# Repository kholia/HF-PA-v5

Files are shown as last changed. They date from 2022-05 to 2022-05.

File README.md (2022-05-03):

### HF-PA-v5

VU3CER's Robust `Class-D HF PA` for https://github.com/kholia/Easy-Digital-Beacons-v1
project for 40-20-17-15-10 bands.

For extra fun, use this PA with https://github.com/kholia/HF-Balcony-Antenna-System.

This design aspires to be the standard mW-to-QRP-Gallon HF PA in the ~600 INR
(8 USD) design space. Well, it does much more than QRP now...

Design Constraints:

- PCB is to be homebrewed.

- Only one PCB layer (side) is available for routing work.

- IRF510 MOSFET needs to be on an edge to allow usage of heatsinks.

- Typical external linears (e.g. `PA150 HF Linear Amp`) need 2W minimum to
  function. So we need a minimum of 2W of RF output from our design. Even at
  28 MHz.

- Minimal part count is strongly preferred. Low cost, and ease of availability
  are strong driving and deciding factors.

  The cost of this entire HF-PA-v5 system is less than one RD16HHF1 MOSFET ;)

- Reproducibility is a MUST! We focus a lot on this aspect by documenting each,
  and every detail possible.

- Repairability in the field is a MUST!

  Dhiru's finding: Repairing homebrewed PCBs is so much easier, and fun than
  reworking commercial `lead-free` PTH PCBs.

- No moving mechanical parts are allowed in the design - this rules out usage
  of (failure-prone) active cooling options like fans.

- We do NOT like the robustness of QCX, QDX, uSDX PAs. Removing heat from TO-92
  devices in a reliable way is not a trivial problem.

Note 0: All screenshots are clickable and zoomable.

Input: Few milliwatts is fine. Note: Si5351's output is around 8-10mW.

Output: See https://github.com/kholia/HF-PA-v4 for results.

Note 1: The output power is software controllable (via `PWM grounding`) for
flexibility.

Note 2: The idea behind making these (and my other) design notes publicly
available is to deliver REPRODUCIBLE, flexible, home-brewable, standardized,
reasonable, and cost-effective solutions for some common problems. I include
many references, simulations, and notes in my projects to enable you to do your
own (better) designs - do share them ;)

Robustness Notes:

- Ensure that the IRF510 is fastened securely to the heat sink.

  Use lock washers, and thermal epoxy adhesive to ensure good mechanical
  contact.

- We recommend operating at 24v instead of >= 29v.

Please see the older https://github.com/kholia/HF-PA-v2 project for the
power-supply (over-current protected), and LPF designs.

Schematic:

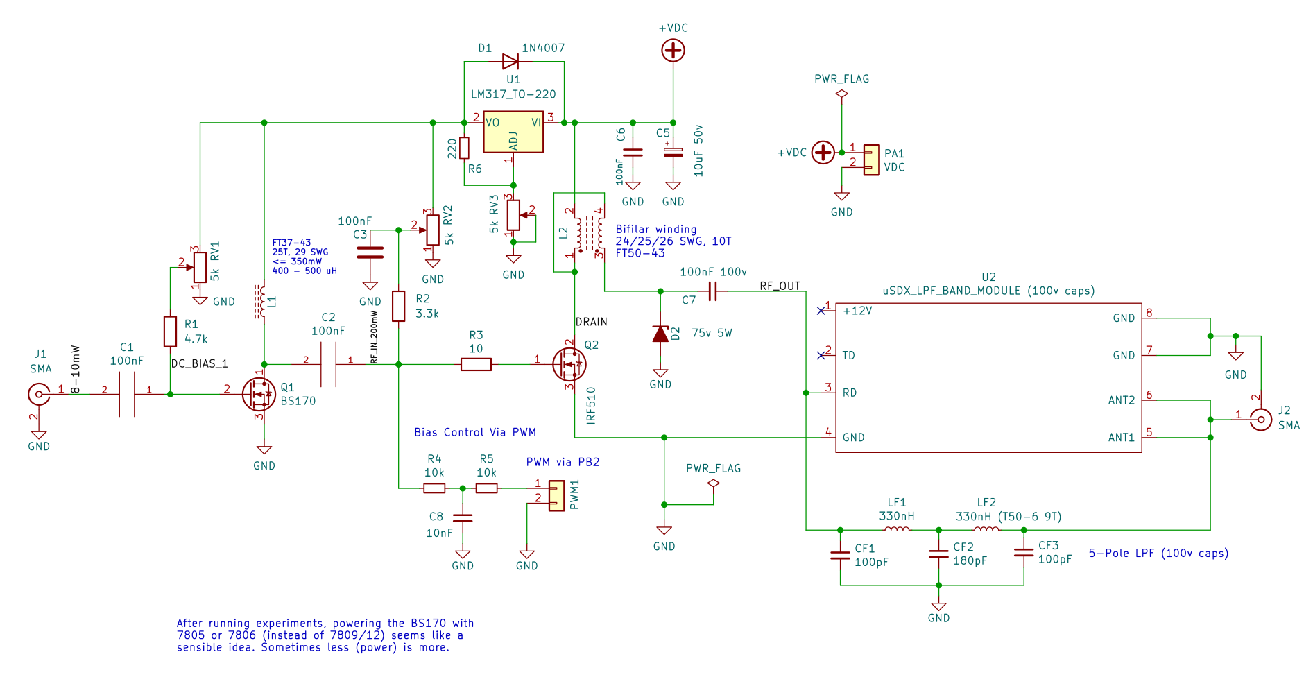
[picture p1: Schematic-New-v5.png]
Schematic


PCB rendering (v5):

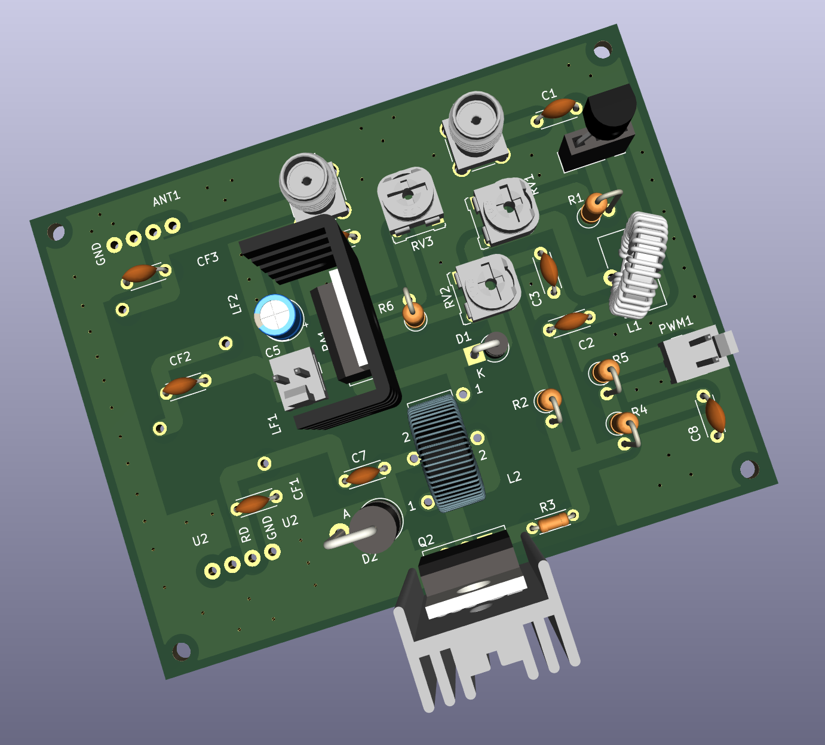
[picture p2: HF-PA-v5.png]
HF-PA-v5


Homebrew version of the same PCB:

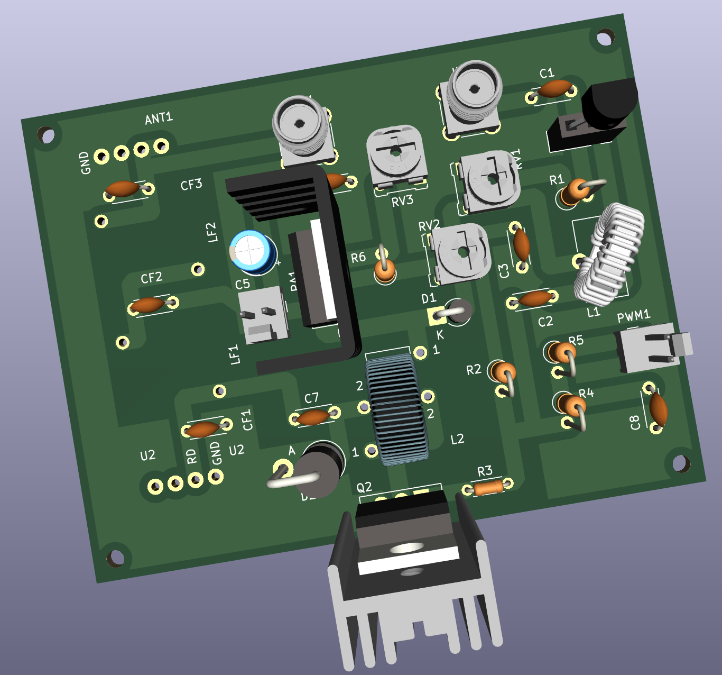
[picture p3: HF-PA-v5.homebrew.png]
HF-PA-v5 Homebrew Version


Note 3: The HF PA is connected to a 20m dipole over 55 meters of HLF-200 coax.

Note 4: The PCB is done using [KiCad 6.x](https://www.kicad.org/download/) - a
free, and open EDA software.

Note 5: This PA can be homebrewed from scratch in around 4 to 6 hours (one
afternoon, and an evening).

#### Notes

[From QRP Labs] Si5351A outputs a 3.3v square wave. The power output of Si5351A
is around 8-10mW (10 dBm). The BS170 based driver circuit amplifies this to
~200mW (23 dBm) for a gain of around 13 dB. The IRF510 finals provide a gain of
around 14dB and produce around 5W of RF power.

Input drive matters the most in getting good RF output from IRF510. This is
precisely what Si5351A lacks (which is perfectly fine), and why the BS170
driver stage is necessary.

Important: Don't exceed the IRF510's gate limit of 1-2W. Keep the output of the
BS170 driver in check, and within the limits of IRF510.

For safety, keep the output of BS170 less than 22 or 23 Vpp by controlling the
BS170 PA voltage (via the LM317 trimpot).

#### PA tuning process

- Remove the BS170 and IRF510 MOSFETS from their sockets.

- Set DC gate bias for BS170 to 0v. Now increase the bias (via trimpot) until
  the current consumption increases slightly (QRP Labs' process).

  You can also start by setting the gate bias to 2v directly ;)

  The final bias value can be around 2.1v to 2.2v in many cases.

- For IRF510, set gate bias to 3v. This ensures that IRF510 isn't turned ON -
  double-check this by monitoring the power consumption.

- Connect the MOSFET back, and measure RF output. Happy with the output power? -
  If yes, you are done else follow the next steps.

- Remove the MOSFET, increase the gate bias voltage in very small increments
  (0.1v types).

- Connect the MOSFET back, and measure power consumption without any RF input.
  Ensure that MOSFET remains OFF without any RF input.

- Apply RF input, and measure RF output.

- Repeat these steps as needed.

The [QRP Labs' procedure for bias adjustment](https://www.qrp-labs.com/images/pa/pa_simple_assembly_A4.pdf) and [this document](https://www.qrp-labs.com/images/ultimate3s/assembly_u3s.pdf) seem to have a better description of this process.

#### PA BOM

- 1 x IRF510 (Genuine Vishay parts are tried-and-tested) - 22 to 50 INR

  - The `SEC` (`SEC Electronics Inc`) branded IRF510(s) also work great!

  - The `SEC IRF510` can perform even better than Vishay's version. This
    particular result will vary between different product batches.

  - IRF510s with `International Rectifier` branding are most likely fake or
    "new old stock" if you are very lucky!

    Note: IR and Infineon have stopped manufacturing IRF510 MOSFETs.

  - AliExpress IRF510(s) are likely to be fake

  - The IR IRF510 gave ~3W versus 5.2W+ from SEC IRF510 versus ~5W from
    Vishay's IRF510!

    Note: The gate threshold voltage can vary even between two samples picked
    from the same manufacturer!

  - The Cgs ("gate capacitance") of a fake IRF510 is typically more than 1000pF
    on a LCR-T4 meter. This value is around ~400pF for genuine IRF510 parts on
    a LCR-T4 meter.

  - Some of the fake IRF510(s) cause a short in the power supply chain
    resulting in bad things happening (TM).

    I was not aware of this problem a few years ago, and was wondering why the
    power supply fuse was blowing in a uBITX I was repairing. I didn't have the
    LCR-T4 meter back then.

  - Ensure proper sourcing (trusted supply chain, etc) to get genuine parts

- All resistors should be MFR!

- BS170 MOSFET - 9 to 15 INR

- 3 x 4.7k Preset (Potentiometer) RM-065 - 20 INR

  - It is easier to get 5k (502) trimpots

- 1 x 3.3k 0.25W MFR - 2 INR

- 1 x 4.7k 0.25W MFR - 2 INR

- 1 x 220 0.25W MFR - 2 INR

- 1 x 10 Ohm 0.25W MFR - 2 INR

- [Optional] 2 x 10k Ohm - 0.25W Metal Film Resistor - 5 INR

- A very large heat sink - 50 to 175 INR - larger heatsink is better!

- Regulator heat sink - https://etstore.in/index.php/product/aluminium-u-type-heat-sink/ - < 5 INR

- 1 x LM317 (TO-220 package) Voltage Regulator - 18 INR

- 1 x 1N4001 (or 1N4007) diode for regulator protection - 2 INR

- 2 x SMA connectors (Vertical PCB mount) - 42 INR

- 1 x 10uF 50v Electrolytic Capacitor - 3 INR

- 4 x 100nF (104) 50v MLCC - 20 INR

- 1 x 100nF (104) 100v MLCC - 20 INR

- 1 x FT37-43 (Black Toroid, Fair-Rite 5943000201) - less than 25 INR (handles <= 350mW only)

- 1 x FT50-43 (Larger Black Toroid, Fair-Rite 5943000301) - less than 32 INR

- Misc: Relimate Connectors, Glass Epoxy Copper Clad Board (PCB), Various
  Consumables (~100 INR), SMA cables for testing, RF adapter (SMA Male to
  SO-239), M3 nuts and screws, TO-220 insulator kit

- Tools: LCR-T4 Meter (for measuring things), RF Power Meter

- Optional power supply: LM50-20B24 Mornsun SMPS - 24V 2.2A - 52.8W AC/DC SMPS - 700 INR

- Optional PPTC fuse

- PA Total Cost: Less than 600 INR

#### Power Supply + LPF BOM

See the following projects:

- https://github.com/kholia/HF-PA-v2
- https://github.com/kholia/HF-PA-v3
- https://github.com/kholia/HF-PA-v4
- 2 x 100 pF (50/100v)
- 1 x 180 pF (50/100v)
- 2 x T50-6 (Yellow Iron Dust code) toroids
- 25 SWG Winding Wire

Note: For LPF, use C0G 100v rated caps!

#### BOM + Equipment Sources

- https://www.semikart.com/ (IRF510, BS170, 100v NP0 LPF caps - Kemet and others)

  - 100v NP0 LPF caps from `Multicomp Pro` brand seem pretty cost-effective

  - 1N5374B 75V 5W Zener Diode (optional - for SWR protection)

  - https://www.semikart.com/search/5943000301 (FT50-43 toroid)

  - https://www.semikart.com/search/5943000201 (FT37-43 toroid)

- https://www.dnatechindia.com/ (Vishay IRF510) - send them an email to confirm
  the brand you are going to get!

- https://rarecomponents.com (BS170)

- https://www.electronicscomp.com/

  - Regular caps, ST voltage regulators

  - Female berg strip (2.54mm pitch)

  - PCB Etching Powder - FECL3 - Ferric-Ferrous Chloride

- https://www.electroncomponents.com/ (transistors, connectors, consumables, misc)

  - https://www.electroncomponents.com/BS170-N-channel-Switching-FET

  - https://www.electroncomponents.com/LM317-Adjustable-Regulator

  - https://www.electroncomponents.com/1N4001

  - https://www.electroncomponents.com/mica-insulator-to-220-set-kit

- https://www.sunrom.com/ (regular ceramic caps, SMA connectors)

- https://projectpoint.in/

  - Transistors, regular caps, voltage regulators, pots / trimmers, MFR resistors, misc

  - 2-Pin High Quality Relimate Connectors (all those 2-pin headers are actually Relimate Connectors)

  - Copper Magnetic Winding Wire - 29 SWG and 25 SWG

  - LM317 voltage regulator

  - 3-Pin Relimate Cable Female to Female (High Quality 2500mA) - 'TO-220 socket'

  - 2-Pin Relimate Cable Female (High Quality 2500mA) - for power

  - 2-Pin Relimate Male Header

- Semikart, eBay (`gr_makis`) - Toroids

- https://www.onlinetps.com/shop/ ('IR branded' IRF510 - not recommended at all - avoid!)

- https://www.electronicscomp.com/ (they ship 'IR branded' IRF510s at times, so avoid)

- https://www.ktron.in/

  - https://www.ktron.in/product/lm317-regulator-ic-to-220/

  - https://www.ktron.in/product/sma-connector-straight/

- [LCR-T4 LCR Meter](https://www.techtonics.in/lcr-t4-12864-lcd-graphical-transistor-tester-resistance-capacitance-esr-scr-meter)

- https://robu.in/ (voltage boost module)

- https://www.ktron.in/product/40x1-round-header-female-2mm-pitch/

  Sunrom also has these.

- TO-92 heatsink - DIY or get `AAVID THERMALLOY 575200B00000G TO-92 Package` heatsink

- Household items

  - Hot iron ("press")

  - Laser printer - I use the `toner transfer using hot iron` method for making PCBs at home

- See https://github.com/kholia/HF-PA-v2 and https://github.com/kholia/HF-PA-v3 sources too

Note for international buyers: The BOM can be carefully sourced via Mouser and DigiKey.

#### O(Current consumption)

The ESP8266 usually draws a peak current of about 250mA after it wakes up and
then more or less constantly draws around 70mA before it goes back to sleep.

DS3231 -> 5mA

Si5351 -> ~50 to 100mA

PA -> Less than 1 A (rms)

Upper bound -> 1.4A maximum.

#### Tips

MOSFETs are sensitive with regards to ESD and high soldering temperatures. Use
best practices when dealing with MOSFETs and perhaps always ;)

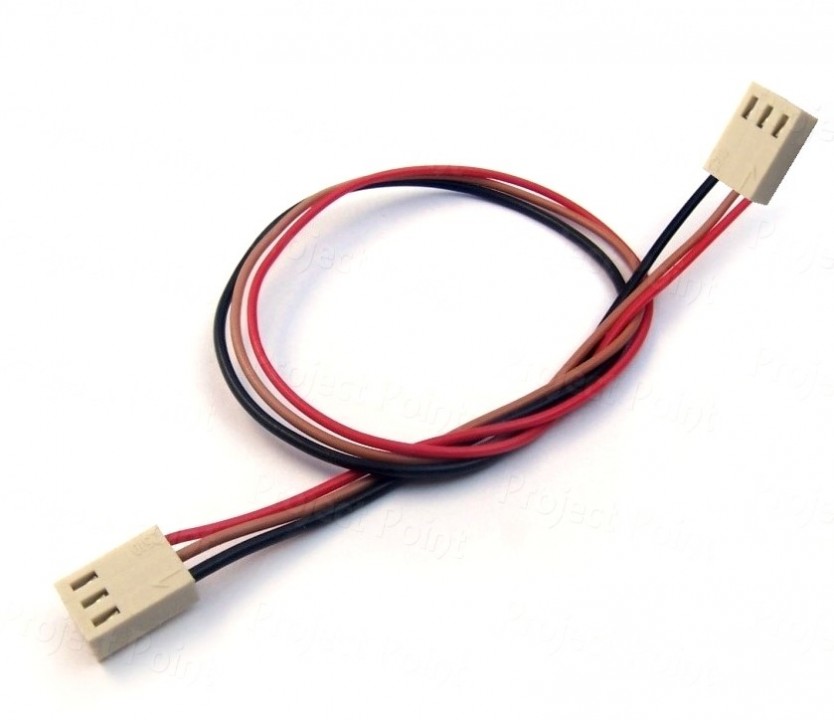
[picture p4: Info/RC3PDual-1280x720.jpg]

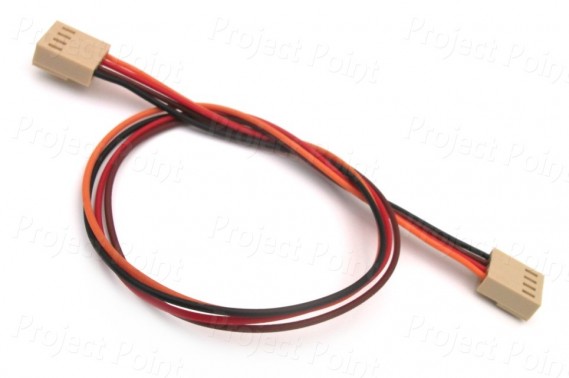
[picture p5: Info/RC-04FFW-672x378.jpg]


By using these `TO-220 Sockets`, we can easily support any MOSFET pinout. This
technique allows usage of `off-pcb` heat sinks with a lot of flexibility. It
also avoids common ESD + MOSFET problems as well. The gate bias can be easily
checked by safely removing the MOSFET from the TO-220 socket. Also, this socket
idea allows us to safely eliminate the LDO from the design.

Note: Keep the length of the `TO-220 Sockets` as short as possible.

Also, use a `SIP socket` (aka 40×1 Round Header Female Berg Strip) for the
BS170 MOSFET.

A burnt 78(L)05 regulator can easily eat up 4-5W of power by itself. If there
is no RF output but power is being consumed then check your linear regulator.

#### Mods

If you have 1-to-2 W of RF input drive available, then remove the BS170 driver
stage altogether. The rest of the circuit works as it is.

#### Future ideas

- Use a `PPTC fuse` in the PA voltage line (oscillations are a real problem,
  and can be nasty) - Sandeep Lohia (VU3SXT).

  [Alternate] For testing purposes, I am using a current-limited power supply.

- Add a `Type K Thermocouple` based temperature monitoring to ensure safety.

- Alternatively, use ACS712 to monitor the current consumption to ensure
  safety.

- Better still, use a power supply (module) with constant current limiting.

- Add foldback current limiting - see `QRP Labs` docs.

- Add negative feedback - see `QRP Labs 10W HF Linear Power Amplifier` design.

#### References

See [References.md](./References.md).

#### Credits

This design uses ideas, and support from Hans Summers (G0UPL, QRP Labs), VU3SXT
(Sandeep Lohia), VU2ASH, Mr. Bhatnagar (VU2SPF), AC7LX, and PY2OHH.

Also see https://github.com/kholia/HF-PA-v3#credits and https://github.com/kholia/HF-PA-v2#credits.

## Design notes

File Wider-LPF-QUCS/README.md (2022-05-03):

180 pF can be replaced with 2 x 100 pF in parallel, if you don't have 180 pF
handy. 0.33 uH can be airwound or better use `9 turns` on T50-6 yellow toroid
(iron dust core) or `10 turns` on T37-6 yellow toroid (iron dust core).

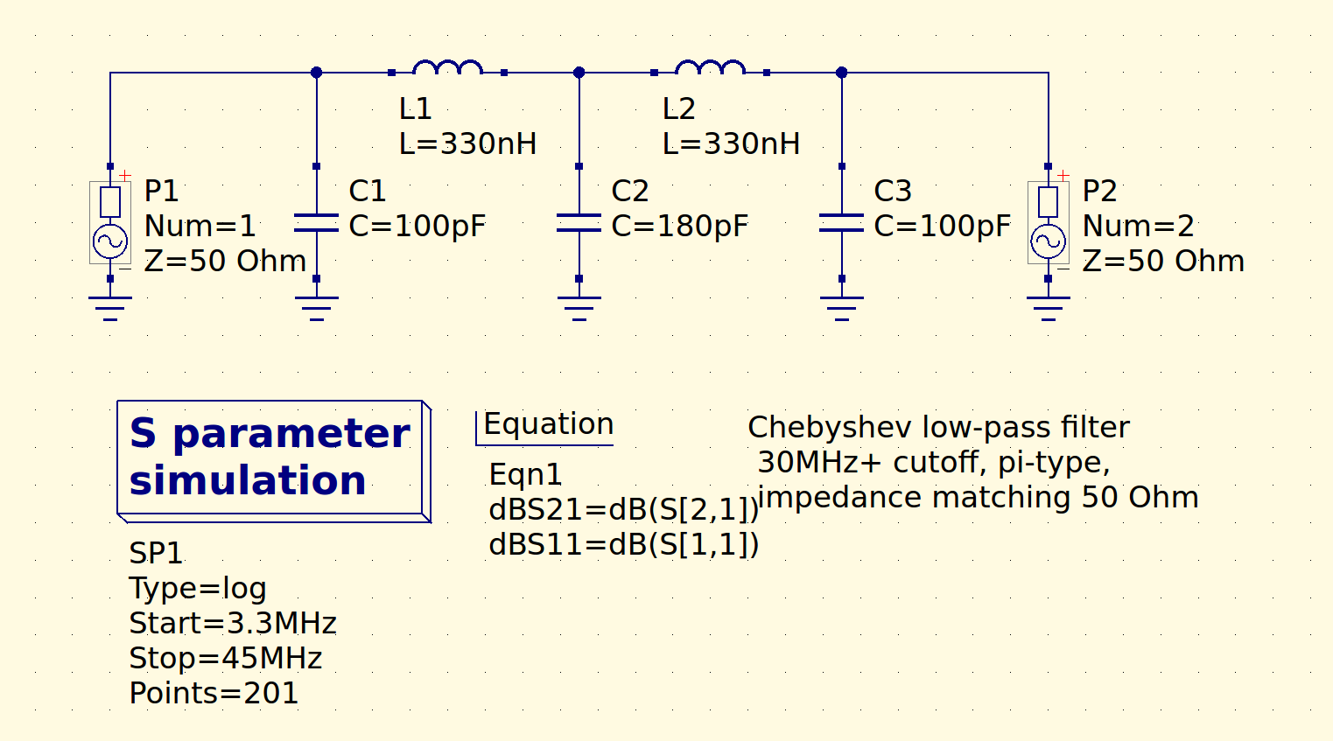
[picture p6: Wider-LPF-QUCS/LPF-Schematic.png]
Schematic


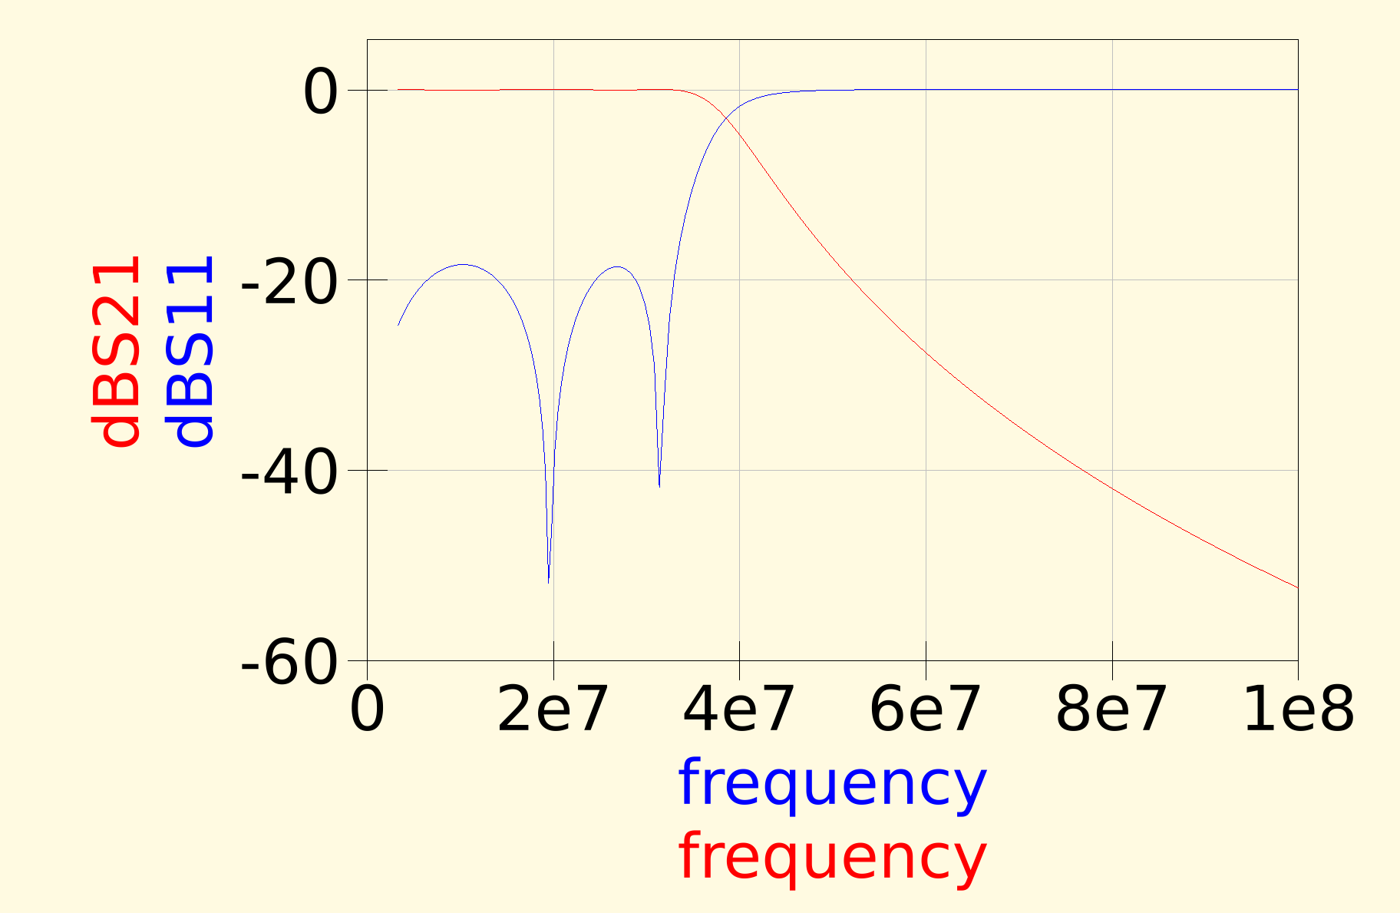
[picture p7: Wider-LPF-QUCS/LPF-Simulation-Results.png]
Results


Note: These filters were simulated with `QUCS` software.

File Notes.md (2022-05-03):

In general terms, the PCB industry considers an RF circuit board to be any high
frequency PCB that operates above 100MHz.

IRF510 - The device dissipates 43 watts so as long as the kit doesn't draw more
that about 3.5 amps max at 12 volts, it won't fail. At 5 watts and 50%
efficiency it won't draw more than 1 amp and  can handle full reflected SWR.

https://www.rapidonline.com/Catalogue/Search?Query=CDIL

LED Wemos D1 Mini - The built-in led is on pin D4, and it is inverted.

```
Z=Vcc2 / 2PO
In [7]: (22 * 22) / (2 * 5)
Out[7]: 48.4
```

```
[dhiru@zippy DS1054Z_screen_capture]$ python2 OscScreenGrabLAN.py png 192.168.1.16
Instrument ID: RIGOL TECHNOLOGIES,DS1054Z,DS1ZA203916662,00.04.04.SP3

Receiving screen capture...
Saved file: 'captures/DS1054Z_DS1ZA203916662_2021-09-21_18.23.17.png'
```

From the internet,

7805 -> Without an extra heatsink, you can burn off up to 2W. If you need more
current heatsinks are cheap and effective. Every 11 degrees Celsius cooler you
run your semiconductors, reliability doubles.

- Get the max die temperature from the regulator datasheet

- Get the Theta(j-a) number from the datasheet in degrees C per watt.

- Calculate the power dissipated by your device. Example: 9 volts in, 5 volts
  out at 1 amp would be 4 watts.

- Multiply the watts dissipated by Theta(j-a) to get the temperature rise.

- Add the temperature rise to the maximum ambient temperature the device will
  be exposed to.

- If the number computed in #5 is greater than the max die temperature, then
  you need to use a heatsink or some other way to actively
  cool the device.

- If you use a heatsink, you will use a slightly different set of calculations
  involving the regulator's Theta(j-c) (Not Theta(j-a).

For a 7805 it's 65 C/W junction to air.

This means that if the regulator produces 1 W of heat, the die will be 65
degrees C hotter than the ambient air.  The maximum operating temperature is
125 C. Pune temperature (inside the case) -> 70 c.

Can dissipate -> (125 - 70) / 65 -> 0.84 watts. P = VI. This allows around
100mA of current when input voltage is 14v.

Note: Try the `Small mark` option instead of the regular `Real drill` option in
KiCad.

Note 2: Set track width to >= 2.2mm in KiCad - try to work with this. For the
copper pour, set clearance to 0.850.

...

LTspice notes:

- Download LTspice (Google "Download LTspice"). It's free.

- `~/Documents/LTspiceXVII/lib`

  Extract external components to this path.

- Extract the `contents` of `LTspiceXVII_2019Jan29.zip` (Google for this file) properly to `~/Documents/LTspiceXVII` path.

...

From Daniel Alonso,

A unnecessarily large L doesn't do harm by itself, but the 'series' self
resonant frequencies decrease when you increase the turns count. A
rule-of-thumb is choosing an inductive reactance of 4 times the load
resistance, at the lower frequency. Supposing the circuit is to drive a 50 ohm
load, to get a reactance of 200 ohms at 3.5MHz you will need L = 200/(2*pi*3.5)
= 9.1uH. Or if you are more conservative with 10 times the R, it should be
22.7uH.

From Sandeep Lohia,

Inductive reactance on primary side is critical and the magic number is `36`.

```
36 ÷ lowest operating frequency.
36 ÷ 7 = 5 uh
```

Inductance on secondary not critical but turns ratio is...

...

From Farhan,

At 25 watts, the RF peak voltage is 50v. This is easily handled by the regular
disc ceramics rated for 60v. Higher power will require expensive capacitors.

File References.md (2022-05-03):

#### References

- http://shop.qrp-labs.com/pa
- http://shop.qrp-labs.com/kits/U3S
- https://github.com/kholia/HF-PA-v3/
- https://github.com/kholia/HF-PA-v2/
- https://github.com/agustinmartino/wsjt_transceiver
- https://www.qrp-labs.com/ultimate3/u3info/u3sbifilar.html
- https://www.qsl.net/py2ohh/trx/peanuts/peanuts.html
- https://www.qsl.net/py2ohh/trx/lpf100w/lpf100w.html (LPF filters)
- http://hyse.org/pdf/www.aoc.nrao.edu/~pharden/hobby/_ClassDEF1.pdf
- http://hyse.org/pdf/www.aoc.nrao.edu/~pharden/hobby/_ClassDEF2.pdf
- http://thestone.zone/radio/2020/12/13/multi-watt-amplifier.html
- http://thestone.zone/radio/2020/12/18/gate-driver-amplifier.html
- http://thestone.zone/radio/2021/01/14/capacitors.html
- http://thestone.zone/radio/2021/01/16/minor-enhancements.html
- https://www.g0kla.com/scpa/SimpleCheapPA.php
- https://www.linkedin.com/pulse/rf-pcb-design-rules-manufacturing-process-lisa-chu/
- http://thestone.zone/radio/2021/06/04/attenuator.html
- http://thestone.zone/radio/2021/06/05/power-amplifier.html
- https://on7dq.blogspot.com/2020/12/qcx-mini-measurements.html
- https://www.random-science-tools.com/electronics/dBm-Watts-volts.htm
- https://www.mitsubishielectric.com/semiconductors/php/oSearch.php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
- http://www.carnut.info/WSPR_Tx/WSPR_Tx.htm
- https://sites.google.com/view/andy-g0ftd/iron-fist-transmitter
- https://www.dj0abr.de/english/technik/dds/pa.htm
- https://www.qsl.net/py2ohh/
- https://hf5l.pl/en/transceiver-usdx-with-arduino-nano/#
- http://www.m0rzf.co.uk/PA_Old/index.html
- https://vk3hn.wordpress.com/2019/05/01/summit-prowler-6-a-pocket-sized-ssb-cw-transceiver-for-80-40-30-and-20m/
- http://am-transmitter.blogspot.com/2014/07/protect-your-mosfet-final-stage.html
- https://electronics.stackexchange.com/questions/11583/grounding-a-soldering-iron
- http://hfsignals.blogspot.com/p/25-watt-linear-for-40-and-20.html
- http://www.norcalqrp.org/nb6mminiboots.htm
- https://github.com/RoGeorge/DS1054Z_screen_capture
- https://github.com/profdc9/QRPAmplifier

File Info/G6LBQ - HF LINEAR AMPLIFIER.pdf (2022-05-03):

# G6LBQ - HF LINEAR AMPLIFIER

# Last edited 10th April 2013

### Introduction

The G6LBQ HF Linear Amplifier is a reproducible 20Watt PA module using rugged Mitsubishi RF Mosfet's. There are many advantage of using genuine RF devices over cheaper general purpose power Mosfet's like the IRF510 devices commonly used in a lot of home-brew projects:

- 12 Volt drain voltage unlike IRF510's which typically require 24 Volts to operate well.
- Device source is connected directly to the metal mounting tab providing easier mounting options and more efficient thermal transfer.
- Flatter gain response across the HF frequency spectrum.
- Much better handling of poor mismatches.

The Linear Amplifier module has been designed to interface perfectly with the G6LBQ multiband transceiver but can also be used with the Bitx3 or any other transceiver project.

The RF drive level required for the module is around 10mw for an output power of 10 Watts. The maximum output that the module can deliver is 16 to 20 watts depending on bias and drive level. The amplifier has a front end 50 Ohms PI matching network which can be reconfigured to allow higher drive power levels if required providing greater flexibility for use with other projects.

There are many examples of proven designs using the Mitsubishi RF Mosfet's on the internet and also in various publications, the information I collected was used to aid in the design and construction of the G6LBQ amplifier module.

Currently the PCB artwork for the amplifier is not freely available however should you wish to make your own PCB for the module I have made the circuit diagram available in the G6LBQ Yahoo Group which can be found at http://uk.groups.yahoo.com/group/g6lbq/ look under the files section and then navigate to the G6LBQ Bitx folder.

As with all my other Multi-band BitX modules a ready made PCB is available from DX KITS the sole worldwide distributor. The PCB is a professionally manufactured Glass Epoxy FR4 board, pre drilled, tinned, solder masked and screen printed to aid assembly. To purchase a PCB please visit http://www.dxkits.com

### Page 1

COMPONENT LIST
Quantity | Description | Function
21 | 100nf Ceramic Disc or Multilayer 50-100 Volt – 5mm Lead Pitch | Coupling & Decoupling
2 | 10nf Ceramic Disc or Multilayer 50-100 Volt – 5mm Lead Pitch | Coupling & Decoupling
2 | 1uf Electrolytic 25-63 Volt – 2.54mm Lead Pitch | Decoupling
1 | 100uf Electrolytic 25-35 Volt – 5mm Lead Pitch | Supply LF Decoupling
1 | 150pF Multilayer Ceramic or Silver Mica 100 Volt – Lead Pitch Form To Suit | Frequency Tuning.
2 | 430 Ohm 0.25W Resistors | Input Attenuator/Matching.
2 | 10R 0.25W Resistors | Input Attenuator/Matching & 5Volt Regulator supply feed resistor.
1 | 10K 0.25W Resistor | BC640 emitter base resistor.
1 | 1K 0.25W Resistors | BC640 base resistor.
1 | 2K2 0.25W Resistor | 2N3904 base resistor.
1 | 2K7 0.25W Resistor | 78L05 load resistor.
1 | 470R 0.25W Resistor | Driver transistor bias feed resistor.
2 | 100R 0.25W Resistors | Output transistors bias feed resistor.
3 | 10K Horizontal Pre-sets | Driver/Output transistor bias setting.
1 | 560R 0.25W Resistor | Driver transistor feedback network.
2 | 680R 0.25W Resistors | Output transistor feedback network.
1 | 6R8 0.5W Resistor | Driver transistor supply resistor.
2 | 2R2 0.25W Resistors | Output transistor Gate resistors.
1 | BC640 PNP Silicon Transistor | PSU series transistor feeding the 78L05 biasing regulator.
1 | 2N3904 NPN Silicon Transistor | Transmit bias switching transistor.
2 | 1N4001 General Purpose Diodes | Bias temp compensation.
1 | 1N4148 High Speed Switching Diode | Transient suppression for relays.
1 | 78L05 5Volt Positive Regulator | Bias voltage regulation.
1 | RD06HHF1 or RD16HHF1 RF Power Mosfet | Driver stage Mosfet transistor.
2 | RD16HHF1 RF Power Mosfet's | Output stage Mosfet transistors.
2 | Omron G5V-2 Two Pole Relays | Input/Output switching.
3 | BN43-202 Ferrite Balun core | RF Transformers.
2 | Ferroxcube VK200 Choke Inductors or FT50-43 torroids with 10 turns of 0.7mm copper enamel wire. You can also use large ferrite beads with 0.7mm wire passed through. | Supply decoupling chokes.

### Page 2

HARDWARE LIST
Quantity | Description | Function
5 | SMA PCB Sockets “See Page ” | RF Input/Output option 1
5 | 2 Pin Molex 0.1 pitch headers “See Page “ | RF Input/Output option 2
1 | 2 Pin Molex 0.1 pitch headers | Transmit switch line connection
1 | 2 Pole PCB Screw Terminal Block | PSU connection
1 | Heat-sink | Heat dissipater for RF Mosfet's
1 | 0.5mm Copper enamel covered wire | For winding transformers
1 | 0.7mm Copper enamel covered wire | Only needed if winding L1 & L2 as opposed to using pre made inductors.

# BUILDING THE G6LBQ HF LINEAR AMPLIFIER

Construction of the G6LBQ HF Linear Amplifier should not prove difficult and is one of the easiest modules to construct in the multi-band transceiver.

Before commencing construction carry out an inventory of all parts and optional hardware.

Please visit the BitX Yahoo Group at http://uk.groups.yahoo.com/group/g6lbq/ and make sure you have the latest documentation before commencing building. There is a folder in the files section of the group titled G6LBQ Bitx and all files relating to the amplifier can be found there.

There is no specific order of construction but I suggest all the resistors and capacitors be soldered to the PCB first. The last components to be installed should be the three RF Mosfet's as these could be damaged if the device legs are allowed to be bent with unnecessary disturbance during construction.

The finished PCB looks like this:

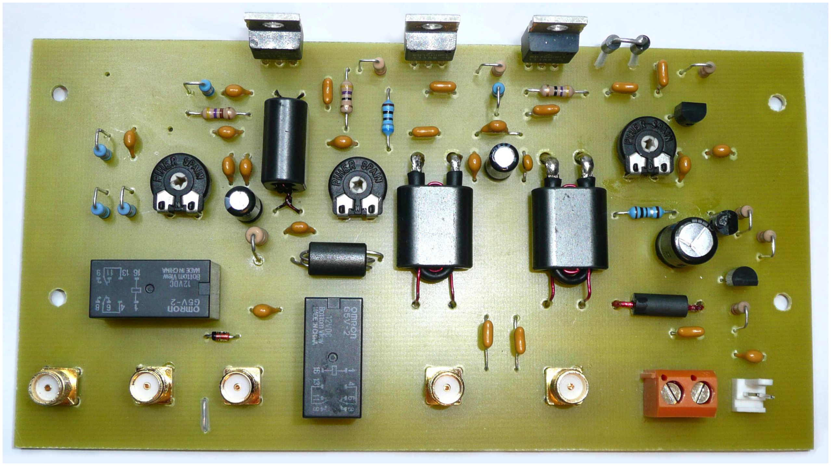
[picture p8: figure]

### Page 3

# PCB LAYOUT IMAGE

### This image illustrates all the component locations to aid construction NOTE A wire link must be fitted at this location

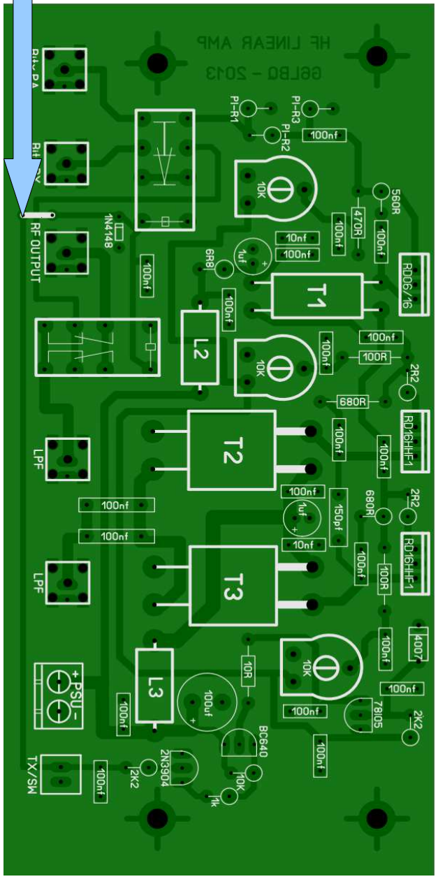
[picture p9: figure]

### Page 4

# WINDING THE TRANSFORMERS

The HF Linear Amplifier is equipped with three transformers which are wound on BN43-202 ferrite balun cores using 0.5mm Copper Enamelled Wire and short pieces of RG174 coax.

### T1 Driver Transformer

T1 is constructed by winding two lengths of 0.5mm enamel copper wire twisted together so there are 2 to 3

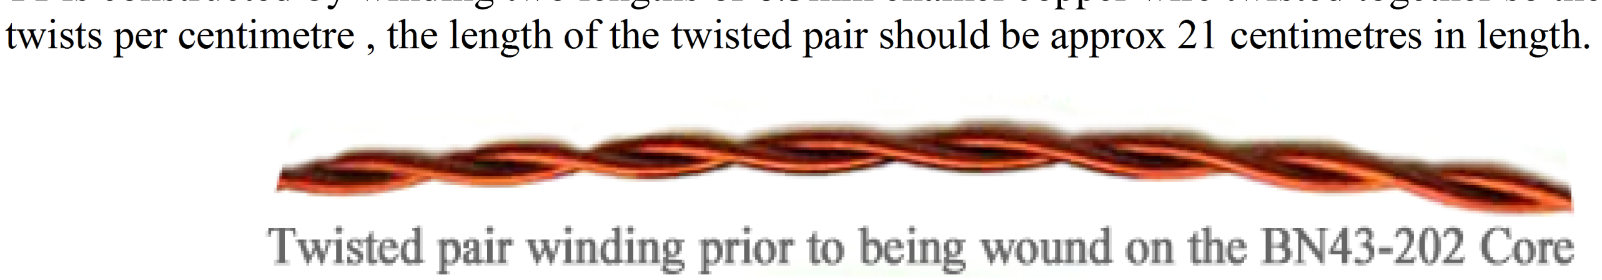
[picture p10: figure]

The twisted pair of wires must now pass through the BN43-202 balun cores so that it fills one hole in the core twice and the other three times (2 ½ Turns) this is illustrated below:

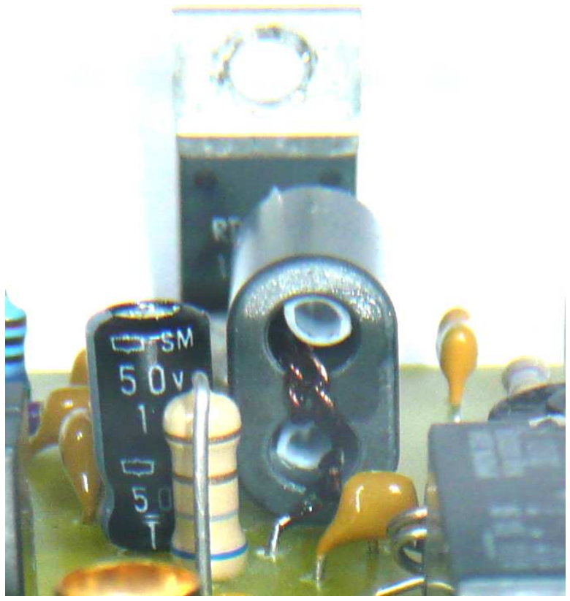
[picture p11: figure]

In the image above you can see that the top hole in the balun core has been filled with the twisted pair twice whilst the bottom hole in the core has been filled three times. The little pieces of white tubing inside the cores is only in place to help highlight the windings and are not required!

The transformer can be inserted into the PCB either way round as it is symmetrical.

### Page 5

### T2 & T3 Output Transformers

T2 & 3 are identical and are constructed with individual primary and secondary windings. The primary winding is created from a short length of RG174 coax and the secondary with a length of 0.5 enamel copper wire.

Begin by winding the secondary side of the transformers with 4 turns of copper enamel wire so that the windings are nice and tight against the centre of the BN43-202 core as illustrated below:

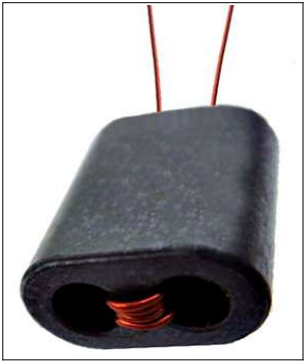
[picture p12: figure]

To make the primary winding take approximately 10cms of RG174 coax and remove 2cm of the outer plastic sheathing from one end, separate the exposed outer braid to reveal the centre coax core, the centre core can make threading the coax through the binocular holes tight so it is discarded by simply pulling it free from the rest of the cable. With the centre core of the coax removed chop off the 2cm of exposed braid as this will make it easier to thread the coax through the binocular holes. Thread the coax through the core and prepare as illustrated below:

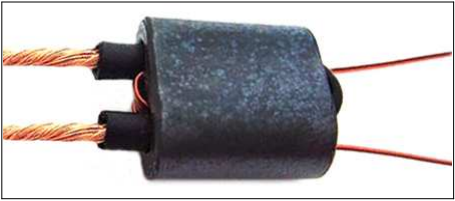
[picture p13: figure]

With the three transformers wound it is important to clean off the enamel coating from the copper wires ends prior to PCB installation. Use a sharp blade to do this then pre tin all of the cleaned wire ends, DO NOT TIN THE RG174 COAX prior to installing into the PCB as this will make it difficult to form the wire ends to the PCB holes.

### Page 6

# MOSFET BIAS TEMPERATURE COMPENSATION

The following image illustrates the two 1N4001 Diodes used for the bias compensation, these Diodes must be mounted on the same heat-sink as the RF Mosfets and secured in place.

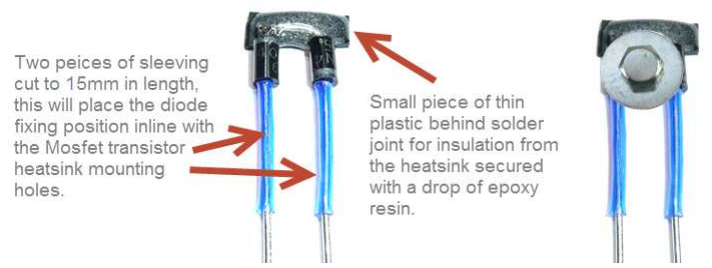
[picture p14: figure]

With a suitable aluminium enclosure it may be possible to get enough heat dissipation by bolting the RF Mosfet's and Diodes directly to the case. Care must be taken when bolting the Diodes down, they must be lightly secured in place but make contact with the aluminium dissipater, do not apply to much pressure against the Diodes or damage may occur!. A suitable washer must be included with the fixing screw to cover the Diode bodies and aid contact with the heat dissipater.

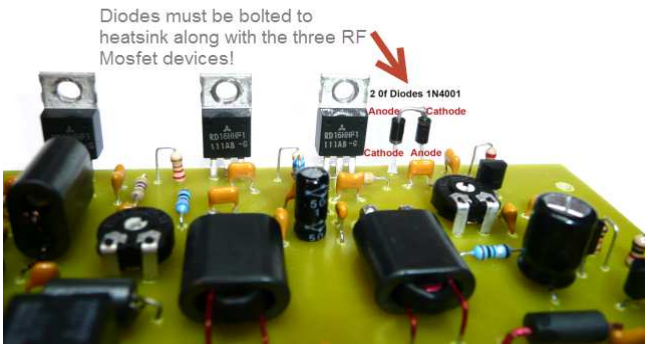
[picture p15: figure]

Attach the RF Mosfet's and Diodes to the heat-sink with a thin layer of heat-sink compound and then carefully check around the Diodes to make sure no part of the fixing screw or component legs are making contact with the aluminium dissipater.

### Page 7

# INITIAL TESTING STAGE

## IMPORTANT Do not apply power to the finished module without a suitable heat-sink attached to the RF Mosfet's & bias compensation Diodes!

### Preparing for initial testing and bias adjustment

Before applying any power to the finished module check the PCB for correct component locations, solder splashes and shorts.

The three 10K pre-set resistors that control the biasing must be initially set so the Mosfet's transistors are unbiased, observe the image below and set all three pre-sets anticlockwise:

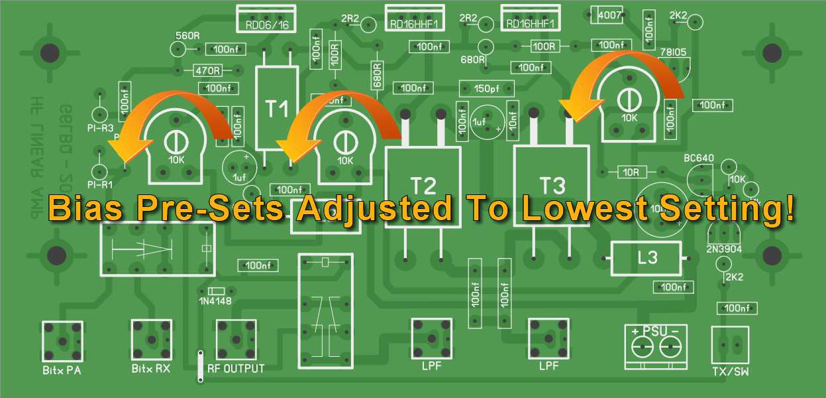
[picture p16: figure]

With the three 10K pre-sets adjusted as above and a suitable heat-sink in place we are now ready to carry out some initial tests and bias alignment. No RF input signal, low pass filters or output load are required during the initial test and bias alignment stages.

### First Test - Standby Idle Current

With a 12 to 13.8 volt power supply connected to the amplifier the measured idle current should be approximately 35mA.

### Page 8

### Initial testing and bias adjustment continued

### Second Test – Transmit Mode Current

With a 12 to 13.8 volt power supply connected to the amplifier module we need to activate the TX/SW (transmit switch) circuit, this turns on the bias regulator and activates the signal path changeover relays. The illustration below shows the additional test link required to activate the transmit switch:

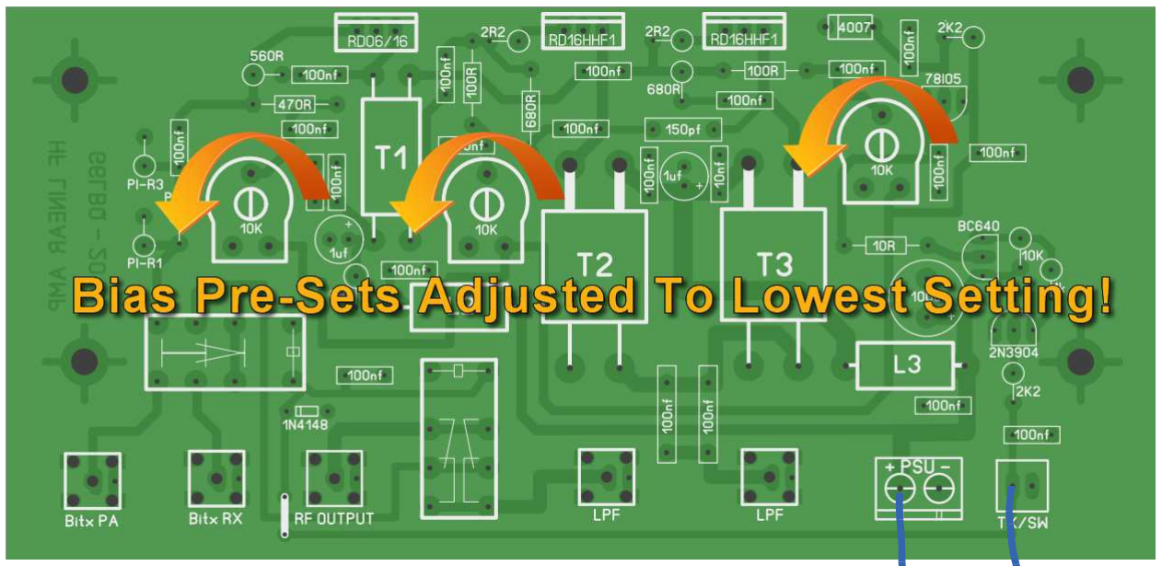
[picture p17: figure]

The transmit switch circuit is operated by + 13.8 Volts so in the illustration we are linking the switch straight terminal to the main power supply feed to force operation.

The measured current for this test should be approximately 120mA +/- 10%.

### Page 9

# DRIVER STAGE BIAS ADJUSTMENT

## IMPORTANT Do not apply power to the finished module without a suitable heatsink attached to the RF Mosfets & bias compensation Diodes!

### Setting the driver stage bias

The driver stage is biased to 125mA and the illustration below indicates which of the three pre-sets controls the driver stage bias:

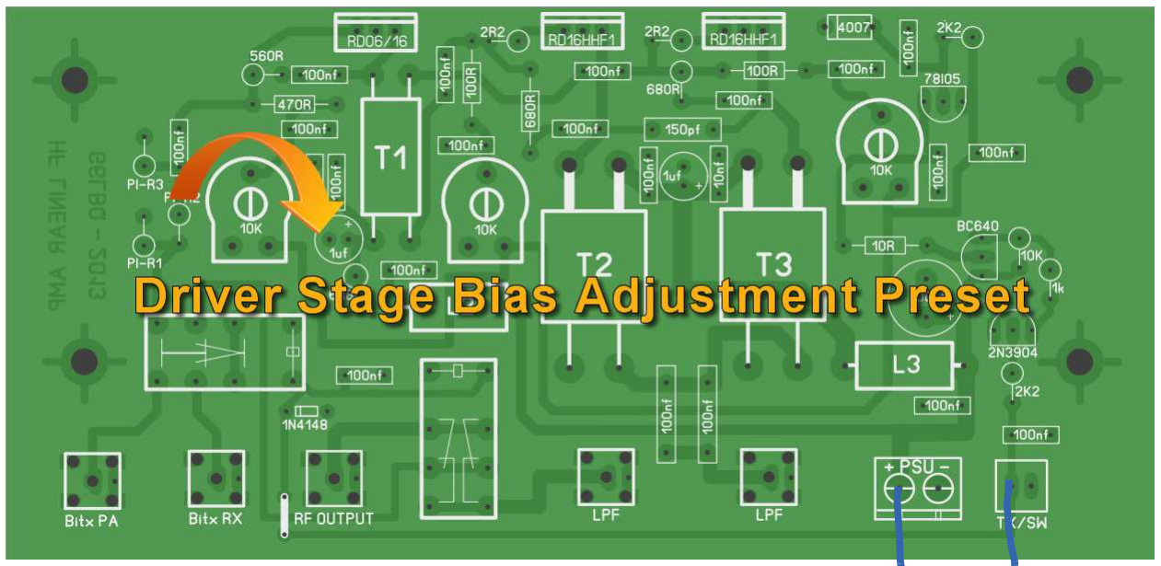
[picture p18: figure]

Whilst monitoring the current consumption of the amplifier slowly adjust the driver stage pre-set in the direction shown for a reading of 245mA, the driver stage is now biased.

### Page 10

# OUTPUT STAGE BIAS ADJUSTMENT

## IMPORTANT Do not apply power to the finished module without a suitable heat-sink attached to the RF Mosfets & bias compensation Diodes!

### Output stage bias adjustments

The final output stage consists of a pair of Mosfet devices each biased to 250ma. Using the illustration below the first output device is biased accordingly:

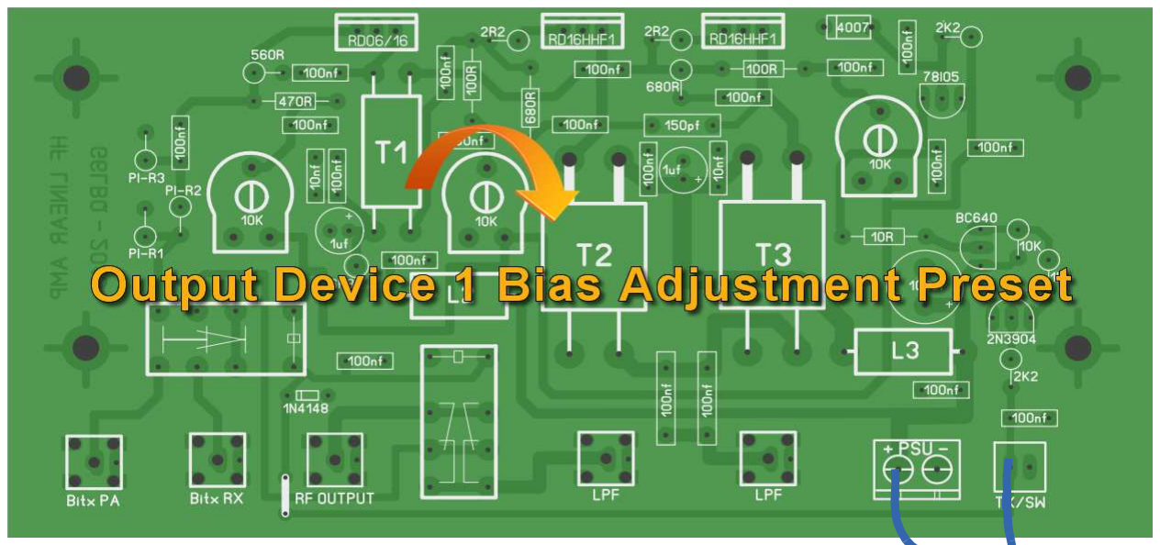
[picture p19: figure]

Whilst monitoring the current consumption of the amplifier slowly adjust the first output device pre-set in the direction shown for a reading of 495mA, the first output device is now biased.

Using the illustration below the second output device is biased accordingly:

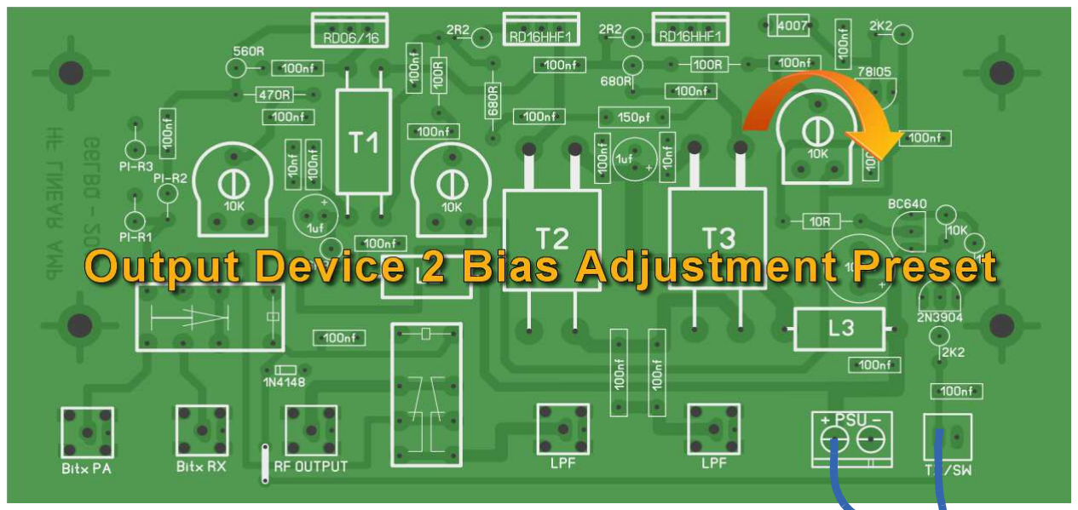
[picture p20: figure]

Whilst monitoring the current consumption of the amplifier slowly adjust the second output device pre-set in the direction shown for a reading of 745mA, this completes the bias setting procedure.

### Page 11

# A UNIVERSAL APPROACH

### Connectivity

The HF Linear amplifier was designed with a universal approach and is adaptable to many home-brew projects requiring a reliable, solid and reproduce-able module.

- The PCB has provision for various RF input/output connectivity, you can fit high quality SMA connectors, Molex connectors or just solder straight to the PCB.
- There are separate input connectors for receive and transmit making the module ideal for use with separate transmitters and receivers
- The module has a transmit switch line that removes the bias during receive mode thus conserving energy, ideal for battery portable operation!
- On-board input matching PI network/attenuator – this allows the module to be configured for a wide range of power input levels and allows control of the final output power.

### Heat-sinks

The output devices and bias compensation diodes are all mounted along the back edge of the PCB which offers great flexibility when sourcing a heat-sink, some aluminium project cases may also serve as a good enough heatsink on there own!.

### Transmit Switching

The amplifier was primarily designed to compliment my G6LBQ Multiband BitX transceiver so has positive going transmit switching, there is a 2 pin header on the PCB marked TX/SW.

### Page 12

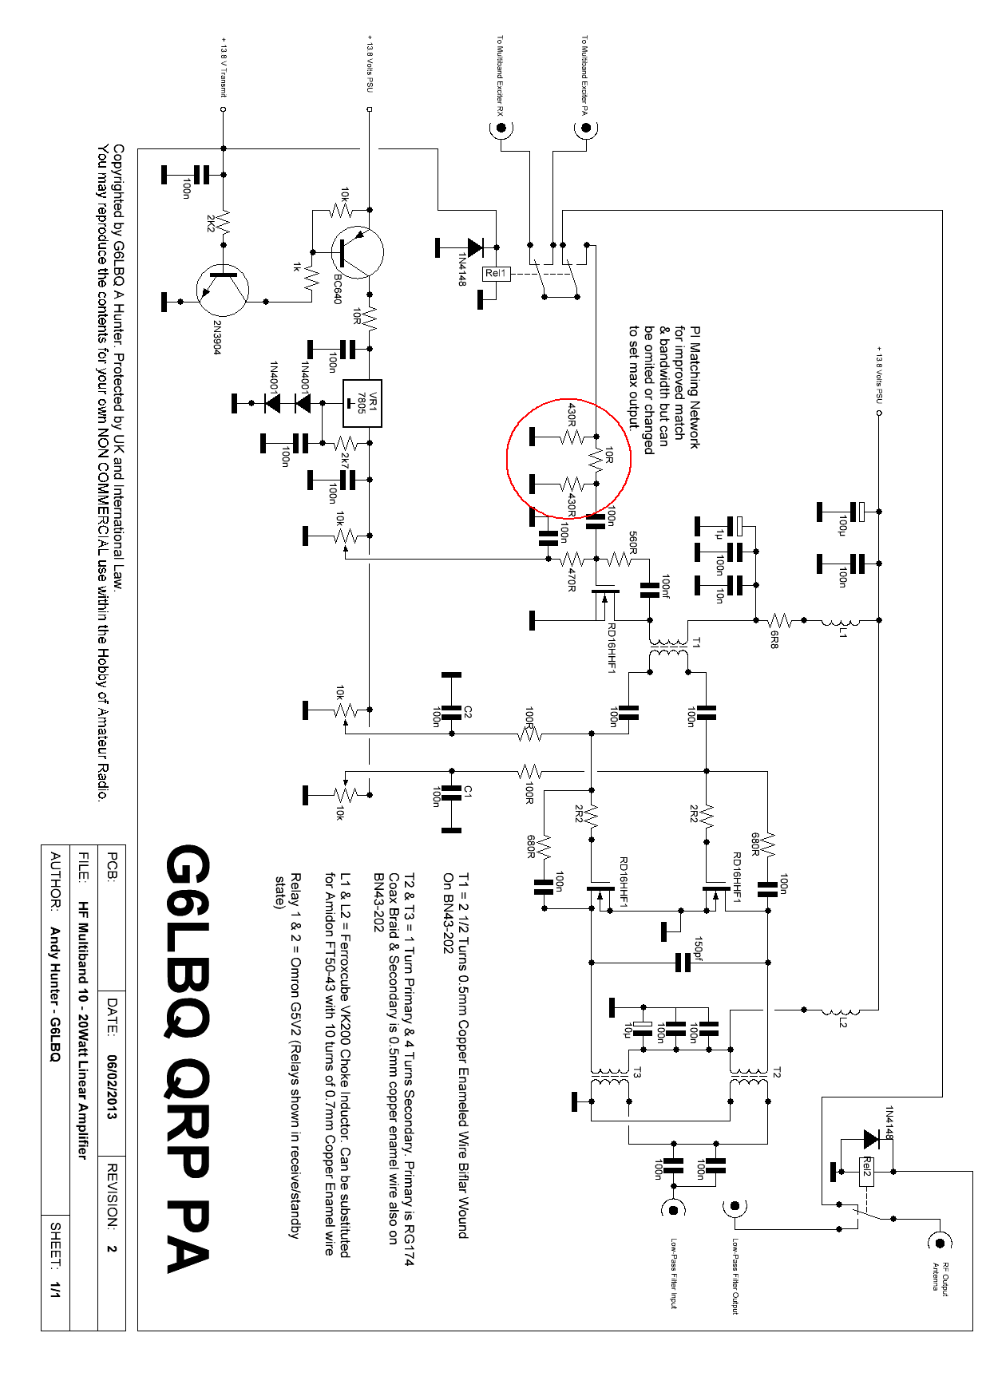
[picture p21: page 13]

### Page 12

# FINAL NOTES & AMMENDMANTS

This manual should provide sufficient information to construct the amplifier but if you have any questions during the build please post a message in the BitX Yahoo Group at http://uk.groups.yahoo.com/group/g6lbq/

It is recommended that the power supply feed to the amplifier be fused, a 2.5 Amp quick blow fuse should be adequate.

Copyrighted by G6LBQ A Hunter. Protected by UK and International Law.
You may reproduce the contents for your own NON COMMERCIAL use within the Hobby of Amateur Radio.
Page 13 | Last page

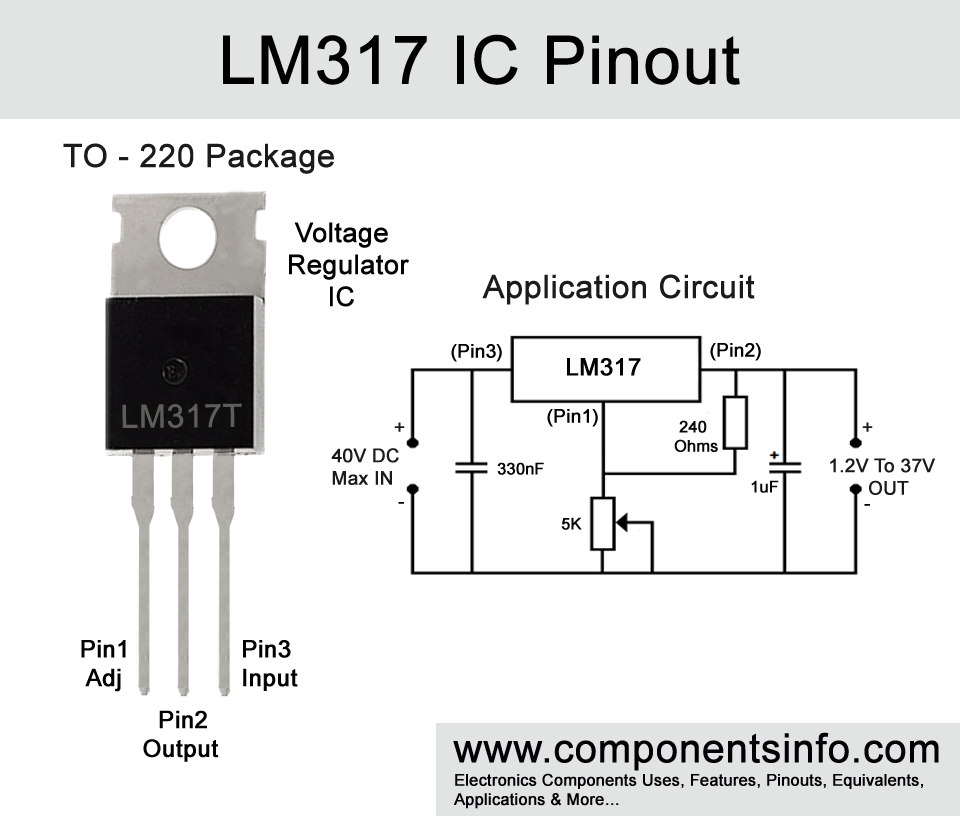
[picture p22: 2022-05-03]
datasheets/lm317-pinout-equivalent.gif

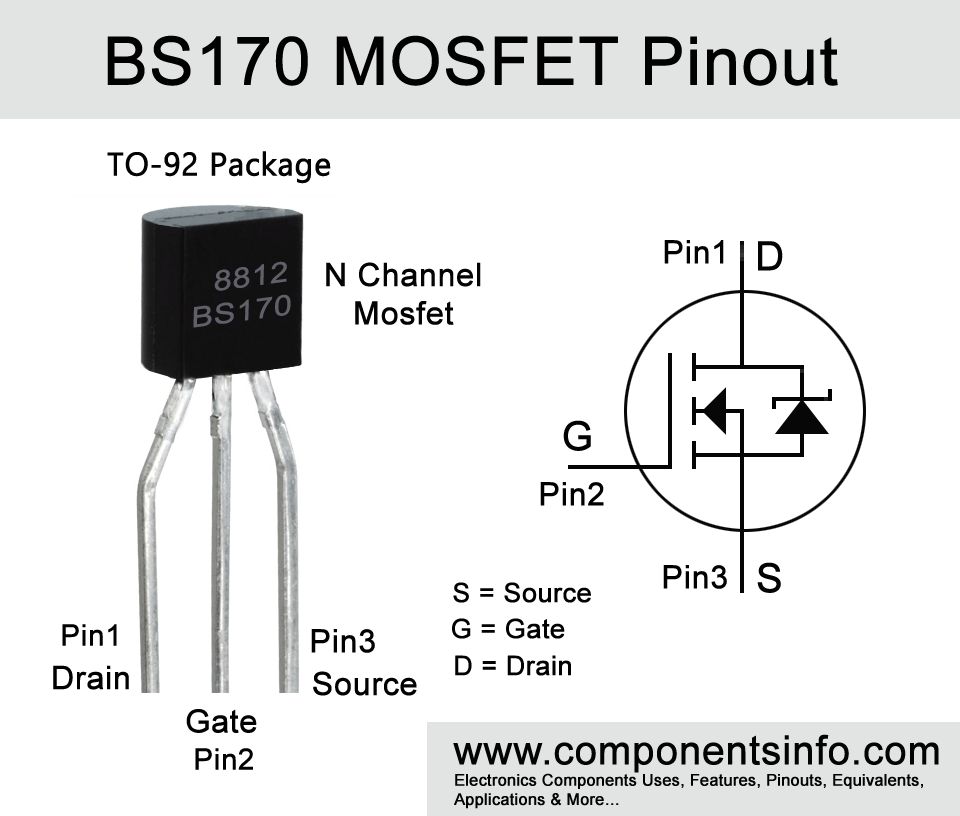
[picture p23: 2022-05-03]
datasheets/bs170-pinout-equivalent.gif

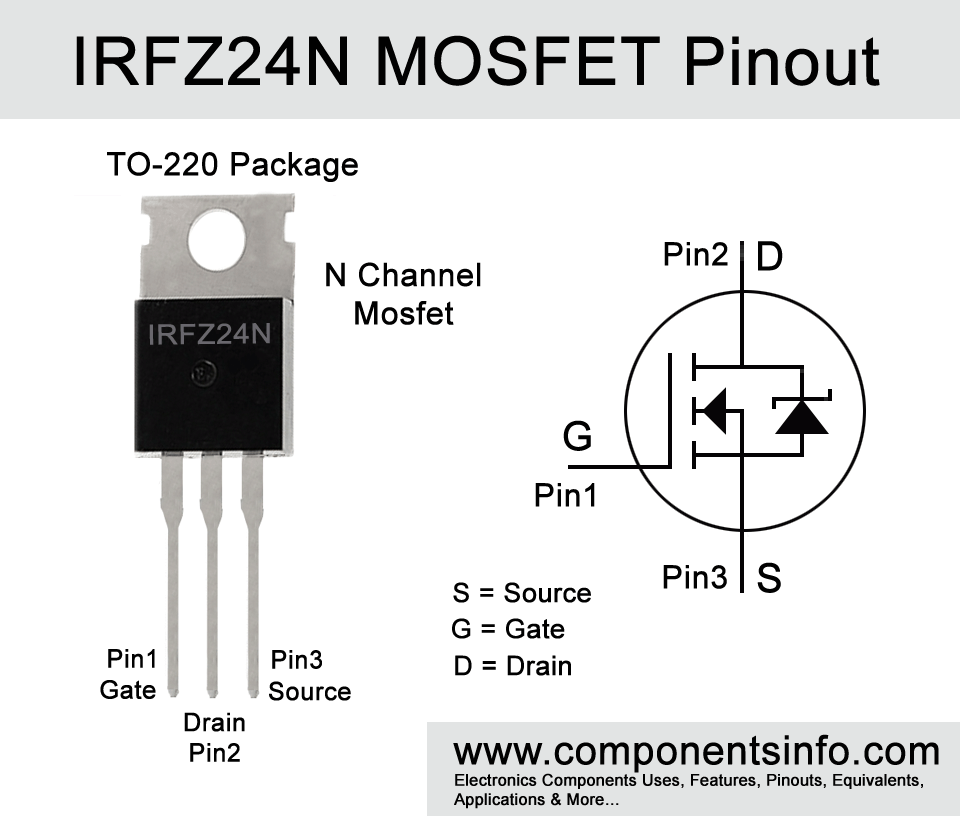
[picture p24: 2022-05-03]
datasheets/irfz24n-pinout-equivalent.gif

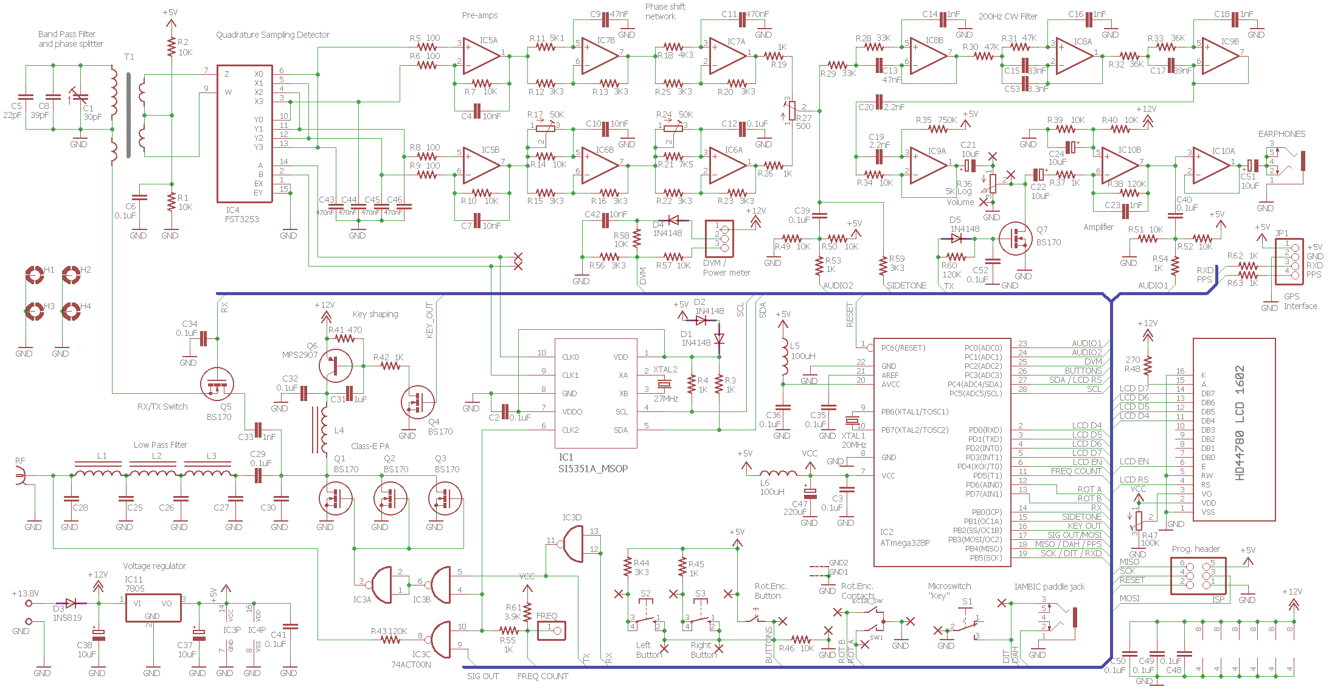
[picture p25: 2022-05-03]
Info/[Clearest] QCX Schematics.png

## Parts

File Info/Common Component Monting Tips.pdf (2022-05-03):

wb5rvz.org (http://www.wb5rvz.org/common/Common_Component_Mounting)

## Common Component Monting Tips

33-41 minutes

Introduction/Contents

This page provides guidance to the builder on common components encountered Introductionbuilding the Softrock series of SDR kits. Click on the links below for techniques/tips on:

- Preparing and Installing Resistors
- Identifying and installing Ceramic Capacitors
- Installing SMT Capacitor Chips
- Installing SMT IC Chips
- Inductors-General
- Toroidal Inductors
- Coils
- Transformers
- Binocular Transformers

Resistors

The resistors are mounted with one of five orientations. The first four are the "hairpin" style, where the body of the resistor is snugged up against the board at the location indicated by the silkscreened circle and the other lead is bent into a hairpin shape and inserted into the hole pointed to by the small line on the resistor's silkscreened circle.

You can put a neat hairpin on a resistor lead by holding the resistor against a credit card and bending the lead over the top of the credit card and back down. In doing so, You want to keep the top of the hairpin as short as possible (e.g., no longer than 1/8"). See images below:

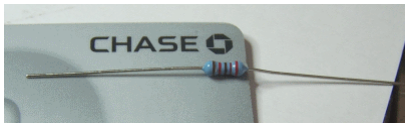
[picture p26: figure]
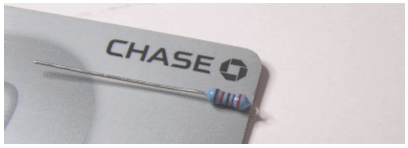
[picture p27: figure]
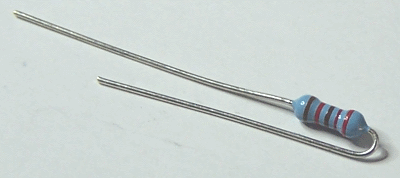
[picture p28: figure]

Hairpin resistor orientations are described in "to-from" terms, indicating the direction the hairpin is pointing in relation to the resistor's silkscreened circle. For example, "east west" means the resistor is mounted hairpin style with the hirpin lead to the west (left) of the body.

The fifth resistor orientation is "flat" ("flat-h" being horizontal and "flat-v" being vertical, with respect to the top edge of the board).

The pictures below illustrate these mounting techniques:

Orientation | Silkscreen | As Mounted

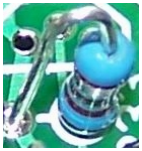
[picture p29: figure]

East-West ("E-W")

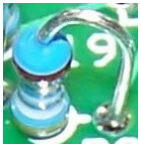
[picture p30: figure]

West-East ("W-E")

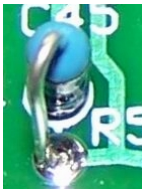
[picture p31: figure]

North-South ("N-S")

South-North ("S-N")

Flat ("flat-h" or "flat-v")

Return to top of page.

Ceramic Capacitors

If you get confused switching between pf and µF (or as we used to call them, "mmF and mF"), you can use this handy calculator. (http://www.unitconversion.org/electrostatic-capacitance/microfarads-to-picofarads-conversion.html) Values

Ceramic capacitor value codes are typically expressed as three digits where the first two digits are the significant figures of the capacitor value and the third digit indicates how many zeros to add to express the capacitor value in pF. Examples would be:

- code 471 would indicate a 470 pF capacitor code 2
- 20 would indicate a 22 pF capacitor.

Ceramic Capacitor Value

1st Digit | 2nd Digit | Multiplier Code | Multiplier | Tolerance Code | Tolerance
0 | 0 | 0 | 1 | B | ± 0.1pF
1 | 1 | 1 | 10 | C | ± 0.25pF
2 | 2 | 2 | 100 | D | ± 0.5pF
3 | 3 | 3 | 1,000 | F | ± 1%
4 | 4 | 4 | 10,000 | G | ± 2%
5 | 5 | 5 | 100,000 | H | ± 3%
6 | 6 | | | J | ± 5%

1st
Digit

2nd
Digit

Multiplier
Code
Multiplier | Tolerance
| Code

Tolerance

7 | 7 | | | K | ± 10%
8 | 8 | 8 | 0.01 | M | ± 20%
9 | 9 | 9 | 0.1 | Z | +80% / -20%

Installing the Ceramic Capacitor

- Lightly snug each capacitor as close to the board as the lead formation will allow.
- Slightly spread the capacitor leads on the bottom side of the board and solder one lead to hold the capacitor in position.
- Cut both leads flush to the bottom of the board and solder the second capacitor lead.

Return to top of page.

SMT Capacitors

Caveat: Note that the SMT caps in the Softrock kits are of two types:

Most of the kits use both types. Do not get them mixed up!

All SMT capacitor locations on Softrock kit boards are to be filled with 1206 size capacitors. You want to do your work on a cookie sheet or other "pan" with sides so, if you accidentally sneeze or otherwise "launch" one of these tiny chips, you may still have a chance of retrieving it.

Removing Caps from the Carrier

Most SMT components are supplied on a "cut tape" carrier strip from a reel of parts. This tape is normally a paper or plastic backing with a clear plastic strip on top. Tony marks the 0.1 µF strip with a black stripe for identification.

The way that works best for most builders is to somehow get a grip on the plastic strip and carefully seperate from the main strip. This will leave the exposed parts sitting in indents in the backing. Sometimes rather than just get one or two, you can take off the entire plastic strip so it won't somehow knock the rest on the floor !! The real trick is getting the plastic strip started: you can use your exacto knife or even a probe tip jabbed in the plastic. Takie care to avoid having the natural "springiness" of the carrier strip act as a slingshot that could launch the loosened chips into the air

Installation procedure is as follows for each SMT 1206 Capacitor

- Add a little solder to one pad and tack one end of a capacitor to a pad.
- Reheat and position the capacitor with the tip of the soldering iron and a toothpick.
- When the capacitor is properly positioned on its pads, solder the other end with enough solder to make a small fillet between the end of the capacitor and the pad.
- < Reheat the first end of the capacitor and add a little solder, if necessary, to make a small fillet at the tacked down end of the

capacitor.

- Excess solder may be removed with solder wick.

Leonard KC0WOX has an excellent video on installing SMT Caps. (http://golddredgervideo.com/kc0wox/softrock/surfacemountsoldering1.wmv)

Another very good video on Youtube by Steve "Soldersmoke" Weber KD1JV is viewable below:

Return to top of page. SMT ICs

SMT Integrated Circuits

Electro Static Discharge (ESD) Precautions

These ICs are very sensitive and subject to being destroyed by electrostatic discharge. You must use common-sense, protective ESD precautions when handling or working with these chips, such as:

- Avoid carpets in cool, dry areas.
- Leave PC cards and memory modules in their anti-static packaging until ready to be installed.
- Dissipate static electricity before handling any system components (PC cards, memory modules) by touching a grounded metal object, such as the recommended uncoated metal cookie sheet.
- If possible, use antistatic devices, such as wrist straps and antistatic mats (see Radio Shack's Set for $25 or the JameCo AntiStatic mat for $15)).
- Always hold a PC card or memory module by its edges. Avoid touching the contacts and components on the ICs.
- Before removing chips from insulator, put on the wrist strap connected to the ESD mat. All work with CMOS chips should be done with the wrist strap on.
- As an added precaution before first touching a chip, you should touch a finger to a grounded metal surface.
- If using a DMM, its outside should be in contact with the ground of the ESD mat, and both leads shorted to this ground before use.

Installation procedure is as follows for each Surface Mount Technology (SMT) IC:

- Orient the IC on its pads so that the pin 1 corner of the IC matches the small 1 (it also looks like a 0) mark in the copper on the bottom side of the board. In general, pin 1 of an SOIC packaged IC is in the lower left corner of the package when the printing on the package top reads upright, from left to right.
- Tack-solder one corner pin of an IC and reheat the tacked pin as necessary to line up the IC on its pads properly.
- Check the orientation of the IC and the line up of the IC on its pads with magnification and good lighting.
- If all is well, carefully solder the rest of the leads to their pads.
- Carefully and closely inspect the pins to look for bridges caused by excessive solder or debris on or around the pads.
- Use solder wick to remove any excess solder or solder bridges between IC pins.
- Using high (3x or better) magnification, carefully check each pad and solder joint.

Leonard KC0WOX has an excellent video on installing surface (http://golddredgervideo.com/kc0wox/softrock/surfacemountsoldering2.wmv)

mount ICs. (http://golddredgervideo.com/kc0wox/softrock/surfacemountsoldering2.wmv) The Sparkfun website also has some good video materials on soldering and wicking SMT ICs. (http://www.sparkfun.com/commerce/present.php?p=BEE-7-SMDSoldering)

The video below describes techniques for soldering SOIC 14 (and 16 and 8) SMDs

View the above in full-screen mode on Youtube. (http://www.youtube.com/watch?v=lauw0bSe-Cw)

Return to top of page.

Inductors - General Info

Inductors in the Softrock kits are generally wound by the builder on one of two different types of magnetic cores: Toroids or "Binoculars".

Toroidal Cores

A Toroidal core is doughnut-shaped and its color (usually either red or yellow) identifies the type of material. Toroids are typically used for coils and transformers. The toroid's component identifier is of the form "Tdd-m", where the "dd" refers to the outside diameter of the toroid in hundredths of an inch and the "m" designates the material used. Some of the more common toroids found in these kits are:

Identifier | Color | Type Material | O.D.
T25-2 | Red | 2 | 0.25"
T25-6 | Yellow | 6 | 0.25"
T30-2 | Red | 2 | 0.3"
T30-6 | Yellow | 6 | 0.3"
T37-2 | Red | 2 | 0.37"

T37-6 | Yellow | 6 | 0.37"
T50-2 | Red | 2 | 0.5"
T50-6 | Yellow | 6 | 0.5"

Binocular Cores

Binocular cores are so-called because their shape calls mind a pair of binoculars. Binocular cores are typically used for chokes and transformers. These kits use binocular cores of two types:

- BN-43-202 (http://toroids.info/BN-43-202.php)
- BN-43-2402 (http://toroids.info/BN-43-2402.php)
- BN-61-2402 (http://toroids.info/BN-61-2402.php)

If your kit calls for two different types of BN-*-2402 cores, take great care in keeping them separate and marked. The Softrock kits will always - in such case - provide the cores in separate, marked bags. DO NOT MIX THEM UP!

Preparing Binocular Cores for Winding

It is highly recommended to "debur" the holes on the binocular cores to allow for smooth insertion of the wires and avoid inadvertent shorts caused by rough edges to the holes. This can be done using a drill bit that just fits into the holes and "twirling" it between your fingers. Better still (as suggested by Iain,MW0XEN) use a mounted stone from a Dremel type tool (just held in your fingers - not powered). This leaves a very nice rounded edge to the holes.

Winding Specifications

Winding specifications provide the information on the number of windings, the role (e.g., primary or secondary) for each winding on a transformer, and the length and type of wire for the windings.

Specification Format

Winding specs will generally resemble the following:

5.0 uH 17T bifilar/34T #30 on T30-2 (red)

(19").

This can be interpreted as:

- Use a T30-2 toroid (color is red and O.D. is 0.3")
- You will need two 19" lengths of #30 wire.
- For toroids, one turn is a single pass through the center hole.
- For binocular cores, one turn is a pass in which the wire goes in the bottom, comes out the top, goes back in the other hole at the top, and comes out the other hole at the bottom.
- The transformer will have a single, 34 turn, secondary winding of 19" of #30 wire. Usually the single winiding is wound onto the core first. Winding should be evenly spaced and ideally cover all but a 15 degree "wedge" of the toroid. Sometimes, it may be necessary to wind over the top of existing turns where there is more wire than there is bare core left.
- The transformer will have two primary windings each of 17 turns of #30 wire. The term "bifilar" means to take one of the two lengths of wire, bend it at the half-point so the resultant "hairpin" is composed of the two 9.5" long halves, and then twist the two

strands together to make a "bifilar" strand with approximately 3 twists to the inch. The bifilar windings are usually wound AFTER (and over) the single strand winding. You should wait until you have wound it correctly before cutting the "hairpin" end of the bifilar strand.

- The inductance value is provided primarily to help validate the number of turns. It is the inductance of the single-strand winding.

Wires

Sometimes the various wires in the kit may be of different colors. Attach no significance to the color; recognize that when the spec calls for a #nn wire, that the "nn" is the gauge of the wire and the higher the gauge number, the thinner the wire.

See the sections below for further details on winding Toroidal and Binocular inductors.

Toroid Coils

Toroids

Identifying the toroids becomes simple once you figure out the coding. The toroids are designated using the pattern "T-NN-M". The critical pieces are the "NN", representing the outside diameter of the "donut" in hundredths of an inch, and the "M", representing the type of material used to make the core. Tony uses the following toroids in his kits:

- T30-2 (red)
- T37-2 (red)

- T25-2 (red)
- T25-6 (yellow)
- T30-6 (yellow)

Toroids are used in single-winding coils and multi-winding transformers. In either case, the number of turns must be counted. Any pass through the center of the Toroid is counted as a "turn" (see below).

Coils

The winding of a single-winding toroidal inductor is fairly straight-forward. Each pass through the center counts as a turn. The windings should be spaced evenly around the circumfrence of the toroid, ideally leaving about a 15 degree "wedge" between the beginning and ending of the winding. The image below is of a 22 turn coil wound on a toroid.

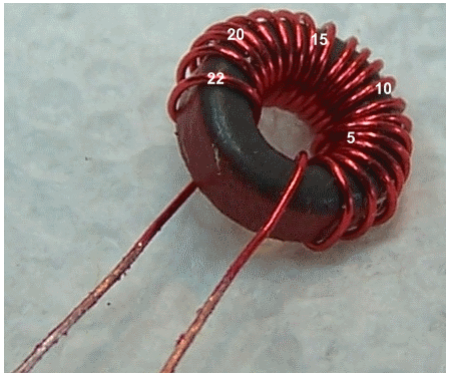
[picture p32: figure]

Occasionally, you may find that there is not enough room on the toroid to place all of the windings without having to go back and add a layer of winding. Tony Parks suggests that you overlap some turns as you put on windings around the circumference of the core so that all turns are on the core by the time you get back to the start end of the winding. This should have negligible effect on the coil's performance in the radio.

Alan Wolke, W2AEW has a very helpful 8 minute video on Youtube, showing his clever technique for winding toroidal coils using a "sawed-off" chopstick.

Alan also has another video showing how to wind a trifilar transformer of 10 turns:

Leonard, KC0WOX, also has an excellent (if large - 183 Mb!) video showing the winding (http://www.golddredgervideo.com/bitx20/torroidalinductorspart1.wmv) of a 26 turn coil on a T-37 core. While the turns andcore size in the video are not used in any of the Softrock kits, the technique is essentially the same. The actual process of winding the core begins at about 8.5 minutes into the video.

Clockwise or Counterclockwise?

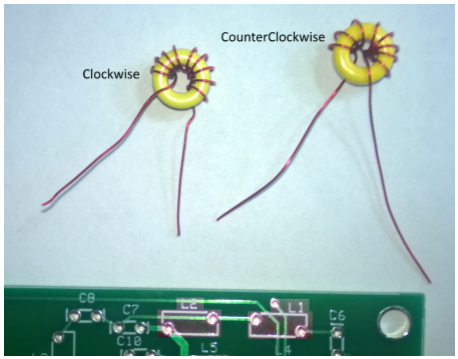
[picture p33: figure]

While the direction of winding of a toroidal coil really makes no difference so long as all windings on that core are in the same direction, it can make a difference in the physical placement of the finished coil on the circuit board. This picture shows two 10-turn coils, one wound clickwise and one wound counterclockwise. It also shows a typical circuit Board and its silkscreened coil templates. Notice how the clockwise coil will fit correctly in the holes for L2, but will have an awkward fit to the holes for L1. Similarly, notice how the counterclockwise wound coil works for the L1 slot but only awkwardly for the L2 slot. If you wish to have your coils line up like the designer intended, you need to pay attention to the silkscreen slots and the hole positions, mentally trying to place a clockwise-wound coil vs. a counterclockwise-wound one into the slot. You can use these

rules of thumb:

- If the coil template is horizontal and the left-hand hole is at the lower left, wind clockwise
- If the coil template is horizontal and the left-hand hole is at the upper left, wind counter clockwise
- If the coil template is vertical and the top hole is on the left, wind clockwise
- If the coil template is vertical and the top hole is on the right, wind counterclockwise

Toroidal Transformers

Winding toroidal transformers usually involves 2 to 3 windings on the same core. The most common is a transformer with a single winding (primary or secondary) over which two "bifilar" windings are superimposed (two secondaries or primaries). See the Toroid Winding Hints from the Experts (http://www.wb5rvz.org/common/ToroidWindingHints.htm) for good tips on how to wind a toroidal transformer.

In general the transformer outlines on the circuit boards, 4 hole or 6 hole patterns, correspond to the shape of the core involved. The silkscreen lines between opposing hole pairs correspond to the connections for one winding. All that is needed is to connect the leads from one side of the core, or one hole of the core in the case of the binocular cores, to the holes on one side of the pattern the the leads from the other side of the core, or other hole of a binocular core, to the holes on the other side of the pattern. Secondary and primary leads need to be sorted out

properly.

When you have finished winding, stripping, and tinning the toroidal transformer's windings, you will two leads for each winding. Each lead will come out on a different side of the toroid. For example, consider a three-winding transformer with one primary ("P") and two secondary windings ("S1" and "S2"). It will have a total of six leads, three on one side of the toroid and three on the opposite side:

- The two primary leads, "Pa" and "Pb" ("P" stands for primary; "a" is one side of the toroid, "b" is the opposite side)
- The two leads for the 1st secondary winding, "S1a" and "S1b" ("S1" stands for the 1st secondary winding; "a" is one side of the toroid, "b" is the opposite side)
- The two leads for the 2nd secondary winding, "S2a" and "S2b" ("S2" stands for the 2nd secondary winding; "a" is one side of the toroid, "b" is the opposite side)

•


To mount the transformer you insert the leads into the holes annotated on the board as "P", "S1", and "S2". The holes may also be annotated as to the "row" ("a" row or "b" row) which corresponds to the leads on the "a" side or the "b" side of the toroid.

the builder should start with the single winding, inserting its two leads into the appropriate holes and then do the same with the first of the two bifilar windings, and finally do the same with the second of the two bifilar windings

After inserting the leads, the builder should pull each lead pair through the holesuntil the transformer is snug to the board. Soldering the leads completes the process.

Leonard, KC0WOX, has an excellent (large - 100+ Mb!) video showing the winding and mounting of a bifilar transformer (http://www.golddredgervideo.com/kc0wox/softrock/softrockt4.wmv) on an earlier Softrock (transceiver) kit. He also has a 2 minute video clarifying how bifilar transformers are mounted on Softrock boards. (http://golddredgervideo.com/kc0wox/softrock/t4winding.wmv)

Return to top of page.

Binocular Transformers

Debur the Core Before Winding

Binocular cores

Winding and Installing transformers on binocular cores is a hard process to clearly describe. There are two aspects to it.

- One is the actual winding of the coil. Bino cores can be wound either:
- with all leads coming out of the same end or
- with some leads coming out of one end and some coming out of the other.
- All Tony's kits - so far - have used the winding convention where all windings come out of one end of the binocular core, with one turn counted each time the wire goes in one hole and comes out the other, at the same end (see below).

•


- The other aspect is the correct polarity. That is a little easier, since Tony has designed the boards such that the polarity is pretty well handled for you.
- The key is to start each winding in the same hole of the bino core and end each winding in the other hole (on the same end of the core).
- When you finish winding the typical bino transformer with one single wire winding and one bifilar (i.e., twisted pair of wires) wire winding (yielding two windings), you have three wires coming out of each hole on the same end of the core, corresponding to the leads of the three windings.
- You should carefully strip the insulation from the leads (up to within an eighth of an inck of the core) and tin the leads. Sandpaper can be used to strip the insulation, or you can use an Exacto kinfe to scrape it off. Note that the insulation on the wire Tony provides is normally the heat-strippable type (which you can strip by repeatedly pulling the wire end through a HOT solder blob on the iron tip)..
- In most of Tony's kits the core is mounted "standing up"

vertically and the windings' lead pairs are inserted into the holes corresponding to the winding.

- For example, if you wind a transformer with one primary (P) and two secondary windings (S1 and S2), you end up with three leads (Pa, S1a and S2a) coming out of one hole and three leads (Pb, S1b, and S2b) coming out of the other hole.
- The board layout in the enhanced builders notes will usually have annotations on the six holes (for a common transformer) that indicate the lead pairs for the primary, and each of the 2 secondaries.
- The builder then needs to match the holes with the appropriate winding leads. This graphic is an example:

•


- T201 (above) has one primary and two secondary windings. When wound, it will have 6 leads in all:
- two leads (Pa and Pb) and
- four secondary leads (S1a, S2a, S1b, S2a).


•

- You should use an ohmmeter to identify each winding pair.

Then slip a 1/8" pice of hookup wire insulation onto the Pa and Pb leads to temporarily provide identification of the primary. Also slip a 1/8" piece of insulation onto the S1a and S1b leads to act as a "spacer for the actual mounting.

- To mount the core, the builder typically starts with the Primary leads, removing the insulation piece and orienting the core such that (in the above instance):
- the core hole from which Pa lead exits is aligned with the P hole on the top row of the holes and
- the core hole from which the Pb lead exits is aligned with the P hole on the bottom row.
- Then insert those primary leads into their corresponding holes.
- Then take the first pair of S leads (e.g., S1a and S1b) and similarly align with and insert into the "S1" holes (S1a on the top and S1v on the bottom row of holes in the graphic above).
- Finally do the same thing with the remaining lead pair (S2a and S2b).
- Then pull through all of the leads from the bottom of the board to ensure no leads have any loose ends or loops topside and the transformer is nice and snug on the board and the 1/8" spacer
- Solder all leads and you're ready to test them.

Return to top of page.

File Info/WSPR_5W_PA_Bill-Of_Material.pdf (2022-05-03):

Sheet1

# 5W PA for WSPR Ultimate

vk3pe | Feb-16

"0805-1206" means most footprints can be fitted, 0805 preffered though

Part Type | Designator | Footprint | Description | Notes
1.09uH | L1 | T50_TOROID | Inductor | for 30M band (refer to Ultimate web page for other band values)
1.09uH | L2 | T50_TOROID | Inductor | for 30M band (refer to Ultimate web page for other band values)
1.257uH | L3 | T50_TOROID | Inductor | for 30M band (refer to Ultimate web page for other band values)
270pF | C17 | 0805-1206 | Capacitor | for 30M band (refer to Ultimate web page for other band values)
270pF | C16 | 0805-1206 | Capacitor | for 30M band (refer to Ultimate web page for other band values)
560pF | C14 | 0805-1206 | Capacitor | for 30M band (refer to Ultimate web page for other band values)
560pF | C15 | 0805-1206 | Capacitor | for 30M band (refer to Ultimate web page for other band values)
100K | R5 | 0805-1206 | RES FIXED
100nF | C6 | 0805-1206 | Capacitor
100nF | C5 | 0805-1206 | Capacitor
100nF | C4 | 0805-1206 | Capacitor
100nF | C11 | 0805-1206 | Capacitor
100nF | C7 | 0805-1206 | Capacitor
100nF | C8 | 0805-1206 | Capacitor
100nF | C9 | 0805-1206 | Capacitor
100nF | C10 | 0805-1206 | Capacitor
100nF | C2 | 0805-1206 | Capacitor
100nF | C3 | 0805-1206 | Capacitor
10K | R3 | 0805-1206 | RES FIXED
10K | R2 | 0805-1206 | RES FIXED
10K | R4 | 0805-1206 | RES FIXED
10R | R7 | 0805-1206 | RES FIXED

Page 1

Sheet1

10uF/16V | C12 | ccase | polarized cap
180R | R10 | 0805-1206 | RES FIXED
180R | R8 | 0805-1206 | RES FIXED
1K | RV1 | trim-pot | POTENTIOMETER
1N4001 | D1 | axial0.5 | Diode
1nF | C1 | 0805-1206 | Capacitor
22uF/16v | C13 | ccase | polarized cap
270R | R6 | 0805-1206 | RES FIXED
2N7000 | Q1 | TO-92B | FET
33R | R9 | 0805-1206 | RES FIXED
4K7 | R1 | 0805-1206 | RES FIXED
78L05 | U1 | to-92a | Regulator IC
BN43-202 | T1 | BALUN | balun core
NDT2955 | Q2 | SOT-223 | FET
RD16HHF1 | Q3 | TO-220 | FET

Page 2

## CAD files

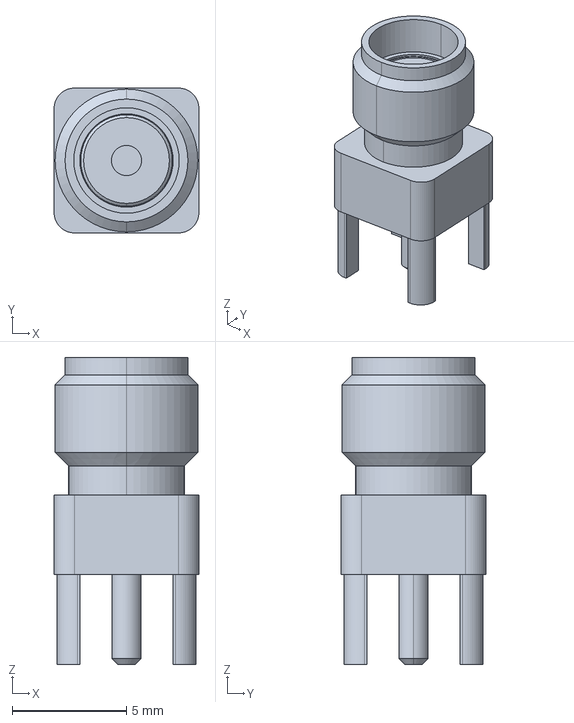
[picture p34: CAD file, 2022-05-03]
HF-PA-v5.homebrew/models/c-221789-1-e-3d.stp
6.35 x 6.35 x 13.5 mm

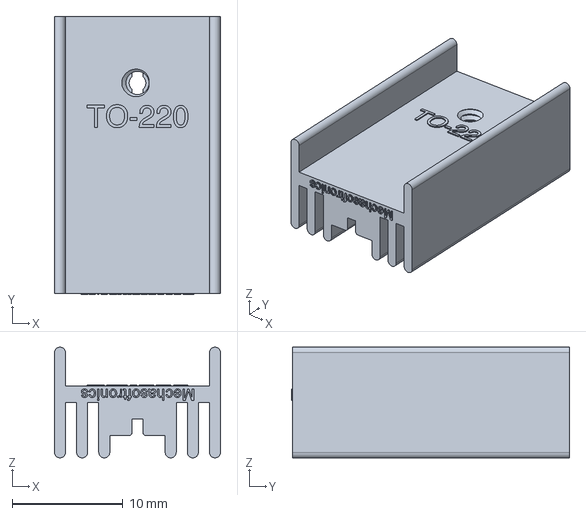
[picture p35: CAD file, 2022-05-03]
HF-PA-v5/models/heatsink_to-220.stp
15.0 x 25.1 x 10.0 mm

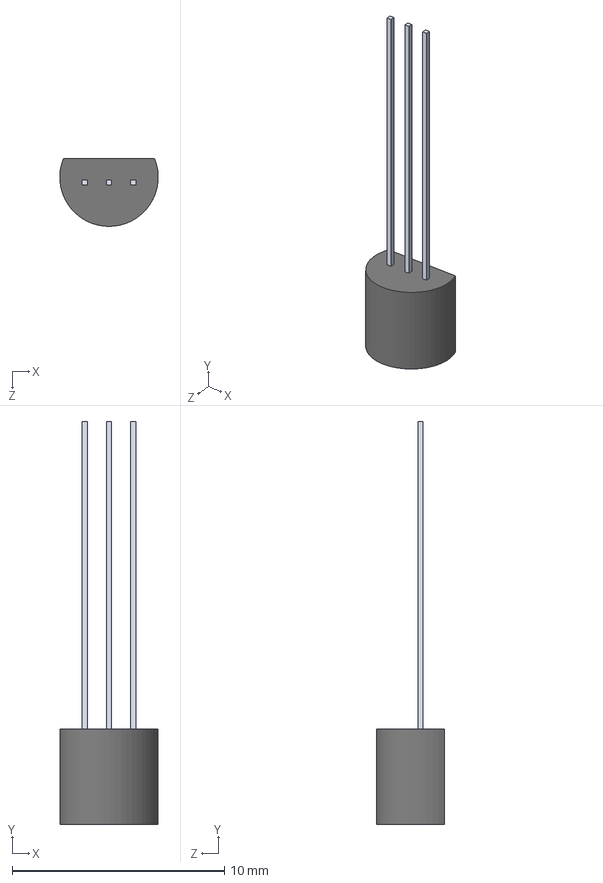
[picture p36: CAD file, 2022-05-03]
HF-PA-v5.homebrew/models/Transistor_TO-92_Type.STEP
4.64 x 19.0 x 3.20 mm

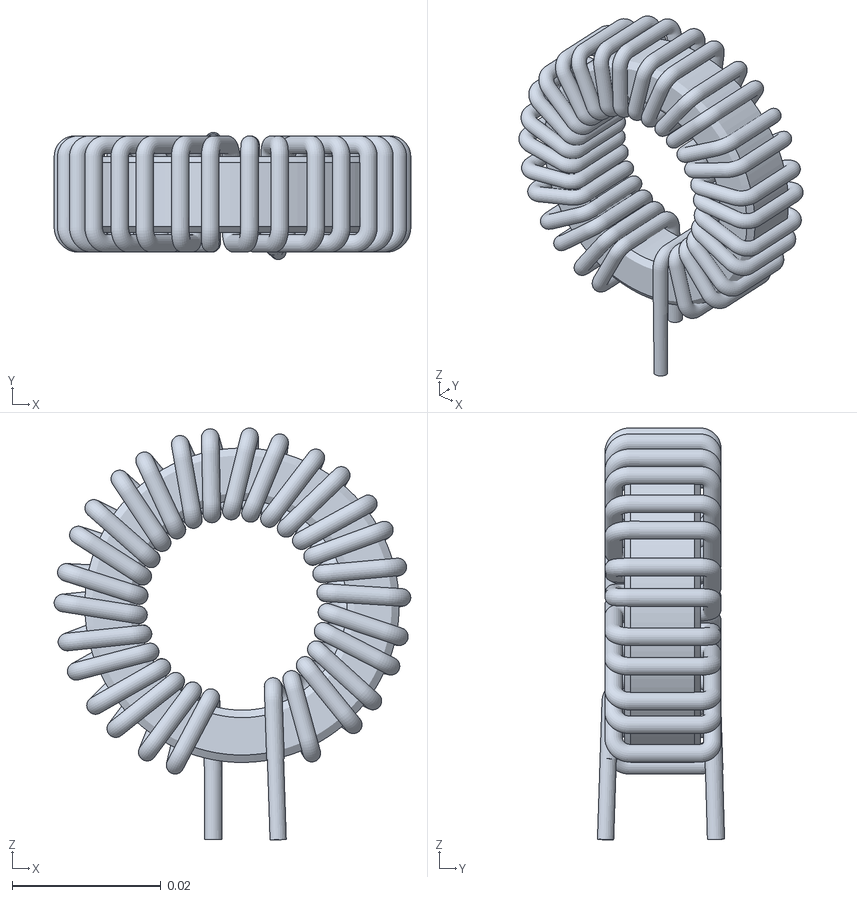
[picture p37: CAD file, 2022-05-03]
HF-PA-v5/models/DC inductor.stl
0.048 x 0.0171 x 0.0554

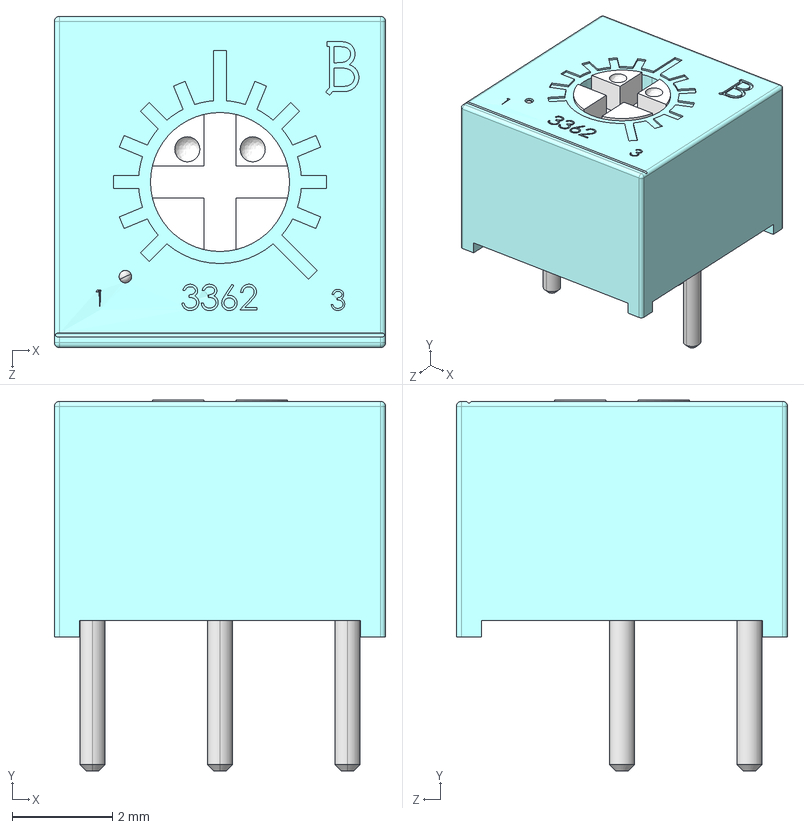
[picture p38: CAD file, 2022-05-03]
HF-PA-v5.homebrew/models/3362P-1-102LF.STEP
6.60 x 7.40 x 6.60 mm

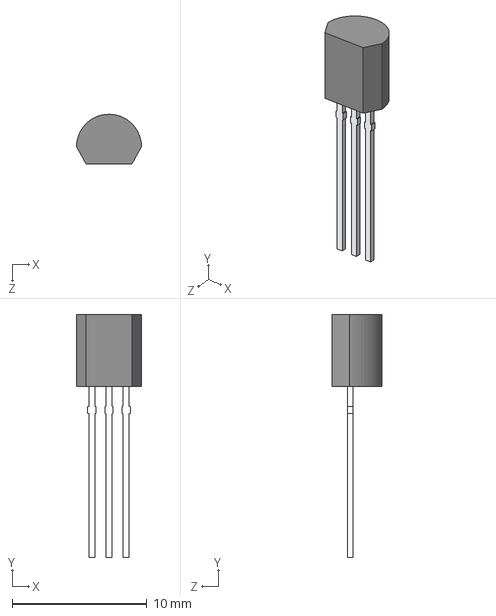
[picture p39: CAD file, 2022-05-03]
HF-PA-v5.homebrew/models/LM78L05ACZ_NOPB.step
4.83 x 18.0 x 3.68 mm

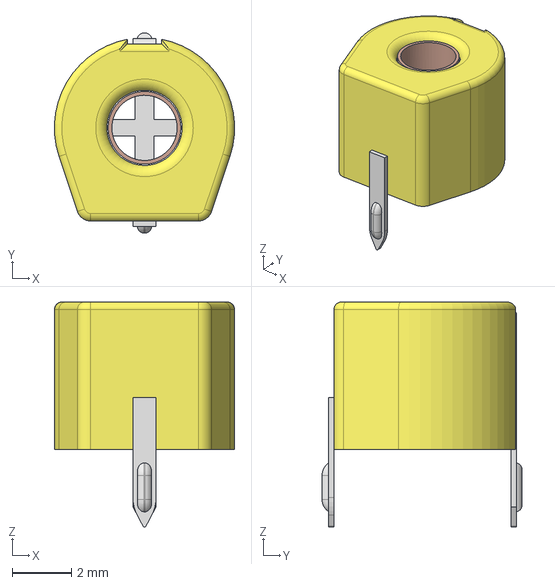
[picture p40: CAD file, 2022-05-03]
HF-PA-v5/models/Trimmer Cap - Yellow.stp
6.09 x 6.76 x 7.61 mm

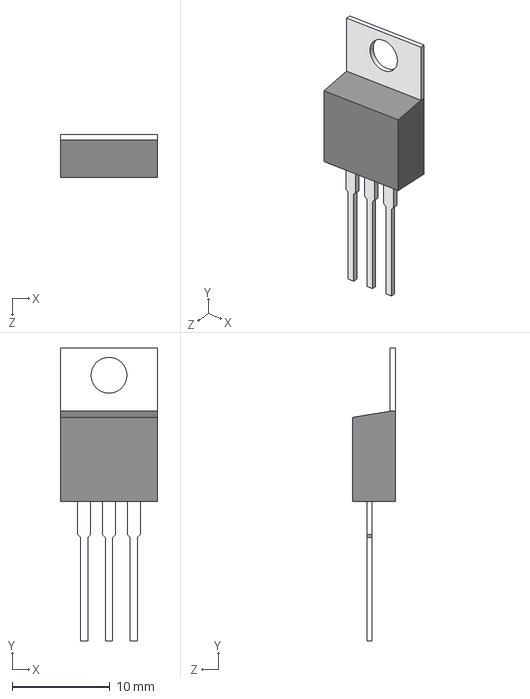
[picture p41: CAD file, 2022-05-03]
HF-PA-v5/models/LM7805CT_NOPB.step
9.97 x 30.0 x 4.44 mm

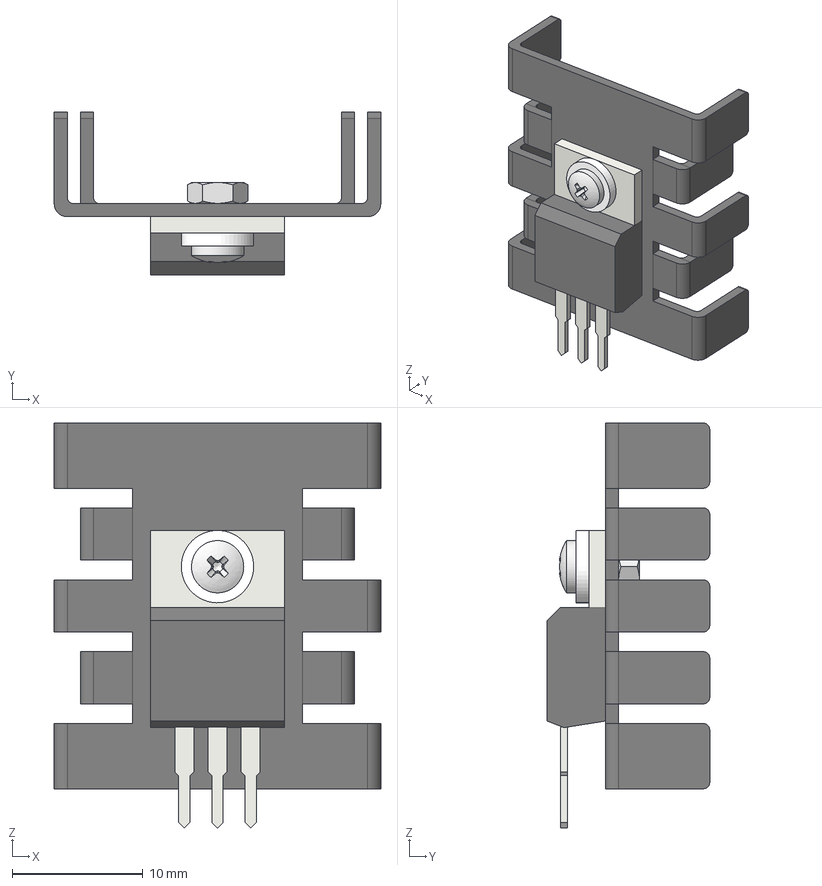
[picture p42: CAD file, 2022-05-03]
HF-PA-v5.homebrew/models/Heatsink TO-220 28x25x8mm.stp
25.0 x 12.4 x 31.0 mm
TO-220_3_Vertical
Isolator
Screw
Nut
Heatsink_28x25x8mm

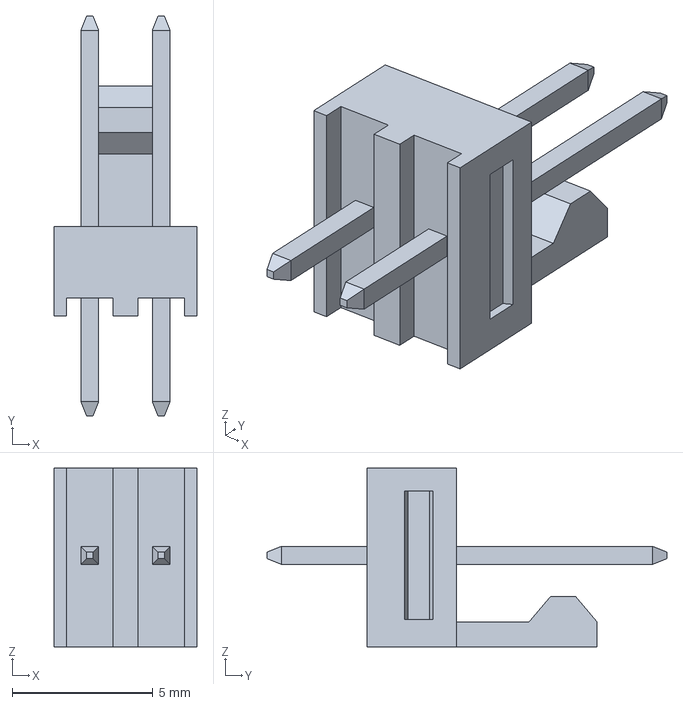
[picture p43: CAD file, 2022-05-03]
HF-PA-v5/models/22-23-2021.stp
5.08 x 14.2 x 6.35 mm

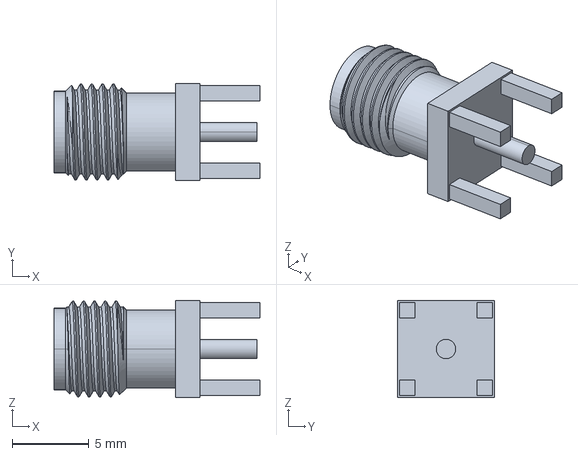
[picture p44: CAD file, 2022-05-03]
HF-PA-v5.homebrew/models/901-144.stp
13.5 x 6.35 x 6.35 mm

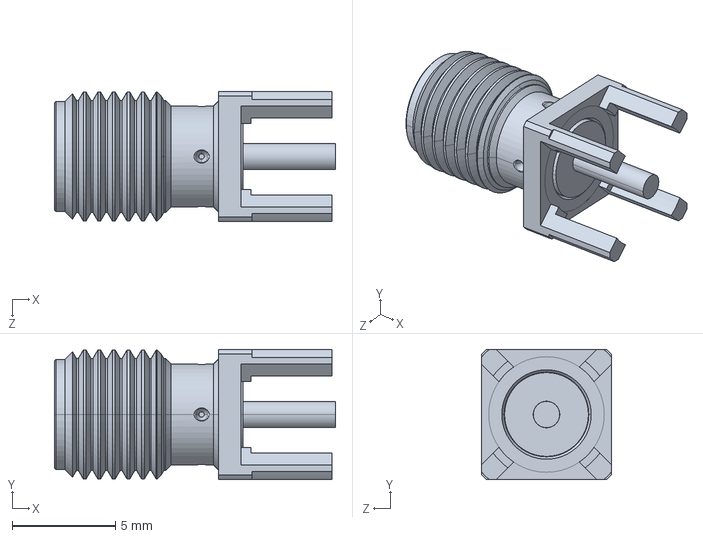
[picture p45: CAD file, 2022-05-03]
HF-PA-v5/models/R125.426.000 D.STEP
13.6 x 6.31 x 6.31 mm

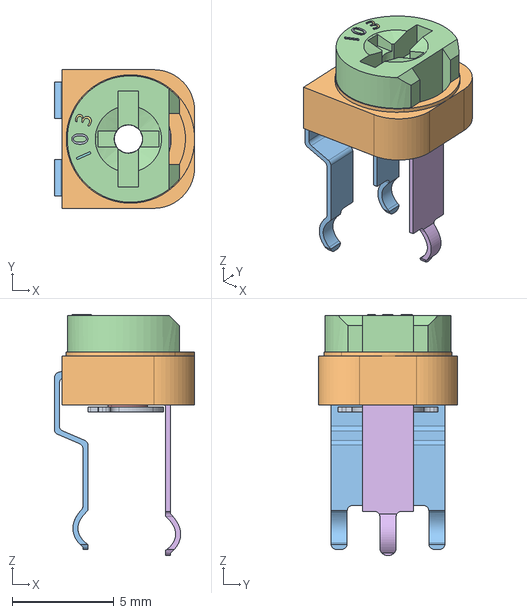
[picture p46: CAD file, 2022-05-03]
HF-PA-v5.homebrew/models/Poti_10kohm.stp
6.88 x 6.80 x 11.8 mm

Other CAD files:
HF-PA-v5/models/Trimmer Cap - Green.stp
HF-PA-v5.homebrew/models/Trimmer Cap - Green.stp
HF-PA-v5.homebrew/models/577102B00000.STEP
HF-PA-v5.homebrew/models/User Library-TO-92-2_54-line.STEP
HF-PA-v5/models/577102B00000.STEP
HF-PA-v5/models/User Library-TO-92-2_54-line.STEP

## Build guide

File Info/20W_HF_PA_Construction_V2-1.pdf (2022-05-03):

Version date 03-04-06

## G6ALU 20W FET PA – Construction Information

The requirement
This amplifier was designed specifically to complement the Pic-A-Star transceiver developed by Peter Rhodes G3XJP. From the band pass filter an output of approximately –10dBm can be obtained, this requires amplifying to a useable power level to be of use. Although developed for a specific application the design presented here is flexible enough to be used with any low level HF signal source. Adjustment of the attenuator value and possible removal of the first stage can accommodate a higher input power.
Circuit description
A 3 stage topology has been used requiring a nominal input of –13dBm (0.05mW) for an output of 20W at 1.8MHz falling to 16W at 30MHz (typically 25W on 80M). Typical current consumption is 2.7Amps @ 13.8V, giving a stage efficiency of 53% at 20W output.

Field effect transistors have been used for the power stages, these are low cost and have so far proven to be very robust. One failure mode that must be looked out for is excessive device dissipation; ensure that the gate is not left “floating”. If for any reason there isn’t a DC connection the gate may rise in voltage and turn the device on drawing excessive current leading to device failure. The devices used here are in a TO220 package which differ from switching devices in that the tab is connected to the source electrode, so in this design are grounded by the PCB and heat sink. No insulating washers are used when bolting the devices down to the heat sink and PCB.

To ensure a good match to the band pass filters a 5dB attenuator has been incorporated before Q1, this is required as the input impedance will vary with frequency. When used with the Pic A Star any additional attenuation required should be placed in the IF stage – refer to the STAR “Set up information” document.

The first gain stage follows the input attenuator, this is a simple common emitter bipolar circuit using emitter feedback, the gain of which is set by the load impedance of T2 (200 Ohms) and that of emitter resistor R8 (33 Ohms). These components set the voltage gain at about 8 or 18dB power gain.

Stage 2 comprises of two field effect transistors (FETs), as previously stated no negative feedback is provided giving a stage gain of about 23dB, providing ¼ watt of drive to the output stage. FETs are broadband devices, if driven from a constant voltage source their output can be expected to be flat across the HF band. Unfortunately FETs have a relatively high input capacitance, in the case of the RD06HHF1s used here it is about 27pF giving a capacitive reactance of 196 Ohms @ 30Mhz. Rather than trying to provide a broad-band match to this reactance it is simpler just to load the gate with a resistor of much smaller value, this does of course limit the stage gain but to me 23dB is still quite adequate! Q2 and Q3 gates are loaded with 100R resistors, these also provide a DC path for the bias voltage.

Matched device pairs haven’t been used so separate gate bias is provided for each device, this bias is provided from a common source; ZD1 a 5.6 volt zener diode in series with D1 giving some temperature compensation. The driver transistors are running with a quiescent current set at 125mA each, gate load resistors R10 and R11 are decoupled to ground via C9 and C10 so T2 “sees” a total load of 200 Ohms. The output load of Q2 and Q3 is provided by a centre-tapped transformer wound on a BN43-1502 or Epcos B62152A4X1 type core. As the two types have different AL values, different winding instructions are given for each.

The output stage is very similar to that of the driver having a gain of about 21dB, the main difference being with the output transformer arrangement and gate load resistors. This transformer consists of two cores, the primary of each are connected in series and the outputs in parallel, this arrangement ensures that both transistor drains are tightly coupled in anti-phase so giving good even harmonic suppression. The quiescent current of each transistor is set to 250mA.
Construction
The PCB has been designed to have a continuous ground plane on the underside with connecting tracks on the top. To enable a PCB to be manufactured using your preferred method I have included a reversed positive plot of the top side, when plotting ensure that Acrobat isn’t resizing the plot for you by checking with the 100mm reference provided.

As they are easier to apply and have lower parasitic inductance, surface mount capacitors have been used where practical, in addition all transformers are surface mounted. Other components are leaded types and pass through the PCB, note that anywhere a grounded lead passes through the PCB it should be soldered top and bottom, in addition there are 6 through board links that need soldering both sides. All non-grounded leads which pass through the board should have the ground plane relieved on the underside.

Transformer winding - All transformers are simple to wind, wire diameter for transformers T1 and T2 isn’t critical. For T3 don’t be tempted to greatly increase the diameter of wire although the core holes would allow it, using a wire significantly thicker increases its self capacitance affecting the transformer wide band performance.

The one turn primary of T4 and T5 can be made from a piece of braid removed from RG58 or similar coax, for the secondary winding use PVC covered hook up wire. Use the heaviest type that will pass through the cores.

As previously noted no insulating washers are used between the heat sink, transistors and PCB. A direct ground connection must be made between the PCB and heat sink, grounding for the Fets is mainly made via their tabs. Two options are provided for output HF compensation, the low cost route is to use two 1nF surface mount ceramic capacitors but due to their questionable suitability (due to max current handling) provision has been made for a 2n2 silver mica part. So far though there are no reported failings of ceramic capacitors, the choice is yours.

The following pictures are of the prototype, some component positions have changed with the published version.

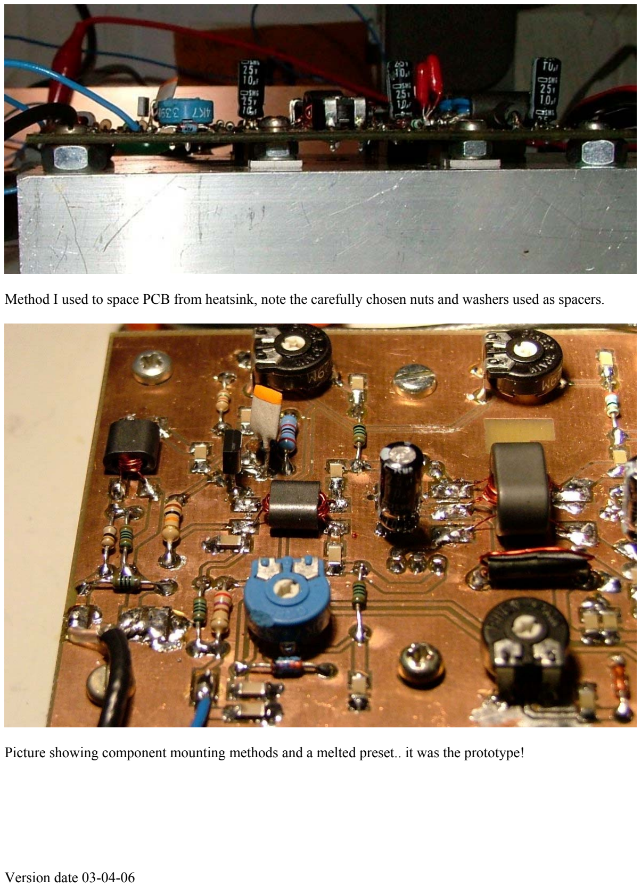
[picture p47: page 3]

Method I used to space PCB from heatsink, note the carefully chosen nuts and washers used as spacers.

Picture showing component mounting methods and a melted preset.. it was the prototype!

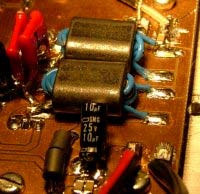
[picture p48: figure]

Output transformer mounting detail.

Testing and alignment
Before applying power check and make sure there are no bridges between any pads and the ground plane. Turn all bias presets anticlockwise (lowest bias voltage). Momentarily apply a supply to the 13V8 terminal and check current drawn is practically zero; C28 will draw initial charging current.

Apply supply to the Bias input and separately to the 13V8 input via an ammeter capable of reading 1 Amp, connect a power meter and 50-Ohm dummy load to the output. Adjust VR1 for a quiescent current of 125mA, VR2 for an increase of 125mA (250mA total), VR3 for an increase of 250mA (500mA total) and finally VR4 for another 250mA increase giving 750mA total quiescent current. Bias adjustment will be sensitive but actual values achieved aren’t critical. At this stage there shouldn’t be any RF power appearing at the dummy load!

Disconnect power, attach to the band pass filter transmit output of the STAR and apply power. Select 80M and adjust the drive level to a low level, with key down slowly increase the drive and monitor the output level. If an oscilloscope is available monitor the output waveform, it should be easy to achieve an output of 20W on 80M before the output becomes distorted. Repeat drive adjustment for all bands.
In Use
Note that the input and output circuits are “floating”, in normal use the coaxial screen connection will be linked to the PCB ground pad. This facility has been provided for situations where a specific cabinet construction generates a ground loop, a floating input or output may “break” the loop.

No output filter is provided, the amplifier still has considerable gain in to the VHF region so must be used with an effective low pass filter, typically the second harmonic is 40dB down on carrier but third harmonic only 25dB down.

When used with a STAR the bias supply is provided directly by the timer board (12V Tx PA bias) and 13V8 terminal left permanently connected to supply, the transistors were developed for use in mobile equipment so can be safely supplied with higher than the normal shack voltage of 13.8V. For an increase in output up to 14.5V may be used safely.

Component Sources
Q1 is specified as a ZTX327 or ZTX313, both of which are now obsolete! An alternative may be the MPSH10 or indeed any other RF transistor of suitable current and frequency rating, watch the pin outs though and adjust C3 to compensate the HF end of band.

The FET devices were obtained from European Microwave Components, contact details:

European Microwave Components Ltd.
36 Priors Way Business Park,
Coggeshall,
Essex.
United Kingdom.
CO6 1TW

Web http://www.emc.uk.com and email sales@emc.uk.com , note that their minimum order charge before VAT is £25, the value of transistors used in this design total about £8.00!

Ferrite cores can be obtained from any of the normal vendors; no doubt substitutions can be made especially with T1 – T3 whose characteristics aren’t critical.

Change log:
28-04-05 | Corrected input power requirements following robustness test
| Changed harmonic output level
| Added note about PCB grounding
| Added note on through board links
| Added notes on transformer construction
02-05-05 | Corrected value of C3 in parts list to 220pF
03-04-06 | Input attenuator changed from 10dB to 5dB, additional attenuation now placed in IF stage.
| R2 and R3 were 100R, now 180R. R1 was 68R now 27R

Quantity | Component reference | Description | Notes | Function
23 | C1, 2, 4, 5, 6, 7, 8, 9, 10, 12, 13, 14, 15, 16, 17, 18, 20, 21, 22, 23, 24, 26, 27 | 100nF 1206 SM | | Coupling - decoupling
3 | C11, 19, 28 | 10uF 25V PC electrolytic | | LF decoupling
1 | C25 | 330pF Silver Mica > 100V | Can be made up of multiple capacitors | HF frequency compensation of T4 & T5
2 | C29, 30 | 1nF 1206 SM | Not used if C31 fitted, see text | LF frequency compensation for T4 & T5
1 | C3 | 220pF 1206 SM | | HF peaking for Q1
1 | C31 | 2200pF Silver Mica | Not used if C29 & 30 fitted, see text | LF frequency compensation for T4 & T5
1 | D1 | 1N4148 | Partial temperature compensation for bias supply
1 | ZD1 | 5V6 400mW | Bias voltage regulation
1 | Q1 | ZTX313, ZTX327 | | First stage amplification
2 | Q2, Q3 | RD06HHF1 | See text | Second stage amplification
2 | Q4, Q5 | RD16HHF1 | See text | Third stage amplification
3 | R5, R10, R11 | 100R | | R5 decoupling, R10 & R11 load for 1st stage amplifier and gate reactance swamp resistors
3 | R1, R12, R13 | 27R | | R1 part of input attenuator. R12, 13 Gate reactance swamping resistors for Q4 and 5
1 | R4 | 10K | | Part of Q1 bias
1 | R6 | 1K5 | | Part of Q1 bias
1 | R7 | 270R | Resistor will dissipate about 0.3W so miniature 0.6W MF recommended | Series resistor for FET bias supply
2 | R2, R3 | 180R | | Input attenuator
1 | R8 | 33R | | Q1 gain setting
1 | R9 | 82R | | Q1 emitter resistor
| | | Unless otherwise stated all resistors 1/8 watt or higher , 5% tolerance or better
4 | VR1, VR2, VR3, VR4

2K2 Horizontal
preset | Q3-6 gate bias setting
1 | L1 | 2* type 43 beads | 2 passes of 0.25mm enamelled copper wire through 2 type 43 beads - see photos | Supply decoupling
1 | L2 | 2* type 43 beads | 1 pass of 1.25mm tinned copper wire through 2 type 43 beads -see photos | Supply decoupling
1 | T1 | BN43-2402 | Primary 3 turns, secondary 6 turns of 0.25mm enamelled copper wire wound on to BN43-2402 core
1 | T2 | BN43-2402 | Primary 6 turns, secondary 4 turns of 0.25mm enamelled copper wire wound on to BN43-2402 core
1 | T3 | BN43-1502 or Siemens (Epcos) B62152A4X1 | Primary 8 turns centre tapped (I.E. 4+4), secondary 4 turns 0.25mm enamelled copper wire wound on type BN43-1502 or for Epcos B62152A4X1 core, 12 turns centre tapped primary with 6 turn secondary.
2 | T4, T5 | BN43-202 | Primary 1 turn of braid removed from RG58 cable or similar, secondary 4 turns of PVC covered hook up wire wound on BN43-202 core - see photo.

### 20W HF PA Component list

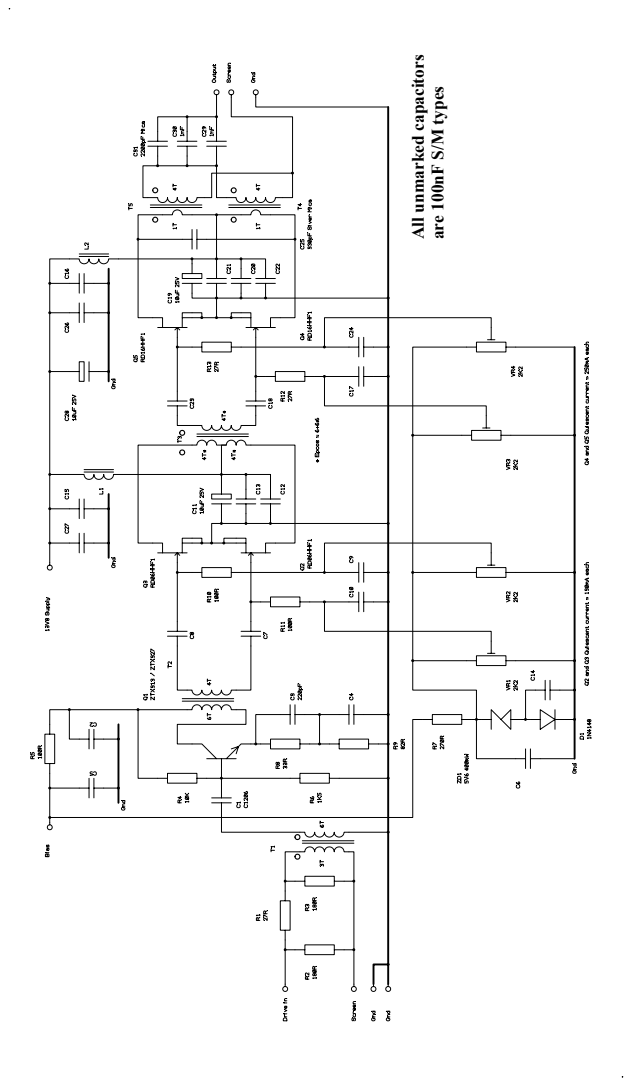
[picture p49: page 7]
are 100nF S/M types

All unmarked capacitors

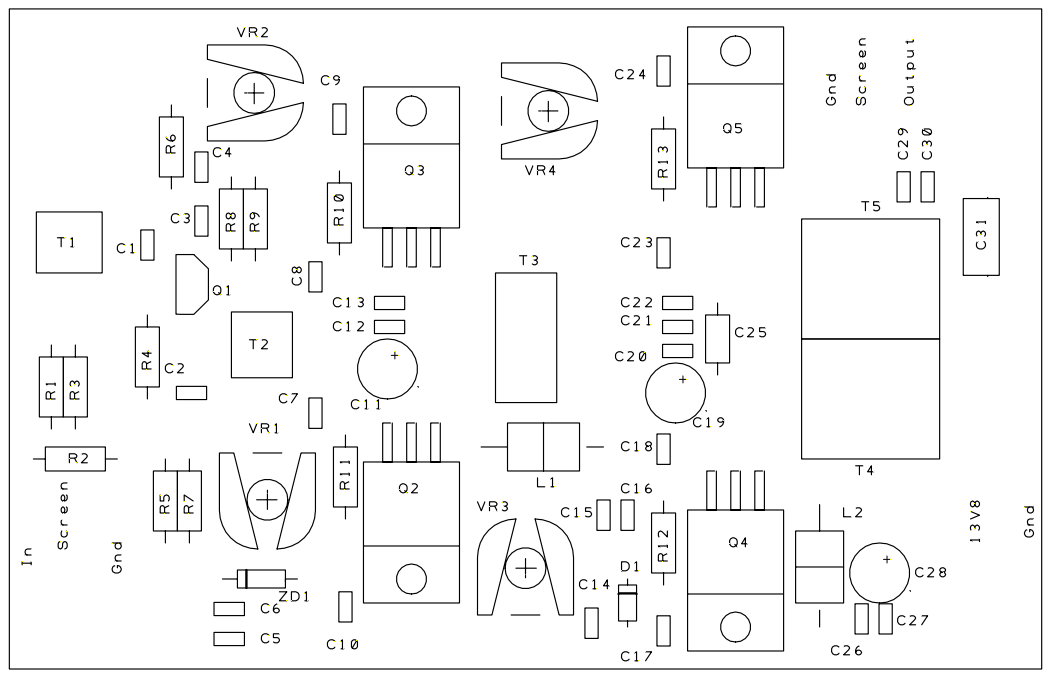
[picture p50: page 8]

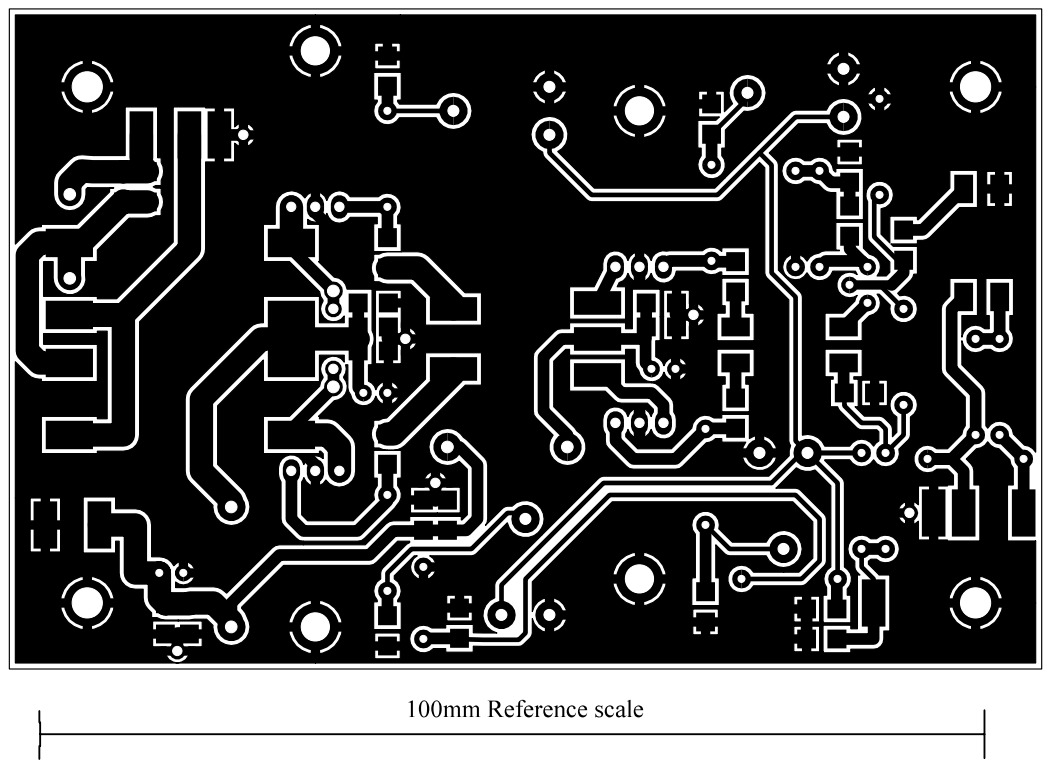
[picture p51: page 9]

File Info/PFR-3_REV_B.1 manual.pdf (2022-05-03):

## The PFR-3 Three band “Portable Field Ready” QRP CW Transceiver 40/30/20 meters Hendricks Kits – www.qrpkits.com KD1JV Designs

## Production manual 6/10/08 Rev B

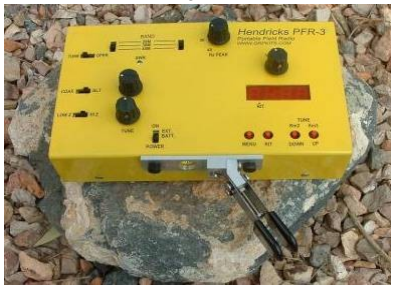
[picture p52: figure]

PFR-3 shown with optional paddle installed. Specifications:

Bands : 40 meters, 30 meters and 20 meters
Tuning range: Full band coverage
DDS VFO with 50 Hz slow tuning rate and 100 Hz fast tuning rate Mode: CW only

Receiver MSD: 0.2 uV typical
Selectivity : 300 Hz
Four crystal IF filter and 600 Hz center frequency audio band pass filter

Receive current, no signal typical:
Active, 47 ma
Idle, 34 ma

Transmitter:
5 watts at 12.0 volts, all bands
Transmitter current: 650 ma (40 M) to 750 ma (20 M) typical at 5 watts. Spurs: - 50 dBc maximum, all bands

5 to 40 wpm internal iambic keyer
Selectable A or B mode
Two (2) 63 character keyer memories.

Coax or balanced line output
Built in BLT (balanced line tuner)

Size: 7.2” wide X 4.2” deep X 1.5” high (less knob height).
Weight: 18 oz, no batteries installed.

Power supply voltage: 8 volts minimum, 12.5 volts maximum. 12 to 9 volts recommend. External power or internal battery pack

# Table of Contents

Group 1 assembly, Microprocessor and display:....5

## DDS frequency calibration and precise BFO

Group 5, SWR bridge and balanced line tuner:....12

## Mounting the board in the cabinet and final wiring:

The difference between A and B modes:.........17

## Using the BLT with end feed wire antennas or

PFR front panel controls and rear panel connectors.

Troubleshooting steps: Divide and conquer....20

Parts check list:

QTY | VALUE | | QTY | VALUE
1 | 10 ohms | Brown, black, black, gold | 1 | 4.7 p or 5p NPO | Disk, brown, black dot on top edge
1 | 51 ohms | Green, brown, black, gold | 3 | 22 p NPO | Disk, brown, black dot on top edge
4 | 470 ohms | Yellow, Violet, brown, gold | 1 | 47 p C0G | Disk, brown, black dot on top edge
11 | 2.2 K | Red, red, red, gold | 1 | 68 p NPO | Disk, brown, black dot on top edge
3 | 4.7 K | Yellow, violet, red, gold | 4 | 100 p C0G | Mono, yellow or NPO disk
1 | 7.5K | Violet, green, red, gold | 6 | 150 p C0G | Mono, yellow
5 | 10 K | Brown, black, orange, gold | 2 | 220 p C0G | Mono, yellow
1 | 51 K | Green, brown, orange, gold | 3 | 330 p C0G | Mono, yellow
5 | 22 K | Red, red, orange, gold | 1 | 560 p C0G | Mono, yellow
4 | 100 K | Brown, black, yellow, gold | 1 | 680 p C0G | Mono, yellow
2 | 330 K | Orange, orange, yellow, gold | 1 | 470 p DISK | Disk, brown
1 | 1 MEG | Brown, black, green, gold | 5 | .001 ufd disk | Disk, brown
1 | 50K audio | Vertical PCB mount | 7 | 0.01 ufd X7R | Mono, yellow
3 | 51 ohm 2W | Green, brown, black, gold | 14 | 0.1 ufd X7R | Mono, yellow
2 | SA612AN | 8 pin DIP IC | 2 | 0.01 ufd film | Film, green
1 | LM358N | 8 pin DIP IC | 1 | 30 p trimmer | Green
1 | LM386N | 8 pin DIP IC | 3 | poly-variable | Variable capacitor, dual section
1 | 74HC02N | 14 pin DIP IC | 2 | 10 ufd /16V or 25V | Aluminum electrolytic
1 | ATMEGA48 | 28 pin DIP IC | 1 | 22 ufd /16V or 25V | Aluminum electrolytic
1 | 78L05 | TO-92 plastic | 2 | 100 ufd /16V or 25V | Aluminum electrolytic
1 | 78L06 | TO-92 plastic | 1 | 330 ufd /16V or 25V | Aluminum electrolytic
1 | 1N5817 | Plastic diode shottky rectifier, 1A | 4 | 8 pin DIP sockets
1 | 1N4756A | Larger glass diode, 47V 1W zener | 1 | 14 pin DIP socket
3 | SD101C | Glass diode, fast shottky | 1 | 28 pin DIP socket
1 | FQPF7P06 | TO-220 plastic P MOSFET | 2 | FT37-43 | Ferrite core, gray or black
5 | 2N7000 | TO-92 plastic N MOSFET | 6 | T37-2 Red | Powdered iron core
3 | BS170 | TO-92 plastic N MOSFET | 2 | T37-6 Yellow | Powdered iron core
1 | 4 dig LED | 4 digit multiplexed display module, hi eff | 1 | T100-2 Red | Powdered iron core
1 | Super bright | LED clear | 4 | 6mmx13mm tack | Push button switch
2 | 10 uhy rfc | Brown, black, black, gold | 6 | DP3T slide switch
5 | 4.9152 MHz | Crystals HU-49US | 2 | Stereo jacks
1 | Power jack | 2.5 mm pin | 4 | Knobs
1 | BNC jack | | 1 | Red filter
2 | Binding posts | 1 Red, 1 Black | 1 | PC board
| | | 3 | | Sets of vari-cap mounting hardware
4 | 1/4” 4-40 screw | | 4 | #4 lock washers
| #30, #28, #24 | Magnet wire, #24 hook up wire | 6 | #4 Nylon washers
| | These parts are premounted
1 | AD9834BRUZ | DDS | 3 | 22 K | 0805 chip resistor
1 | 50.00 MHz clk | Clock oscillator | 1 | 22 p | 0805 NPO chip resistor
1 | 10 uhy | 1206 Choke inductor | 2 | 8 p | 0805 NPO chip capacitor
2 | 1.5 uhy | 1206 Choke inductor | 2 | 150 p | 0805 NPO chip capacitor
1 | 815C35UA | 3.5V low drop out regulator | 1 | 220 p | 0805 NPO chip capacitor
3 | 270 ohm | 0805 chip resistor | 4 | 0.01 ufd | 0805 X7R chip capacitor
1 | 3.9 K | 0805 chip resistor | 3 | 0.1 ufd | 0805 X7R chip capacitor
3 | 10 K | 0805 chip resistor

Parts placement overview.

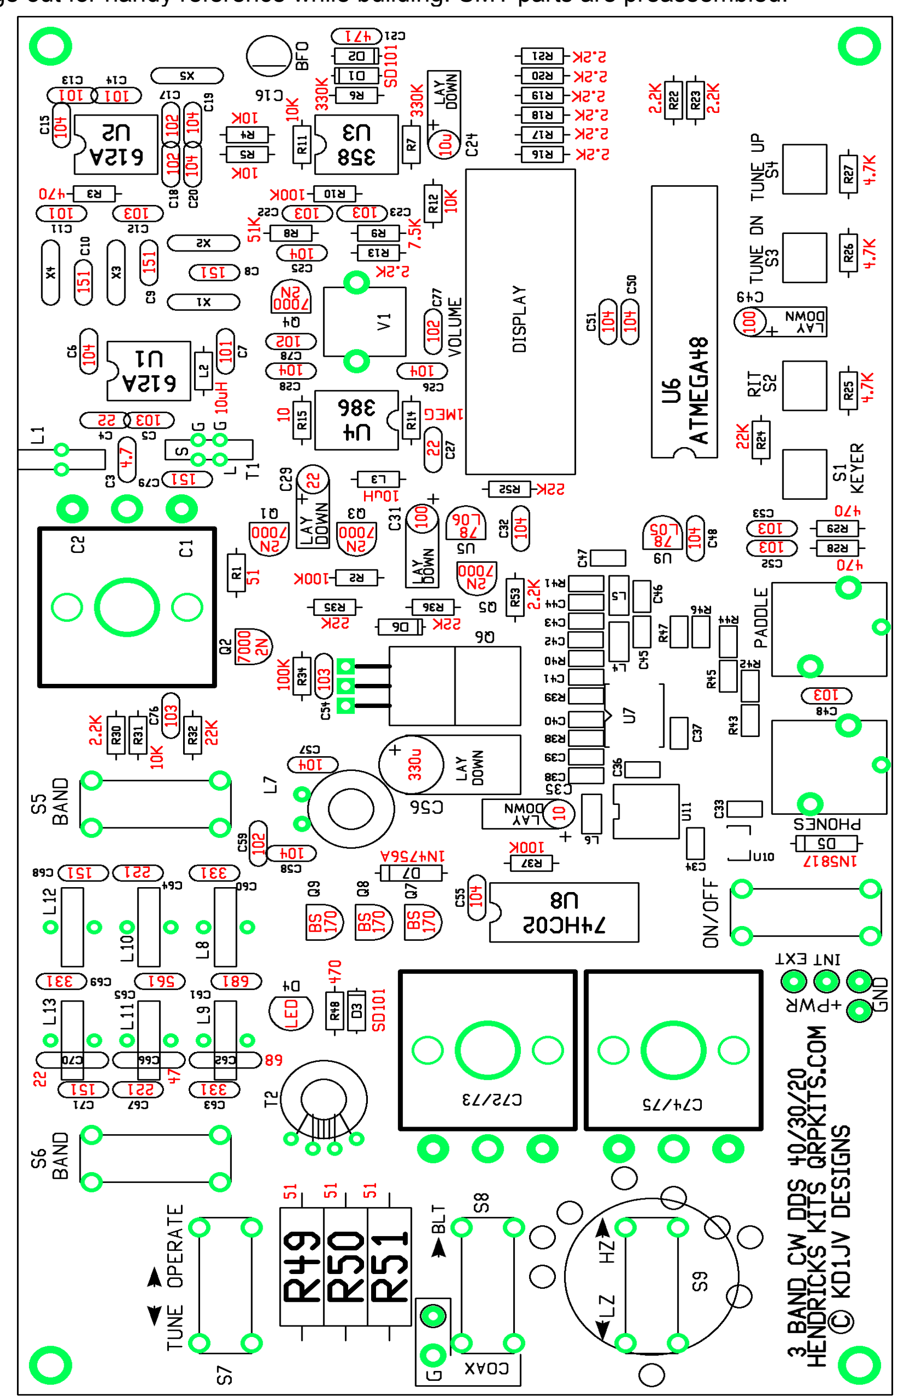
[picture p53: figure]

Print this page out for handy reference while building. SMT parts are preassembled.

Group 1 assembly, Microprocessor and display:

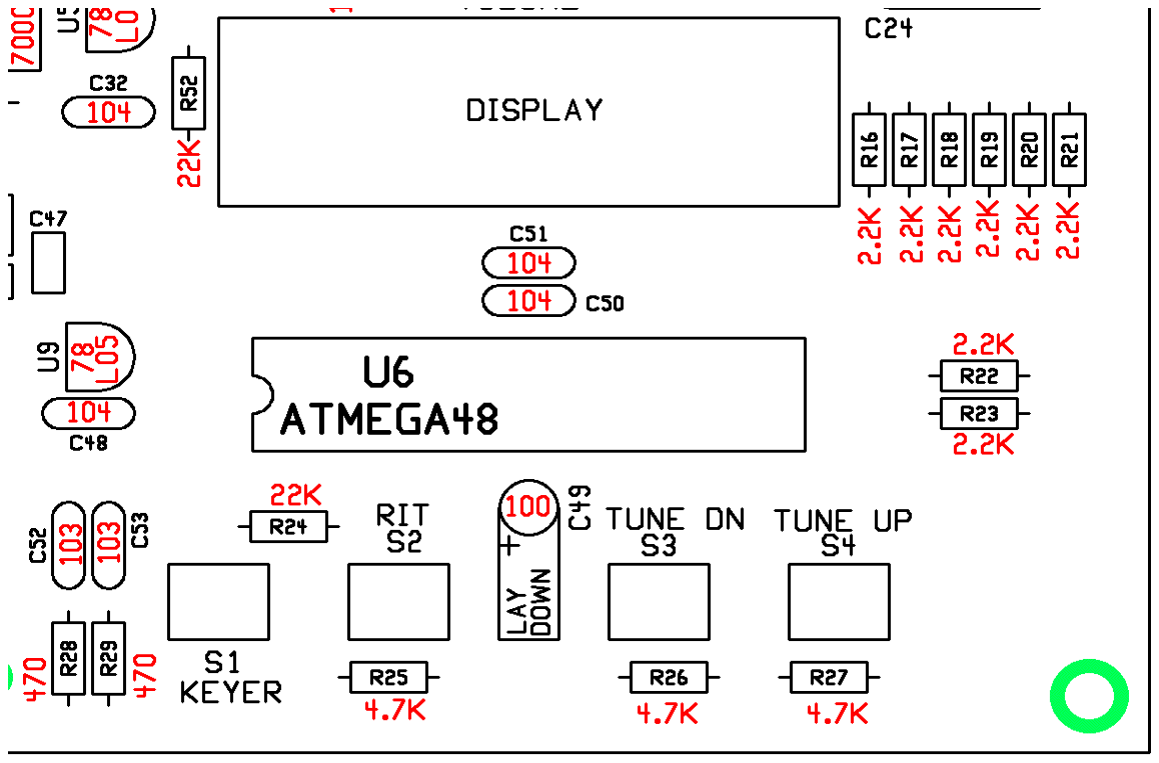
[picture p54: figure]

- R16 to R23 - 8 places. 2.2K (RED/RED/RED/GLD)
- R24, R52 – 22 K (RED/RED/ORG/GLD) – be careful not to mix up the 2.2 K and 22 K !
- R25 to R27 – 4.7 K (YEL/VOL/RED/GLD)
- R28 and R29, 470 ohms (YEL/VOL/BRN/GLD)
- C32, 48, C50, C51, 0.1 ufd (104, mono, yellow) [note, there is another C48 labeled on the board]
- C52,C53 0.01 ufd (103, mono, yellow)
- C49, 100 ufd / 16V (or 25V) Long lead is plus. Bend leads at right angle to part and lay part flat to board along extended outline. (You will do this with all the other electrolytic caps on the board too)
- U9, 78L05. Do not mix up with the 78L06 or 2N7000 which are in same TO-92 package.
- 28 pin dip socket at U6 When installing sockets, make sure all the pins are sticking out the holes in the board before soldering. If one or more pins happens to fold over under the socket as you insert it, it will be very difficult to remove the socket to fix this once you start soldering pins! Also make sure the notch is facing the right way.
- LED display module. This will only go in one way due to the missing pins on the display and corresponding missing holes on board. Space the display slightly from board so that the pins only stick out 1/32” from bottom of board. Solder two corner pins first, then double check to make sure the display is evenly spaced from the board and not tilted. Re-heating one pin will allow you to make adjustments.
- S1, S2, S3, S4 - Four (4) TACT switches. These have the long red actuators.

C48 location above SMT parts.

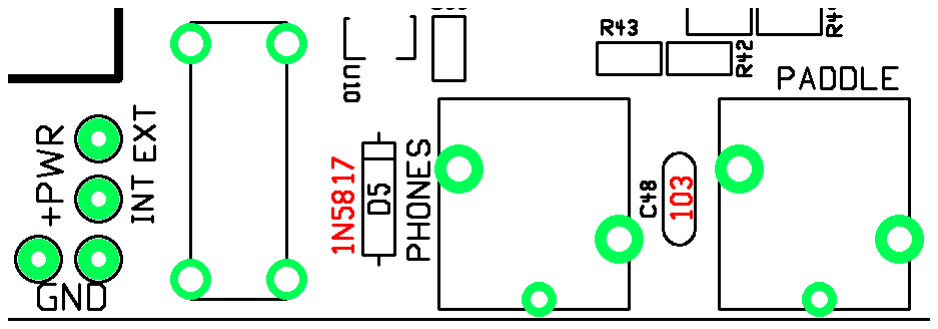
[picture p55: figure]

- D5, 1N5817 diode, black body. Band on part goes towards line on part outline.
- C48, 0.01 ufd (103) [C48 designation repeated on board by mistake, this one is located between the phone jacks and is labeled as C30 on schematic]
- Paddle and phone jacks.
- DP3T slide switch. (ON/OFF) – make sure switch is flush to board before soldering more than one mounting tab.
- C35, 10 ufd / 16V (or 25V) Again, long lead is plus and lay down part flat to board. Located above SMT parts, next to the R37 location.

Group 1 smoke test:

- Install the ATMEGA48 microprocessor chip into the U6 socket.
- Connect a 9 to 12 volt power supply to the power input pads next to the on/off switch. A 9 volt radio battery would be adequate for this test.
- Apply power to the board and turn on power switch if it is not already on.
- The LED display should light up with four “8”s for a second. This is the display test. Then the display should display “40” for another couple of seconds (indicating the band), then 030.0 (this is the frequency)
- Clicking closed the Tune UP or Tune DN switches should make the display increment or decrement.
- Clicking the RIT switch should make the left most decimal point on the display light up.
- The DDS chip should also be working at this point. This can be tested with a frequency counter connected to the R39/R41 junction at U7 or general coverage receiver tuned to about 2.115 MHz (+/- 1 kHz) with a short pick up lead for an antenna placed near the DDS chip (U7)

Group 2 Assembly, receiver section:

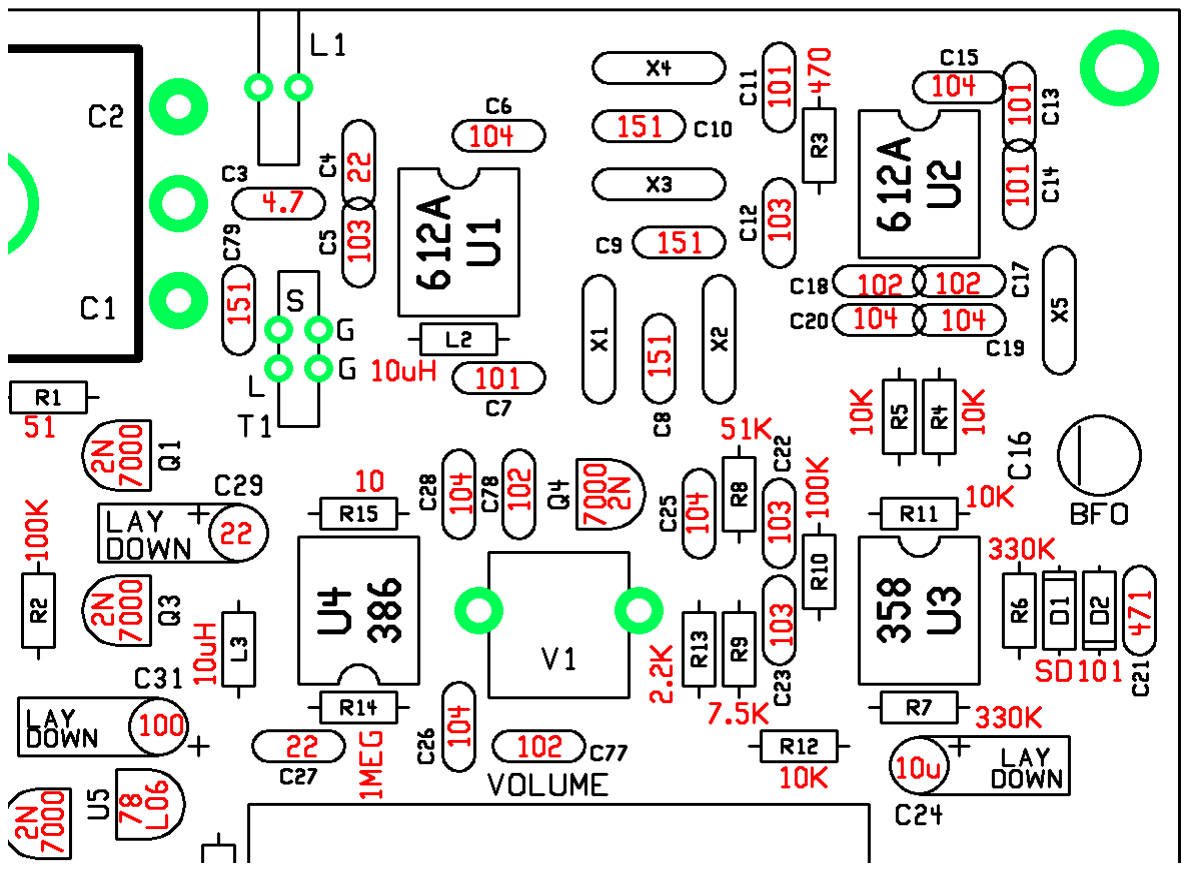
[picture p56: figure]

R15 | 10 ohm | BRN/BLK/BLK | C3 | 4.7 p or 5p | NPO, DISK | BROWN
R1 | 51 ohm | GRN/BRN/BLK | C4,C27 | 22 p | NPO, DISK | BROWN
R3 | 470 ohm | YEL/VOL/BRN | C7,11,13,14 | 100 p (101) | C0G | YELLOW
R13 | 2.2 K | RED/RED/RED | C8,9,10,79 | 150 p (151) | NPO, DISK | BROWN
R9 | 7.5 K | VOL/GRN/RED | C21 | 470 p (471) | DISK | BROWN
R4,R5,R11,R12 | 10 K | BRN/BLK/ORG | C17,18,77,78 | .001 u (102) | DISK | BROWN
R8 | 51 K | GRN/BRN/ORG | C22, C23 | 0.01 u (103) | FILM | GREEN
| | | C5, C12 | 0.01 u (103) | MONO | YELLOW
R10 | 100 K | BRN/BLK/YEL | C6,15,19,20 | 0.1 u (104) | MONO | YELLOW
R6,R7 | 330 K | ORG/ORG/YEL | C25,26,28 | 0.1 u (104) | MONO | YELLOW
R14 | 1 MEG | BRN/BLK/GRN | C24 | 10 u/16V or 25V | LAY FLAT | ELECTRO
L2,3 | 10 uHy | BRN/BLK/BLK/GLD | C29 | 22 u/16V or 25V | LAY FLAT | ELECTRO
| | | C31 | 100 u /16V or 25V | LAY FLAT | ELECTRO
D1,2 | Glass diode | SD101
U5 | 6V reg | 78L06 | Q1,2,3,4 | 2N7000 | MOSFET
NOTE: L2/L3 look like resistors, but the body is a little shorter and fatter. Do not mix up with 10 ohm resistor. Also, be careful not to mix up 51 ohm resistor with 1 MEG, as colors are very similar.
X1,2,3,4,5 | Crystals | Tack solder case to solder pads next to crystal case. Running fine grit file along
| | edge of crystal case will make the solder easier to stick.
C16 | 30 p trimmer (Green) | Make sure flat side of trimmer faces line on outline. This can be mounted to bottom side of board for easier access once board is wired into cabinet.
U1,2,3,4 | 8 pin sockets | Make sure all the pins come through the board holes!
V1 | 50 K variable resistor | Solder mounting tabs to board.
| The following parts | mount on Bottom of board
C1/2 | Poly-varicap | Mounts on bottom of board. Use 2.5 mm washers between board and cap.
L1 | T37-2 (red core) | 40 turns, 24” of # 30 wire
T1 | T37-2 (red core) | 40 turns (#30) secondary, 5 turns primary see next page for winding details.

L1 and T1 are mounted on the bottom side of the board!
T1 winding: Wind with # 30 wire. T1 must be wound in a specific way so that the “hot” end of each winding will end up on the same side of the core and line up with the proper holes in the board. Wind the core in a counter clockwise direction, passing the wire down into the hole from the top side of the core as you hold it. At the end of 40 turns, make a short loop and continue winding five (5) more turns. The start and end wire ends will go into the two pads towards the top edge of the board, with the start end going into the pad labeled “S”. The wire which makes the loop will be sniped to separate the wire and these go into the two

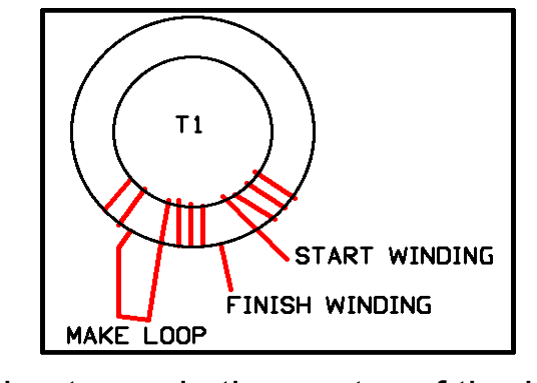
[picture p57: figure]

holes towards the center of the board. It is important to get the windings in the proper holes or the receiver sensitivity will be poor.

## Group 2 smoke test:

Install U1 and U2 (SA612A) into sockets
Install U3, LM358
Install U4, LM386 NOTE : U4 pin 1 faces “down”, the opposite direction of U1, U2 and U3

The receiver section is now done and should now be functional. Give the BFO trimmer (C16) about a ¼ turn from its factory setting. If you look closely in the trimmer hole, you will see an arrow at one end of the screwdriver slot. When the arrow points towards the flat side of the body, it is a maximum capacitance. When it points to the round end opposite the flat end, it is at minimum. Using leads connected to the BNC connector, you can tack these wires across R1 in order to connect up an antenna (make the connections on the bottom of the board). The end of R1 near Q1 is the signal side of the resistor. Apply power to the board and you will be receiving in the 40 meter band. Adjust the Rx tuning cap (C1/2) for best band noise or signal. The peak should occur near full counterclockwise rotation. Plugging in a paddle to the paddle jack and then operating the paddle should result in hearing the side tone sending dits and dahs. The MENU function switch annunciations can now also be heard.

DDS frequency calibration and precise BFO setting adjustment:

If you have an accurate frequency counter, the DDS frequency can be calibrated. Without calibration, the operating frequency maybe off as much as +/- 200 or 300 Hz on the 20 meter band and to lesser extent on the lower bands. This is due to variations in the reference clock oscillator for the DDS chip. Calibration is done at 10.000,000 MHz, so it could be possible to zero beat WWV, but it is better left alone if an accurate frequency counter is not available. It is also possible to tweak the IF offset frequency so that it is centered in the passband of the crystal filter. This adjustment is done with the aid of an Oscilloscope, which could be a virtual one running on PC, as all you need to see is audio frequencies. The IF offset adjust mode is also used to set the BFO trimmer to match the side tone of the rig and this can be done by ear.

Entering Calibration modes:
While holding the DOT paddle and MENU switch closed, turn power on to the board. The LED display will read [CAL.r].

Reference frequency calibration:

A frequency counter connected to the TP1 test point near the DDS chip will now read about 10 MHz. Use the Tune up and Tune down switches to adjust the frequency to be exactly 10.000,000 MHz. Once this is done, store by clicking the KEYER switch. Or you can skip this adjustment by clicking the KEYER switch. This will store the default values and advance to the offset adjustment

IF offset adjust and BFO trimmer set:

Once the MENU switch has been clicked, the LED display will now read [CAL.o]. Connect an Oscilloscope to Pin 7 of U3. You will see the audio product detector beat note on this pin. If you do not have an Oscilloscope, do not make any adjustments to the IF offset frequency and just go do the BFO adjustment.

Tune through the pass band of the crystal filter using the tuning switches. You will likely see the amplitude of the signal peak a little at the edge of the pass band, just before the amplitude rolls of sharply. Tune to one end of the pass band, the point the amplitude of the signal starts to roll off. Count how many clicks of the tuning switch it takes to get to the other end of the pass band. Divide that number by 2 and tune back up or down depending on which way you went initially by that number of clicks to center the frequency in the pass band of the filter.

BFO adjustment:

Plug headphones into phones jack and you will hear the side tone and BFO beat note. Adjust the volume control until they have about the same volume. Adjust the BFO trimmer until both tones are the same. The tones will wobble when they get close to being equal and seem to merge when they are. This can also be seen on an Oscilloscope. Once you match the tones, store the adjusted IF offset or leave the default values in place by clicking the MENU switch The rig will now reset.

Group 3 assembly: Transmitter section.

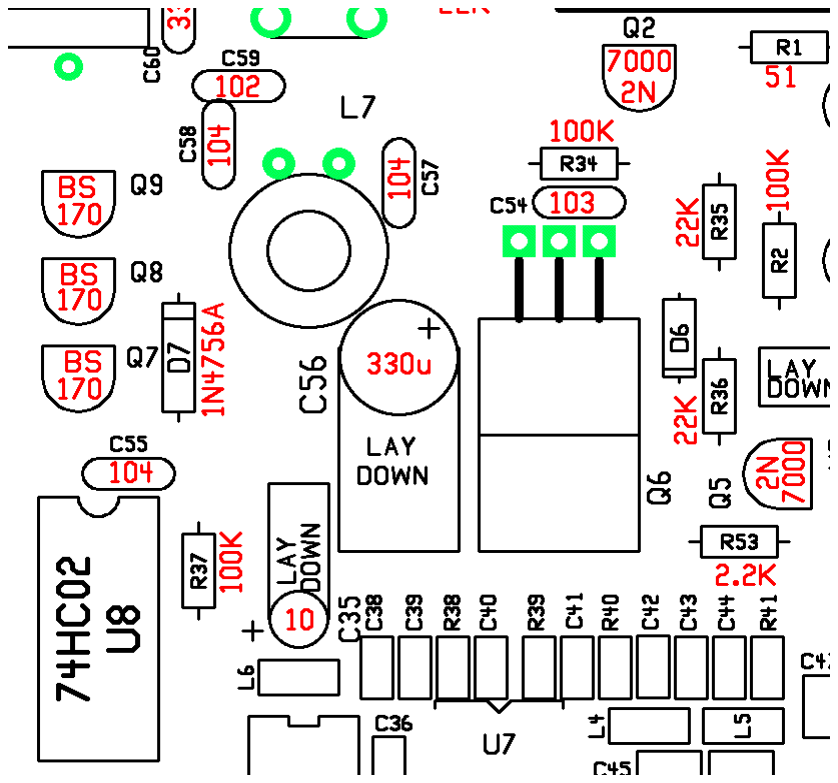
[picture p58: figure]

Pretests:
Before installing L7, we need to make a few tests first.
- Make sure R37 is 100K!
- Put rig in straight key mode by applying power with dash paddle closed or use straight key. If using paddle, dot paddle will now key the transmitter.
- Measure the voltage on pins 3 and 11 of U8. They should read about 3.5 volts. If not, check soldering of R37 and check for 5 volts on pin 14.
- Measure the voltage on pins 1 and 13 of U8. They should read 0 volts.
- Key the transmitter and measure the voltage on the L7 pad to the right, next to C57. The voltage should be about the same as the supply voltage to the board. If not, check the connections and proper values of R34, R35 and R36. Also check Q5.
- With the transmitter keyed, check the voltage on pins 1 and 13 of U8 again. These should now read about 2.5 volts. Since these pins now have a square wave at the transmitter frequency on them, exactly how a DVM responds to this signal may depend on the particular DVM used.
- If all these tests are OK, it is now safe to install L7.
R53 | 2.2 K | RED/RED/RED
R35, 36 | 22 K | RED/RED/ORG
R2,R34,R37 | 100 K | BRN/BLK/YEL
D6 | Not used
D7 | 1N4756A | Glass diode, large
C54 | 0.01 ufd (103) | MONO, Yellow
C55, 57, 58 | 0.1 ufd (104) | MONO, Yellow
C59 | .001 ufd (102) | Disk, brown
C56 | 330 ufd/16V or 25V | Electro lay flat
Q5 | 2N7000 | TO-92
Q7,8,9 | BS170 | TO-92
Q6 | FQPF7P06 | TO-220
U8 | 14 pin socket | 74HC02A IC
DO NOT | MOUNT L7 YET | Do pretests first
L7 | 8 T on FT37-43 | 8” #28 black core

Group 4, low pass filters:

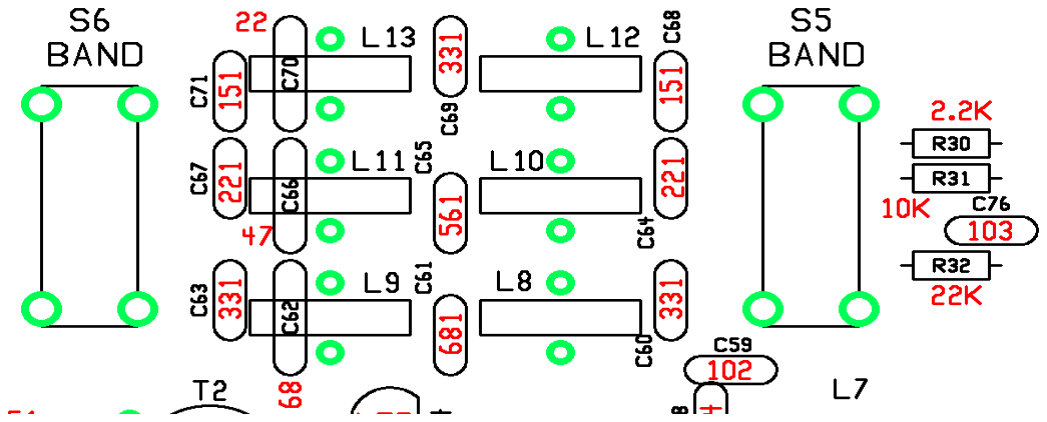
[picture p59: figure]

R30 | 2.2 K (RED/RED/RED)
R31 | 10 K (BRN/BLK/ORG)
R32 | 22 K (RED/RED/ORG)
C76 | 0.01 ufd (103, mono)
C68,C71 | 150 pfd (151, mono)
C67,C64 | 220 pfd (221, mono)
C69,C63,C60 | 330 pfd (331, mono)
C65 | 560 pfd (561, mono)
C61 | 680 pfd (681, mono)
C62 | 68 pfd (68, disk)
C66 | 47 pfd (47, disk)
C70 | 22 pfd (22, disk)
Low pass filter | Coils mount from bottom | Of board!
L8 | 17 turns on T37-2 | Red core 10” #28
L9 | 19 turns on T37-2 | Red core 10” #28
L10 | 13 turns on T37-2 | Red core 8” #28
L11 | 15 turns on T37-2 | Red core 8” #28
L12 | 14 turns on T37-6 | Yellow core 8” #28
L13 | 18 turns on T37-6 | Yellow core 10” #28
S5, S6 | DP3T slide switch

Group 5, SWR bridge and balanced line tuner:

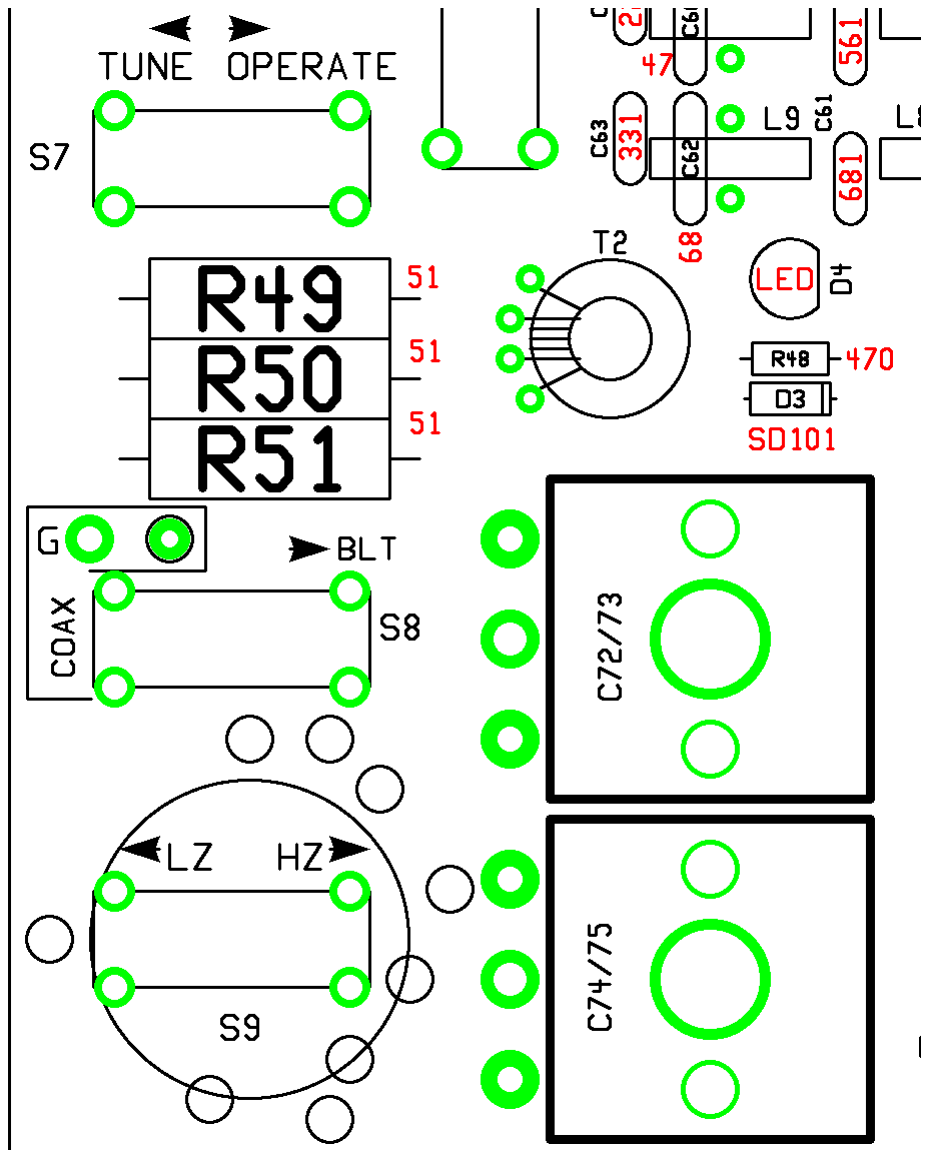
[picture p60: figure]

- R48, 470 ohm (YEL/VOL/BRN)
- R49, R50, R51 - 51 ohm, 2 watt (GRN/BRN/BLK)
- D3 – SD101, small glass diode
- D4 – clear LED – Align flat side of LED with flat on part outline. Long lead goes into hole opposite the flat. Space bottom of LED 5/16” from top of circuit board.
- S7 – DP3T slide switch
- S8 - DP3T slide switch
- S9 – DP3T slide switch – this mounts above T3. Cut pins flush to board after soldering.
- T2 – Black FT43-37 core. Use # 28 wire and wind 25 turns as secondary and 5 turn primary in middle between ends of the secondary turns. Secondary ends go to into the two outside holes and the primary goes into the two middle holes.
- T3 – Mounts on bottom of board. Core is about same diameter as the mounting holes for the wire connections. See below for winding and mounting details.
- C72/73 and C74/75 Poly-variable capacitors. Mount on bottom of board with 2.5 mm washers on screws between board and body of capacitor. These washers space the body of the cap slightly from the bottom of the board. Adjust the trimmers on the bottom of C74/75 to be fully meshed.

Winding T3:

- Cut a 30” (2 1/2 foot) length of the # 24 wire.
- Wind 11 turns on the T100-2 core (this is the large red core)
- Start the winding of the core by passing the starting end of the wire into the hole from the top (side facing you as you hold it) and wind by passing the long end of the wire up from the bottom of the core. Wind the rest of the turns in a counter clock wise direction. Winding the core in this fashion will make the ends of the wire more or less line up with the staggered holes in the board. Try to wind the wire fairly flat to sides of the core.
- Pull the 6th turn slightly away from the middle, outside edge of the core. (this is actually turn 5 ½)
- Scrape away the insulation on the wire of this 6th turn, just a little near the middle of the core.
- Cut a 2” length of the # 24 wire and tin one end.
- Attach this wire to the 8th turn on the core. Make a small, half loop on the end of the wire and lightly crimp to wire on core, then solder.
- Cut a 18” length of the # 24 wire and wind 6 turns inter-weaved between the first winding and centered around the tap you just made, so there are 3 turns on either side of the tap. It is easiest the start the winding of these turns from the center tap of the first winding.
- Now cut a 8” length of the # 24 wire and wind 1 turns on either side of the tap, for a total of 2 turns. This winding will also be inter-weaved between the other two windings.
- Push the windings together so they are close to each other and not spaced around the core.
- The core is mounted to the bottom of the board and the wires are soldered from the top. Suspend the core slightly off the bottom of the board so that the wires do not touch the ends of the switch mounted above it. In fact, it is a good idea to snip the ends of the switch terminals flush to the board before mounting the coil. Be careful not to put the High Z winding into the pads marked “OUT”, as these pads will connect to the binding posts on the cabinet.

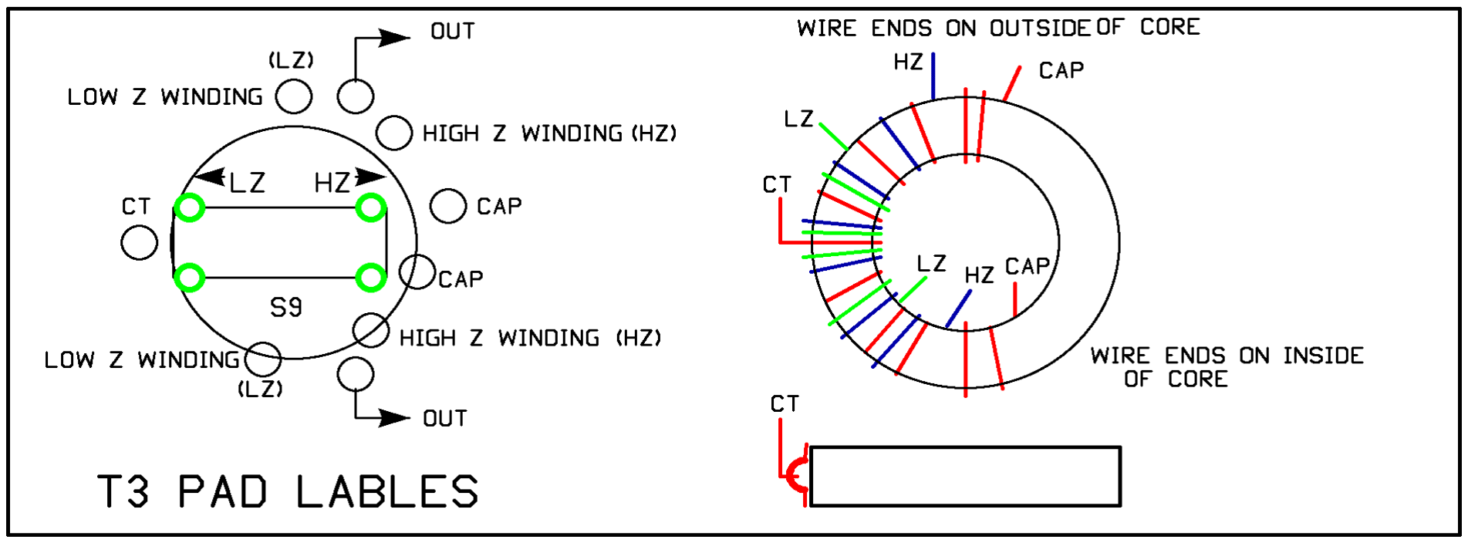
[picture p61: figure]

This diagram shows how the wire should be wound on the core so the wire ends more or less line up with the mounting holes in the board. The LZ winding is shown with an extra 2 turns.

## Final tests:

The board is now complete and the only thing left to test is the transmitter. Connect the BNC jack to the COAX terminals on the board by S9. Now connect a watt meter and dummy load to the jack. Make sure both BAND switches are set to the same band, you might as well start with 40 meters. Set the Tune / Operate switch to the operate position and the COAX / BLT switch to the coax position. Apply power to the board and send some dots. There should be some power output showing on the watt meter. If not, remove power and start looking for missing solder connections, that the insulation on the toroid coils has been soldered through and that both band switches are in the same position. If you see power output, go on and check the other two bands.

Power output
Power output is influenced by both power supply voltage and the way in which the turns on the transmitter low pass filter coils are spaced around the core. To measure full power output, put the rig in straight key mode or use “Tune” mode. With a 12.0 volt supply, power output should be close to 5 watts on all bands, with the possible exception of 20 meters, which seems to be running more like 4.5 watts on average. If power output is higher than 5 watts, move some of the turns on L8, L10 or L12 (depending on the band) closer together and recheck the power output. Repeat if needed to get close to 5 watts output. If power out is less than 5 watts, try making the spacing of the turns more evenly spaced around the core. If power output is significantly lower (or higher) than it should be, double check the number of turns on the coils. Remember, a turn is each time the wire passes through the center of the core. Having one extra turn is common, as many forget to count the first turn when the wire is initially passed through the center of the core. This can have a significant affect on the power output.

## Mounting the board in the cabinet and final wiring:

It is possible to enlarge the holes for the three tuning caps with a step drill so that the knobs are recessed and reduce the overall height of the rig. You will also need to cut down the nylon spacers and screw. If you decide to do this, be careful – you don't want to scratch the paint job on the cabinet!
- Solder the end of a 4.5” length of hook up wire to each of the pads labeled “OUT” under T3. These wires attach to the bottom side of the board. Since T3 covers these holes, the solder connections are made from the top of the board.
- Tape the red acetate filter to the inside of the led window.
- Slide the board into the top piece of the cabinet at an angle with the phone jacks at the front of the board down. To ease mounting, place all slide switches to the center position. Be careful not to bend the SWR led.
- Center the phone/paddle jacks in the chassis holes, and secure the board with the 4-40 x 1/4” screws and lock washers.
- Attach the nylon spacers to the tuning caps with the screw and 2.5mm lock washer. A small drop of super glue into the screw hole on the tuning cap will help keep the screw from coming loose. (You may want to wait until you are sure you will not have to remove the board from the cabinet for some reason before gluing the screw in place)
- Push the brass knob extension all the way down onto the volume control and secure the knob with the set screw. (Personally, I prefer not to use a knob on the volume control, KD1JV)
- Place the three knobs on the tuning caps. Set the knob as low as it can go without rubbing against the cabinet
- Mount the two binding posts, DPDT toggle switch, Coax jack and external power jack to the rear of the cabinet.
- Wire up the binding posts, switch and coax jack as shown in the diagram below. The wires going from the coax jack back to the board should be tightly twisted together and take a direct path back to the pads on the circuit board. The red wire between binding post, switch and coax connector is optional.

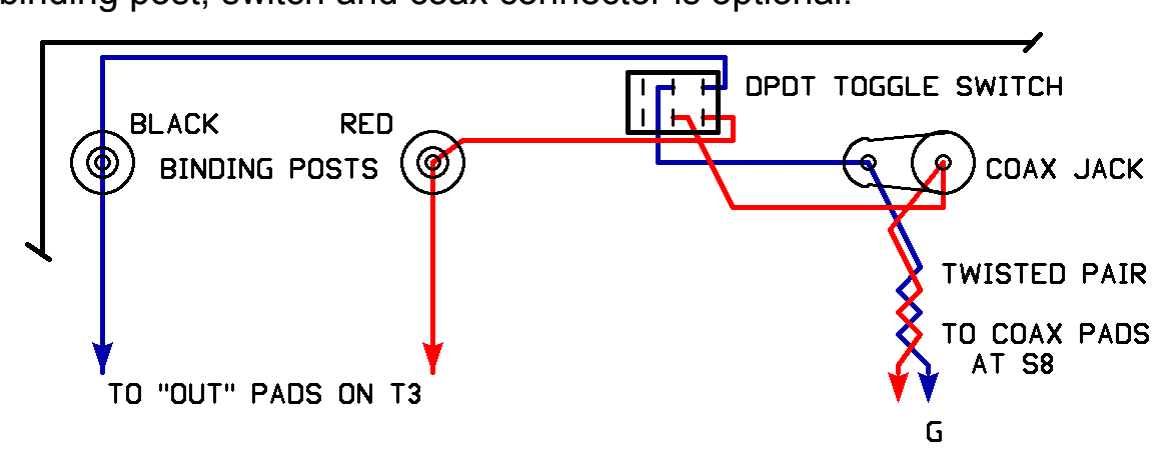
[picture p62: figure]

- Twist two 8” lengths of hook up wire together.
- Solder to external power jack
- Solder the other end to the EXT and GND pads next to the On/Off switch
- The wire for connecting to the power jack to the board should be routed along the outside edge of the board.

Once the wiring from the board to the rear panel is completed it is still possible to remove the board from the cabinet but it is a little tricky to do. Remove the mounting screws and gently push the board towards the rear of the case to free the phone jacks from the holes in the front of the case. Then gently angle the board up. When remounting the board, the main problem might be getting the SWR LED to line back up with the hole.

Photo of final panel wiring

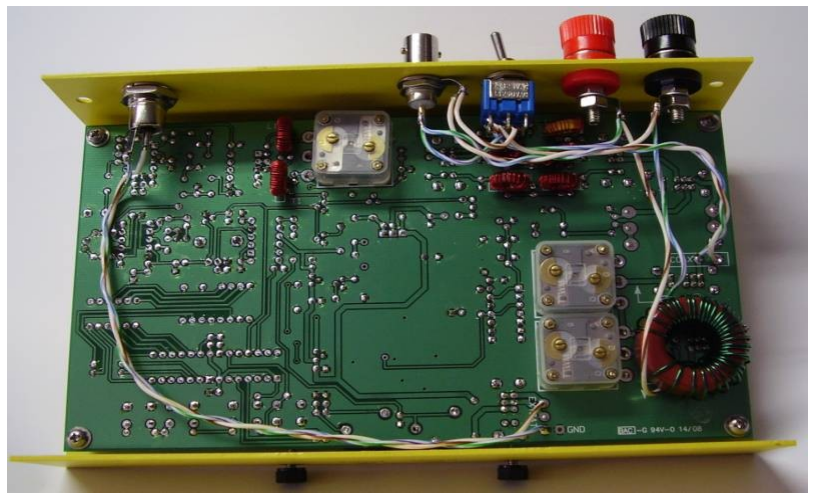
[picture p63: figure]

Battery holder mounting:

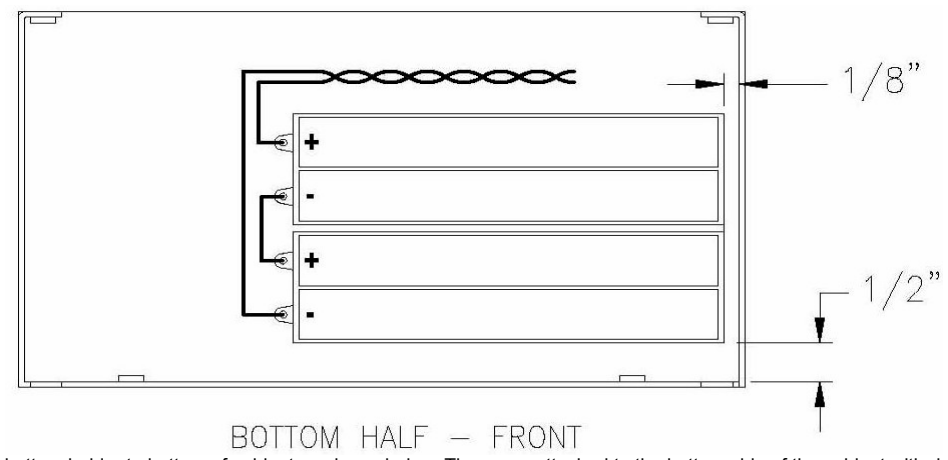
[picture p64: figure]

Mount battery holder to bottom of cabinet as shown below. These are attached to the bottom side of the cabinet with double sided tape, which is already attached to the bottom of the holders. Leave a small space between the sides of the battery holders as when the batteries are installed it will billow out the sides a little. Connect wires to the battery holder terminals as shown the diagram below. Be quick about soldering the wires, as the plastic will melt if you leave the iron on too long. Wire the [+] terminal to pad labeled “BAT” next to power switch and the [-] terminal to the pad labeled “GND”

Fuses:

There are no fuses built into the rig but it is a good idea to add one. A fuse could prevent damage to your power supply or even a fire if something should go wrong. For the external supply, use a power cord with an in-line fuse holder and use a 1.5 or 2 amp fuse. Adding a fuse to the battery pack is a bit more of a problem. A 2AG sized fuse holder could be added to the bottom half of the cabinet just above the battery pack and located so it sits between the power jack and receiver input coils.

## Operation:

Power supply:

The PFR-3 rig should be powered by no more than about 12 volts and no less then 8 volts. Maximum supply current at full transmitter output is typically less than 800 ma. If a 13.8 volt bench supply is used to power the rig, two silicon rectifier diodes should be added in series with the positive supply lead to drop the voltage down closer to 12 volts. This will ensure the rig does not put out more than about 5 watts. 5 watt output at 12 volts was chosen as this is the typical voltage a gel-cell battery settles down to after it has been removed from its charger. Below 8 volts, the 6 volt regulator for the receiver will start to loose regulation. Since transmit power output is dependent on supply voltage, a variable supply is a handy way to adjust the power output level. At the minimum supply voltage of 8 volts, the transmitter will deliver about 2 watts output. Transmitter current will also be reduced at lower supply voltages, extending battery life.

Power switch:

The power switch has three positions. OFF, Internal (battery) power and External power.

When the rig is first turned on, the display will show all “8”s for a second. This is the segment display test. Then the display will indicate the currently selected band , “20”, “30” or “40”. The band numbers will be displayed for a couple of seconds, then the display will change to show the operating frequency. Since only four digits are available, only the 100 kHz to 100 Hz digits are displayed. MHz digits are implied by the currently selected band. The initial operating frequencies loaded when the rig is powered on or the band is changed are 7.030,000 MHz for 40 meters, 10.110,000 MHz for 30 meters and 14.060,000 MHz for 20 meters.

Power save mode:

After about 5 minutes of no switch activity the rig will go into a power save mode by blanking the display and the processor is put to sleep. The decimal point will stay on to indicate that the rig still has power applied. This will reduce the supply current from about 47 ma to 34 ma. Not a huge current savings, but if the rig is being run on batteries every ma counts. The rig will “wake up” if any switch (other than Band) or the paddle is used.

### Selecting operating band:

Two slide switches are used to select the operating band. Both switches MUST be in the same band position for proper operation. The band switch located near the top, center of the cabinet tells the processor which band you want to use and will indicate the selected band on the display for a second when the band is changed or on power up, as noted above. The switch located near the top, left of the cabinet is used to connect the output of the low pass filter to the antenna. If the two band switches are not in sync, there will be no signals in the receiver and the transmitter might be damaged if you transmit at this time. If you change bands and then return to a previously used band, the frequency the rig was tuned to on that band will be restored. This feature could be handy if your jumping between bands in a contest. Operating frequencies are lost when power is turn off and the rig will load the default frequencies again on power up.

After you change bands, you must re-peak the receiver input with the Rx peak control.

## Tuning:

Tuning is done with two push button switches. These switches are operated best by “clicking” them to the side, rather then pushing straight down. Tuning steps are in 50 Hz increments. A momentary click of the switch will change the frequency by 50 Hz. Since the display only has 100 Hz resolution, it will take two clicks of the switch to see a change of frequency on the display. Holding one of the tuning switches closed for longer than about one (1) second will start an auto tune mode, where the frequency will change in 100 Hz steps at a rate of about 10 steps per second, so long as the switch is held closed.
When the switch is released, normal 50 Hz “one click” tuning is restored.

Note: If you are in the fast tuning mode and quickly change tuning directions, the tuning may continue the direction that it was in. This is because there is a slight delay between releasing the switch and the processor detecting that a different switch has been closed.

Tuning limits:
Tuning is restricted to be within the currently selected ham band. This is to prevent out of band transmission. Full band coverage is available. 7.000,000 to 7.300,000 on 40, 10.100,000 to 10.150,000 on 30 and 14.000,000 to 14.350,000 on 20. Even though you can tune into the phone band, SSB signals will not be intelligible due to narrow CW filter.

RIT (receiver incremental tuning)

Clicking the RIT switch will activate RIT. The left most decimal point on the display will light when you are in RIT mode. When in RIT mode, the receive frequency is changed by the tuning switches and the transmit frequency stays were it was when RIT was activated. Clicking the RIT switch again will exit RIT mode and restore the original receive frequency. If RIT is on when the band is changed RIT will be automatically turned off.

DFE mode (direct frequency entry)

This mode allows you to go directly to a specific frequency by entering it in with the paddle. Clicking and holding closed the RIT switch for longer than one (1) second will activate this mode. The display will change to display [- - -.-] when DFE mode is enabled. Enter the frequency you wish to go to, starting with the 100 kHz digit and finishing with the 100 Hz digit. As each digit is entered, it will be shown on the display and shift from right to left as additional digits are entered. If a number is not recognized, a “?” will be sent by the side tone. Once the 100 Hz digit is entered, the rig will re-tune to that frequency provide it is within the normal tuning limits of the current band. If it outside the band, the frequency at which the rig was tuned to when DFE was enabled will be restored and DFE mode exited. If you make a mistake or wish to exit the DFE mode at anytime before the 100 Hz digit is entered, you can escape by clicking any of the switches.

Note: DFE mode is not available in straight key mode or if RIT is on.

MENU switch (Keyer functions) :

The MENU switch is used to access various keyer functions. Which function is selected is determined by how long the switch is held closed. Keyer functions are selected in this order: send message, change keyer speed, TUNE mode, enter messages and select iambic A or B mode of operation. Note: When in straight key mode, none of the MENU switch functions are available, with the exception of sending keyer message 1, assuming a message is already stored in that location.

Sending a Message:
Two, 63 character (including word spaces) Morse messages can be stored in memory. One of these messages can be sent by first clicking and releasing the KEYER switch and then tapping the DOT paddle to send message one, or tapping the DASH paddle to send message two. This must be done within 1 second of releasing the switch or the change code speed mode will be activated. Once a message has started sending, it can be terminated by closing the DOT paddle. If a character is being sent at the time of dot or dash closure, it must be held closed until that character has finished being sent.

When in straight key mode, only message 1 is available, as the DASH input is always grounded by the straight key plug.

Changing keyer code speed:

If sending a message has not been selected using the paddle after clicking and releasing the MENU switch, speed change mode will be activated. The current code speed is shown on the display as [C xx], where xx is the current speed. Keyer speed is changed by closing either the DOT paddle to increase speed or closing the DASH paddle to decrease speed. The selected speed is shown on the display. Once the desired speed is indicated on the display, release the paddle and wait about two (2) second and speed select mode is automatically exited.

Tune Mode:
This mode is used if you have an automatic antenna tuner which needs to see a steady carrier for a few seconds to operate. For manual tuners, it is easier and less stressful on the PA to simply send a string of dots as you fiddle with the tuner.

To enable tune mode, click and hold close the MENU switch until the letter “T” is annunciated by the side tone and release the switch. When you then release the MENU switch, the display will blank and a character which resembles a lower case “t” will appear on the left most digit. The transmitter can now be keyed by closing and holding closed either the dot or dash paddle. When you wish to return the rig to normal operation, click any of the switches.

Storing a message:

Holding closed the MENU switch for four (4) seconds will active the message entry mode. Release the switch when the letter “M” is annunciated by the side tone, which occurs after the tune mode letter “T” has been annunciated. The receiver is then muted and you can now start to enter your message by using the paddle. If you accidentally activate this mode and do not wish to enter a message, click the MENU switch to abort before touching the paddle. The Letter “X” will be annunciated and the rig will go back to normal operation. There is no visual indication that message entry mode is active.
Up to 63 characters (including word spaces) may be entered. If you exceed this limit, the letters “EM” will be annunciated by the side tone and you will have to start again. Note that “ideal” letter and word timing is used to determine letter element groups and word groups. Of these two, the letter timing is most critical. If do not pause long enough before starting a new letter, a letter space will not be detected. If you pause too long, it will be interpreted as a word space. It may take some practice to enter a message correctly. I ensure a word space is inserted, it is best to pause somewhat longer than you normally would between word letter groups.

When you have finished entering the message, click the MENU switch. The message you have entered will be sent by the side tone so you can check the accuracy of the message. If it sounds good, store it by closing either the DOT or DASH paddle. DOT will store it into message location 1 and DASH into location 2. If you wish to redo the message, click the KEYER switch again. “EM” will be annunciated by the side tone and you can now re-enter the message.

Selecting Iambic A or B modes.
Iambic A mode is the default keyer mode. To switch to B mode or back to A mode, hold the MENU switch closed for about four (4) seconds until the letter A or b appears on the display (b looks like a 6 on the display) then release the switch. The letter which appears on the display will be the mode the keyer will be set to when you release the switch. The Morse letter “A” or “B” is also annunciated by the side tone.

The difference between A and B modes:
In A mode, if both paddles are closed at the same time, alternating code elements are sent. If you close the dash paddle first and then hold both the dash and dot paddle closed, the keyer will send dah-dit-dah-dit-dah so long as the paddles are held closed. When the paddles are released, the keyer will simply stop sending at the end of the code element which might be being sent at the time the paddles are released, if any.

In B mode, alternating code elements are also sent when both paddles are closed, but this time an extra and opposite code element will be tacked on the end of the string when the paddles are released. Therefore, to send a letter such as “K”, you just have to close the dash paddle first, then close the dot paddle and release both paddles when the dot starts to be sent. dah-dit-dah will be automatically sent. In A mode to send this same letter you would have to keep the dash paddle closed until the second dash has started to be sent before releasing the paddles.

In B mode, the “both paddles closed” condition is sensed at the end of the inter-element space. Therefore, to insert an extra element, both paddles need to be held closed at least until the next to last element you want to send is has started. If the “both paddles closed” condition is sensed any earlier, it is nearly impossible to send a simple letter such as an “A” or “N” and not have a “R” or “K” be sent instead. Even so, it is easy to accidentally add an extra element if your not quick to release the paddles which makes B mode a bit difficult to get the hang of with out a lot of practice, especially at higher code speeds.

Both A and B modes have dot and dash memory while an element is being sent. So, if you tap the dot paddle while a dash is being sent, the dot will be sent after the dash is finished and vice-a-versa.

Straight key mode:

If a monaural plug is in the paddle jack at power up (the sleeve grounds the dash input pin), the rig will power up in straight key mode. This allows using either a straight key or external keyer. While in straight key mode, none of the keyer switch functions will be available. If a message has been previously stored in the keyer memories, only memory location 1 will be available, (tap the straight key closed with in 1 second of clicking the keyer switch) as this is selected with the dot input pin, now controlled by the straight key.

Using the SWR bridge and BLT tuner:
Note that S7, S8 and S9 are three position switches but only two positions are used. The two positions to the left are the same.

TUNE / OPRT SWITCH:

Sliding S7 to the TUNE position switches in the SWR bridge. The LED will now indicate the relative amount of SWR. The brighter the LED, the higher the SWR is. When the LED is not lit or is very dim indicates 1:1 SWR.

COAX / BLT SWITCH

S8 is used to switch between a direct coax connection to the BNC jack or the BLT (balanced line tuner). The Coax position is of course used if you are using a resonate, coax feed antenna or an external tuner. The BLT position is used when the built in tuner is desired and is normally used with ladder line feed antennas, but can also be used for end feed antennas or possibly matching coax feed antennas which need a little tweaking.

Using the BLT:

Note: The handle of the switch on the rear panel should be slanted towards the coax jack when using either a balanced line on the binding posts or just a coax feed antenna.

Before transmitting, adjust the TUNE and LOAD capacitors for best band noise or signal strength. Now switch from Operate to Tune mode with S7. Now transmit a string of dits or dahs and fine tune the TUNE and LOAD capacitors so that the SWR LED gets very dim. This of course, is easier said than done. The tuning is very sharp and if you tune too fast you will never see the LED get dim. A further complication is the Load and Tune controls are interactive.

First slowly adjust the LOAD until you see even the slightest dimming of the LED. Now adjust the TUNE and see if you can make it even dimmer. Go back to LOAD and see if this will dim the LED farther. If no farther improvement can be made, advance the TUNE slightly (try clockwise first) which will make the LED brighter again, then try the LOAD. Working back and forth a few time between the Tune and Load controls should enable you to make the LED become very dim or go out completely. In most cases when using a ladder line feed antenna, you will use the HI-Z setting of the BLT. In some cases, you may only be able to find a match using the Low-Z setting.

Once you find the match, you might want to mark the positions of the controls on the panel using some stick on dots. This will speed up retuning after switching bands.

Using the BLT with end feed wire antennas or coax.
Switching the handle of the rear panel switch so it faces the binding posts will ground the black balanced line binding post and connect the Red post to the coax jack. End feed wire antennas can now be connected to the Red binding post and a counter pose to the Black post. Use the High Z position of S9 if the wire is near a 1/2 wave in length. Use the Low Z position if the wire is near a ¼ wave or less in length. The Low Z position is also used when using the BLT to match a coax feed antenna.

Using a speaker instead of headphones:

The amount of current the audio amplifier can deliver to a speaker is limited by the current available from the 78L06 regulator. A small, efficient speaker at low or modest volume should be alright. However, it would be a good idea to use an amplified speaker such as those used for PC sound, as this would keep the load on the PFR audio amplifier to a minimum.

Also, since the PFR does not have AGC, be careful when using in-the-ear “ear bud” type headphones. Turn the volume control down when tuning across the band so that if you run across a strong station, it does not blow your ears off!

Paddle wiring:
The paddle jack uses “standard” wiring:

Tip is Dot
Ring is Dash
Sleeve is ground

There is no paddle sense reverse built into the firmware.

PFR front panel controls and rear panel connectors.

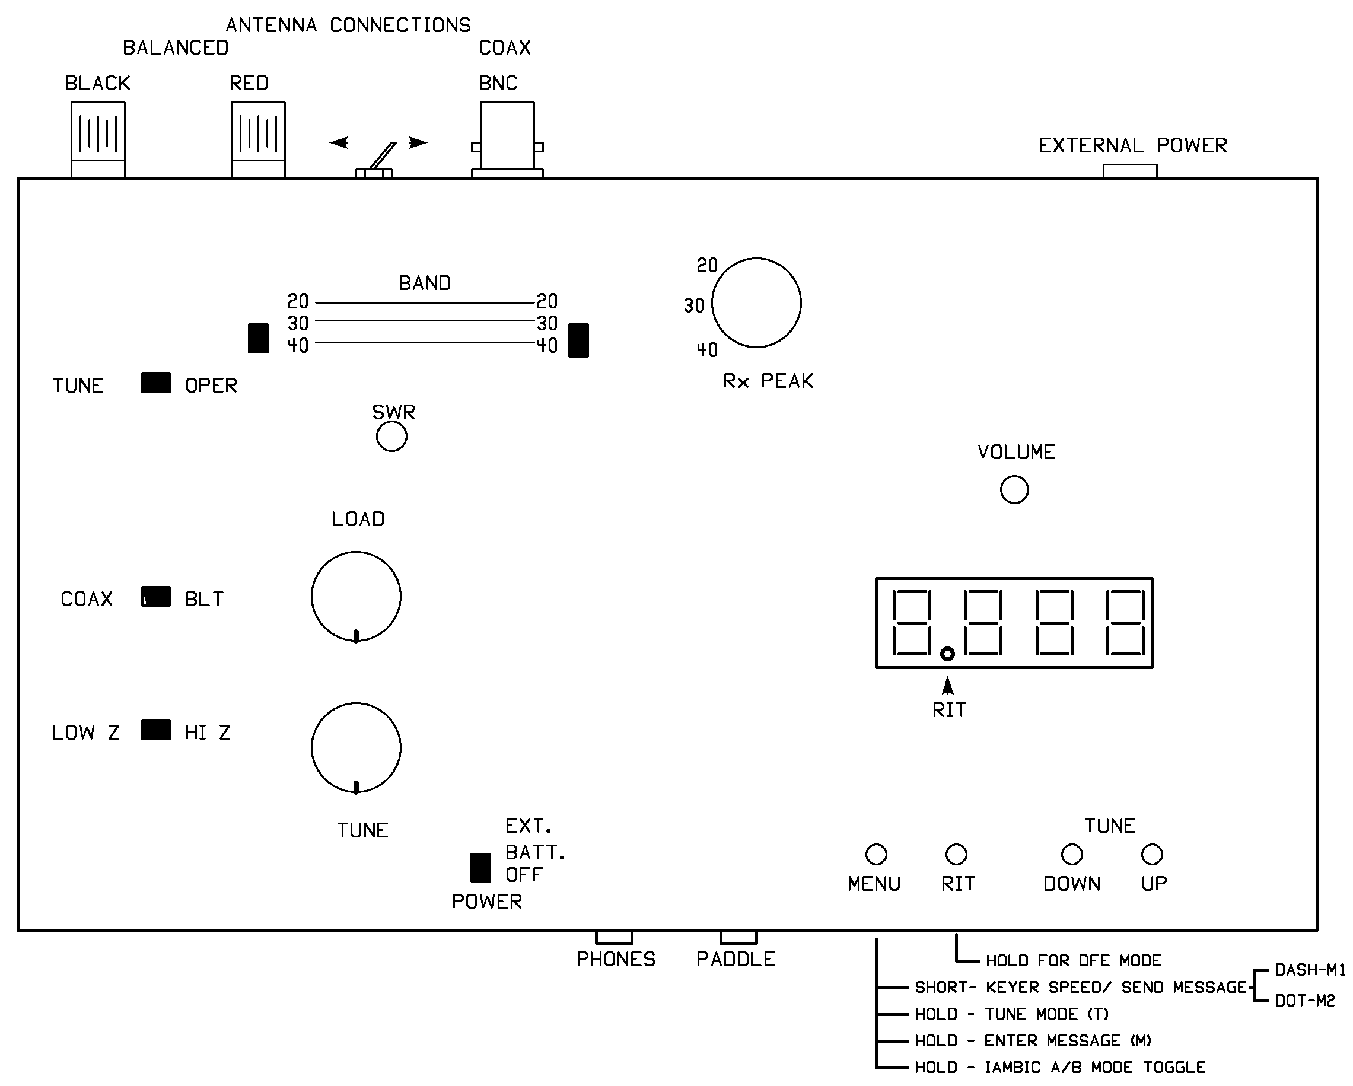
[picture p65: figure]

## Troubleshooting:

With careful assembly, your PRF-3 kit should work right off. Unfortunately, this is not always the case and some troubleshooting will be required. This job goes a lot quicker if you have a signal generator, Oscilloscope and frequency counter, but alas, most of you will only have a DVM to work with.

The most common reason a kit does not work is because of assembly errors, the most common being soldering issues. Soldering issues include missing solder connections, solder shorts between pads which are not connected together, not using enough heat in places so solder only sticks to a component lead and does not flow into the solder pad and not properly tining magnet wire leads so there is no continuity through a coil. Less common but still something to look for is miss-placed parts. It is often easy to miss-read the color codes on resistors, especially those with similar colors, but in a different order.

The above problems can often be found with a simple but careful visual inspection of the board. It does help to have an idea of which general area the problem maybe in as to narrow down the search.

Bad parts:
All new, prime parts are supplied with the kit. It is very, very unlikely any were bad prior to installation. Unless the part was physically damaged during assembly, it is safe to assume the part is good. However, some parts, in particular, the 2N7000 and BS170 MOSFETs can be damaged by static while handling and soldering. Some of the ICs can be damaged if they are installed backwards in the socket and power applied. However, since the regulators which supply voltage to the ICs have limited current capability and have over current shut down, it is quite likely the IC will survive being installed backwards.

## Troubleshooting steps: Divide and conquer

The best way to find out what doesn't work is to first find out what does work. The first step is to make sure proper power supply voltages are present. If the output of a regulator is lower than it should be and/or the package is getting hot, something is dragging the output down. This could be caused by one of the aluminum electrolytic capacitors being installed backwards, a solder short or an IC plugged in up side down.

The next step is to check the voltages on the IC pins. If one or more of these voltages are off significantly, it may not mean the IC is bad, but something is affecting the voltage on that pin. Before asking for a replacement part, check the parts connected to those pins and of course, the soldering in that area.

If you still have a problem, its time to start tracing the signal paths. For the receiver, it is easiest the start with the output and work towards the input. For the transmitter, start at the input and work towards the output.

Group 1, the processor and display:
There is very little go wrong here. If the processor is getting it's +5 supply, it should work. Although there could be problems with things connected to the various input and output pins which will affect it's operation. If there is a missing segment or digit on the display, it is likely there is a missing solder connection or short. The same is true if a paddle or the switches don't work or there is a “stuck switch” problem.

Group 2, the receiver:
The audio stages are very easy to test. You should hear some “hiss” when the volume control is turned all the way up and you should hear the side tone when using the paddles. You should be able to hear 60 cycle hum if you touch pins 4 and 5 of U2 with your fingers. If you hear the side tone but not any hiss or hum which touching pins 4 and 5 of U2, the mute switch Q4 might be shorted out. If the voltages on pins 3 and 5 of U3 are not correct, C24 might be in backwards or the R7 and R12 values interchanged.

The crystal filter and U2 product detector/ BFO oscillator is tested when using the DDS offset calibration mode. There is little to go wrong here other than soldering problems.

Still no luck getting the rig to work?

We will try to first help you via email. Sometimes we can nail the problem right off, but often it can be of no real help. We can't look over your shoulder to see whats going on and we're not psychic! Often, we can't do much more than repeat what has already been said in the above troubleshooting guide. To be of help we need as much information as possible about the problem. Simply saying that it does not work is of little use.

If all else fails, a repair service is available for a flat $35.00 fee. If you want the rig to be insured on return shipping, add another $5.00. DX stations will also have to add extra funds to cover air mail postage. It would be helpful if a short note explaining what kind of problem your having is included. We will try to repair and return the rig as quickly as possible, but it could take a few weeks in some cases, depending on other work loads from the day job.

Send the rig with a check or MO for the repair fee to:

Steven Weber, KD1JV
Steve's Electronics
633 Champlain St
Berlin, NH 03570

IC pin voltage charts: Small deviations from listed voltages acceptable due to DVM and voltage regulator tolerances

Note: LED display driver pin voltage vary with digits displayed so typical voltages not shown

IC U1, U2 SA612 mixer

Pin 1 | 1.4 V | IN
Pin 2 | 1.4 V | IN
Pin 3 | 0 V | GND
Pin 4 | 3.8 V | OUT
Pin 5 | 3.8 V | OUT
Pin 6 | 5.9 V | OSC
Pin 7 | 5.4 V | OSC
Pin 8 | 6.0 V | V+

IC U3 LM358 op amp

Pin 1 | 3.0 V | OUT
Pin 2 | 3.0 V | - IN
Pin 3 | 3.0 V | + IN
Pin 4 | 0 V | GND
Pin 5 | 3.0 V | + IN
Pin 6 | 3.0 V | - IN
Pin 7 | 3.0 V | OUT
Pin 8 | 6.0 V | V+

IC U4 LM386 audio amp

Pin 1 | 1.25 V | feedback
Pin 2 | 0 V | - IN
Pin 3 | 0 V | + IN
Pin 4 | 0 V | GND
Pin 5 | 2.9 V | OUT
Pin 6 | 6.0 V | V+
Pin 7 | 3.0 V | Bypass
Pin 8 | 1.25 V | feedback

## IC U6 MEGA 48 MPU processor

Rx | Tx | Pin function
Pin 1 | 5.0 V | 5.0V | reset
Pin 2 | 5.0 V | 5.0 V | DDS CLK
Pin 3 | 5.0 V | 5.0 V | DDS EN
Pin 4 | 5.0 V | 0 V | Paddle DOT in
Pin 5 | 5.0 V | 0 V | Paddle DASH in
Pin 6 | ------- | ------- | Digit 3
Pin 7 | 5.0 V | 5.0 V | Vcc
Pin 8 | 0 V | 0 V | GND
Pin 9 | -------- | -------- | Decimal point
Pin 10 | ------- | --------- | “d' segment
Pin 11 | -------- | --------- | Digit 1
Pin 12 | -------- | --------- | Digit 2
Pin 13 | -------- | --------- | Digit 4
Pin 14 | -------- | --------- | “e” segment
Pin 15 | -------- | --------- | “f” segment
Pin 16 | ---------- | --------- | “b” segment
Pin 17 | --------- | -------- | “g” segment
Pin 18 | --------- | -------- | “a' segment
Pin 19 | --------- | --------- | “e” segment
Pin 20 | 5.0 V | 5.0 V | AVcc
Pin 21 | 5.0 V | 5.0 V | Aref
Pin 22 | 0 V | 0 V | GND
Pin 23 | 5.0 V | 5.0 V | A/D switch input
Pin 24 | 2.5/1.5/.22 | Same | A/D Band input
Pin 25 | 0 V | 5.0 V | MUTE out
Pin 26 | 0 or 5 V | 2.5 V | Side tone out
Pin 27 | 0 V | 5.0 V | Tx enable
Pin 28 | 5 or 0 V | 5 or 0 V | DDS Data

## IC U8 74HC02 NOR GATE

Rx | Tx
Pin 1 | 0 V | 5V square wave | out
Pin 2 | 0 V | 0 V | in
Pin 3 | 3.5V | 3.5V square wave | in
Pin 4 | 5V | 5V | out
Pin 5 | 0V | 0V | in
Pin 6 | 0V | 0V | in
Pin 7 | 0V | 0V | GND
Pin 8 | 0V | 0V | in
Pin 9 | 0V | 0V | in
Pin 10 | 5V | 5V | out
Pin 11 | 3.5V | 3.5V square wave | in
Pin 12 | 0V | 0V | in
Pin 13 | 0V | 5V square wave | out
Pin 14 | 5.0 V | 5.0V | Vcc
Pins 1 and 13 will measure about 2.5 volts with DVM when transmitting steady carrier.

## Schematics:

## Receiver audio

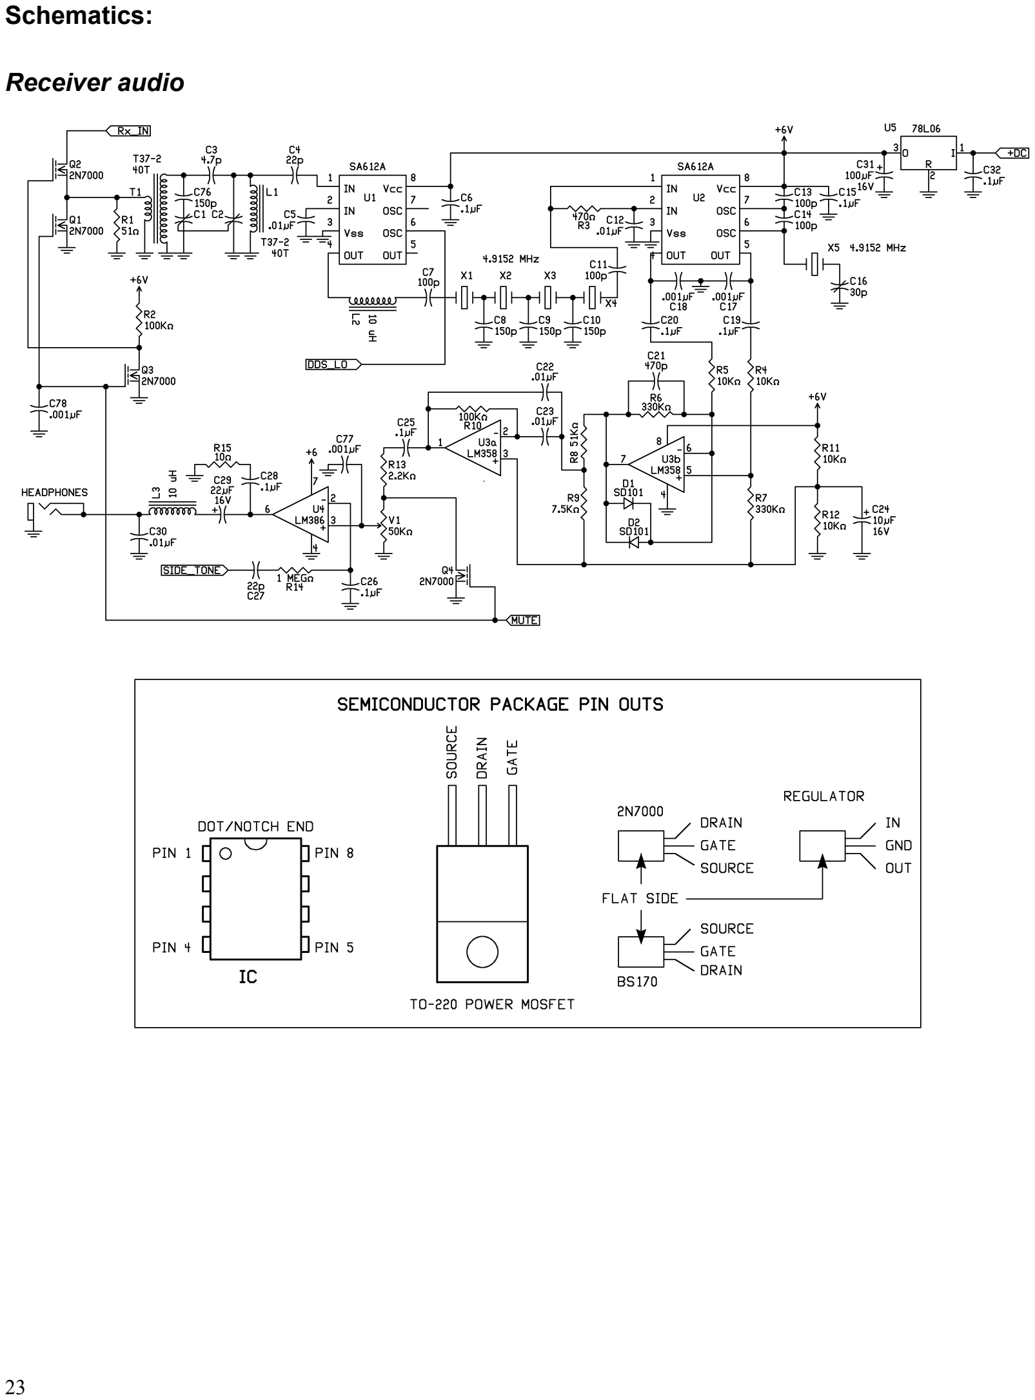
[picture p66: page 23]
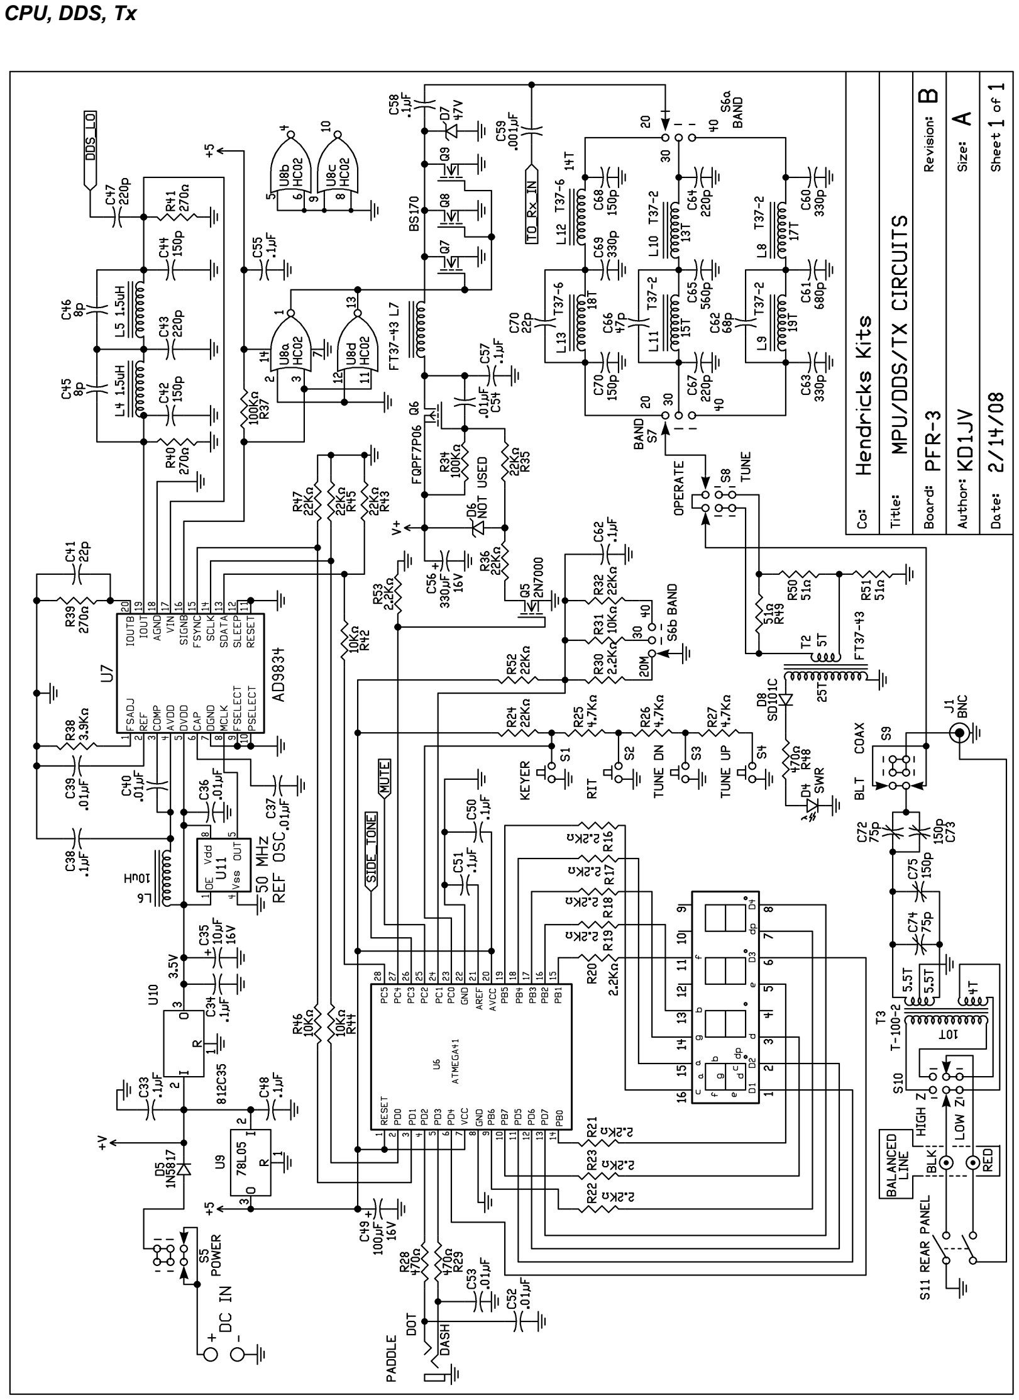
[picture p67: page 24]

CPU, DDS, Tx

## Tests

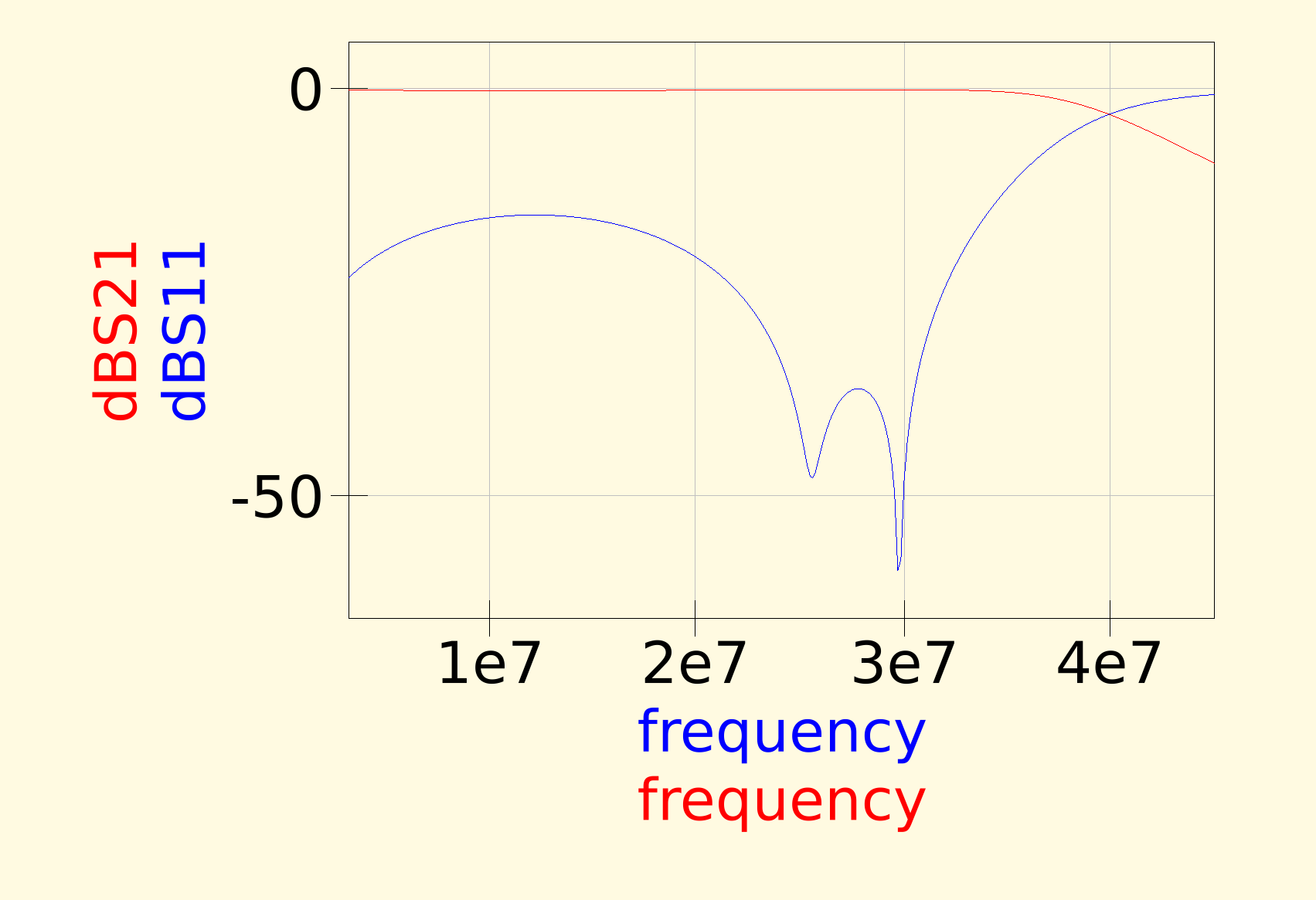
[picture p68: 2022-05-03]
Wider-LPF-QUCS/F2-Results.png

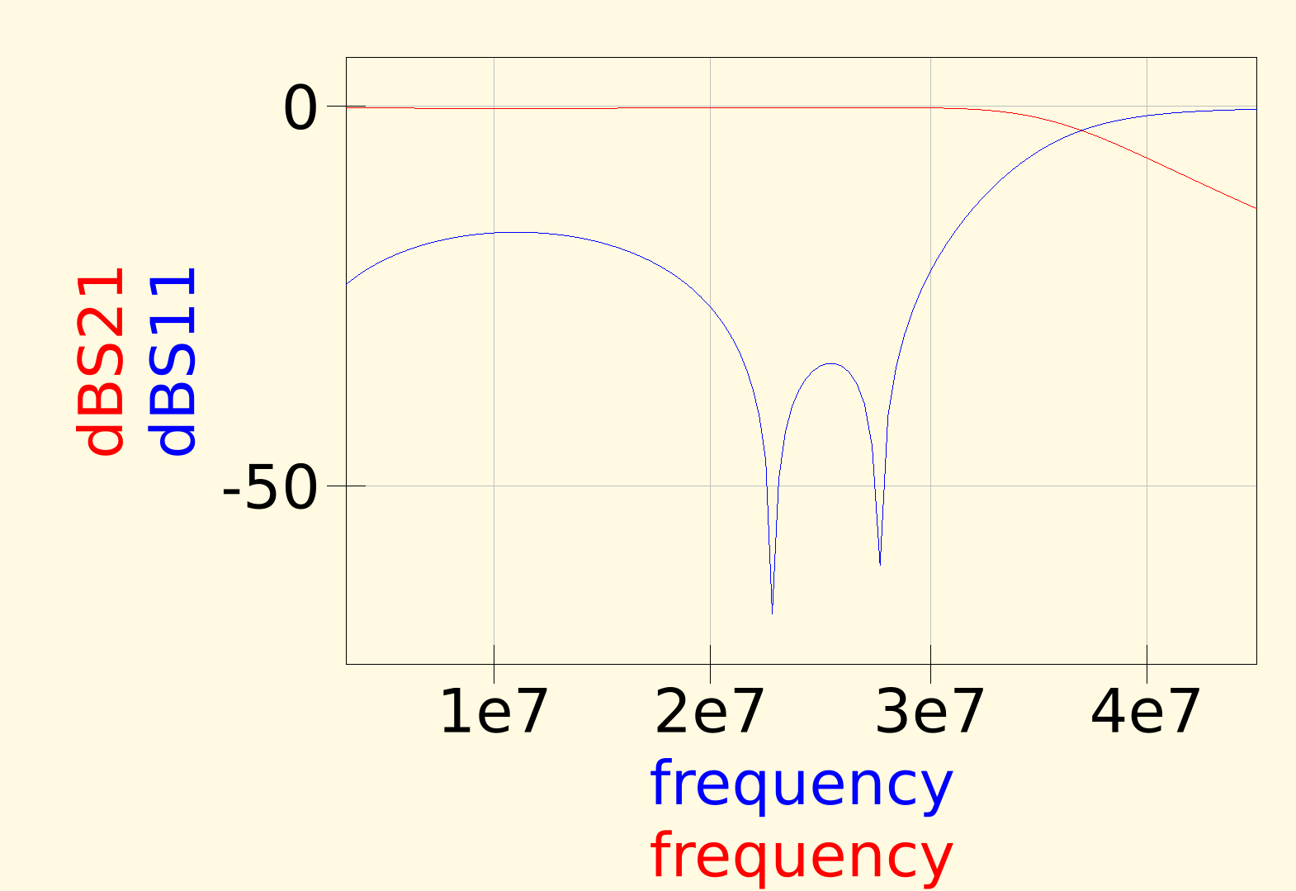
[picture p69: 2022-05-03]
Wider-LPF-QUCS/F1-Results.png

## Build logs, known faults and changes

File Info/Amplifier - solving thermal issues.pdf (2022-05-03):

thestone.zone (http://thestone.zone/radio/2021/01/14/capacitors.html)

## Amplifier - solving thermal issues

4-5 minutes

Last time, (http://thestone.zone/radio/2021/01/10/hellschreiber-transmit.html) my amplifier worked great. I did some testing on the air, got 8 watts of power out, etc. But one issue popped up – transmitting for a little while heated something up and produced some odd changes in power output and current consumption. With some gracious and patient help from some smart people, I’ve figured out what caused it, fixed it, and come out way ahead of where I thought I was!

### Describing the problem

When I would key up the transmitter, the power amplifier would produce 8W. But after 5 seconds it would hit 8.9W; after 10 seconds, 11.42W; and at 19.8 seconds 13.1W! Worse, though, shortly thereafter, power would drop to about 3 watts, with an increase in current consumption.

It was my understanding that it shouldn’t be thermal runaway, since I am using MOSFETs. But I couldn’t really find any articles or discussions that matched what I was seeing. So I posted on QRZ, (https://forums.qrz.com/index.php?threads/curious-thermal-behavior-in-amplifier.743786/) hoping the homebrew intelligentsia could help me out.

### Answers obtained!

Things started to make sense when I went through all the things that get hot when transmitting. The output transformer gets pretty warm; the low pass filters got similarly warm. But what got

Amplifier - solving thermal issues | about:reader?url=http%3A%2F%2Fthestone.zone%2Fr...
1 of 5 | 11/4/21, 14:08

really, really hot was the capacitors in the low pass filter…

The QRZ wizards suggested my capacitors were not spec’d for the voltage levels I was throwing at them, and probably not a type that’s ideal for RF. Since I just grabbed them out of a bulk pack I had sitting around (which doesn’t even include references or specs), that seemed like a pretty good working theory.

At the power levels I was seeing, voltage levels would be hitting 30-50v. So I needed to replace them with something better. Here is the “before” shot of the low pass filter:

And, since it will turn out to be relevant, my sweeps with the NanoVNA had shown somewhat lackluster performance (note the roughly 2.2 dB insertion loss!):

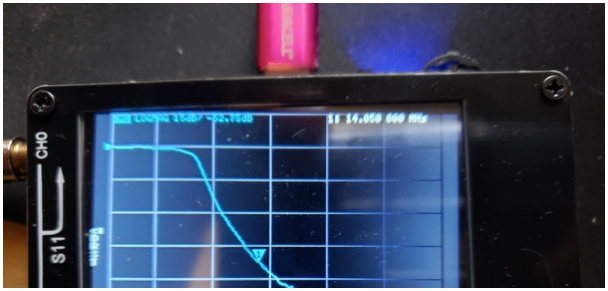
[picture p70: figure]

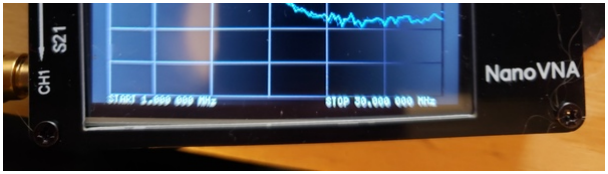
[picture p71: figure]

Apologies for the blurry image, it’s the only image I have from way back then!

### Pretty blue capacitors

I ordered some TDK caps (https://www.mouser.com/ProductDetail/810-FG24C0G2W102JNT6/) rated for 450v. They sure were expensive (as capacitors go), but the blue color looked nice. Mouser even upgraded my shipping to overnight, and they showed up the next day!

I removed the old yellow capacitors, and replaced them. Now the filter looks really snazzy:

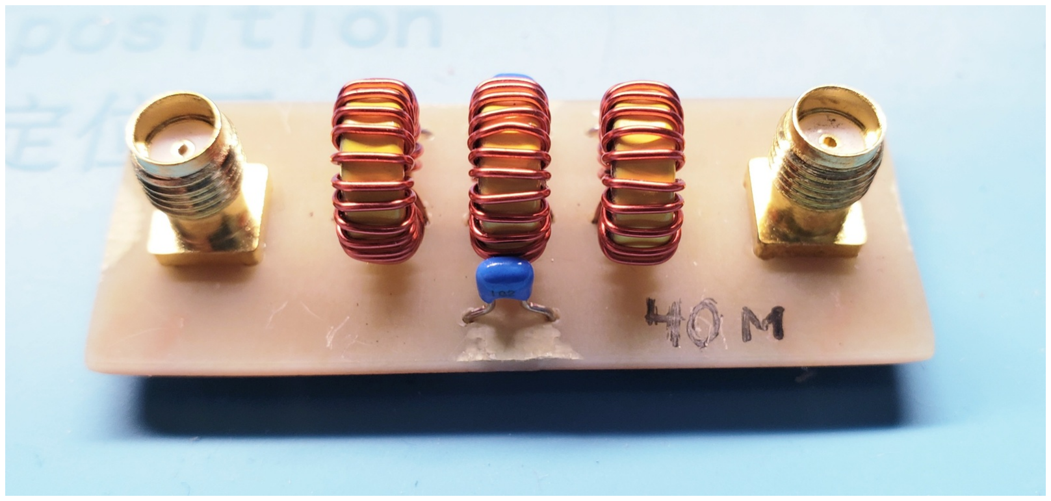
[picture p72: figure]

What was even more exciting was the VNA results. Only half a dB of loss at 7MHz, and a couple more dB down at the harmonics. The cutoff frequency moved up a bit, but not enough to be a problem. This is a useful experience for me – I’ll never use cheap capacitors in a filter again!

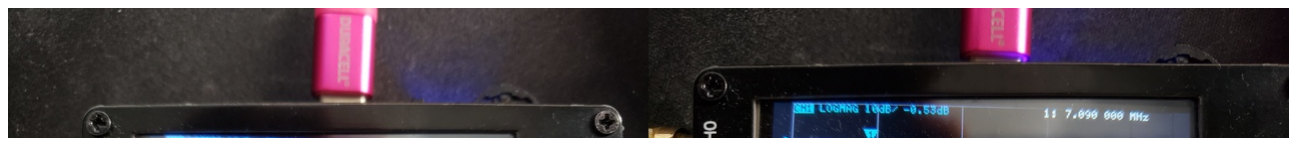
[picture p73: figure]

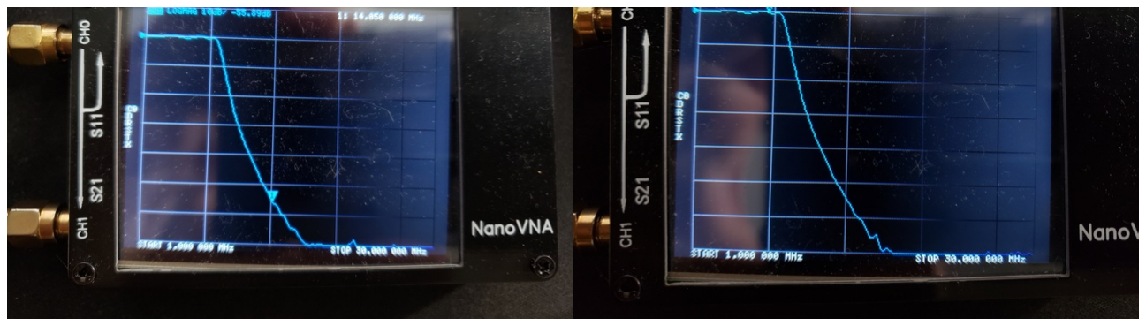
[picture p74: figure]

### Testing with the transmitter

So, with initial indications suggesting this is now a much nicer filter, I attached it inline with the transmitter, and fired it up. I was greeted with this beautiful result on the oscilloscope:

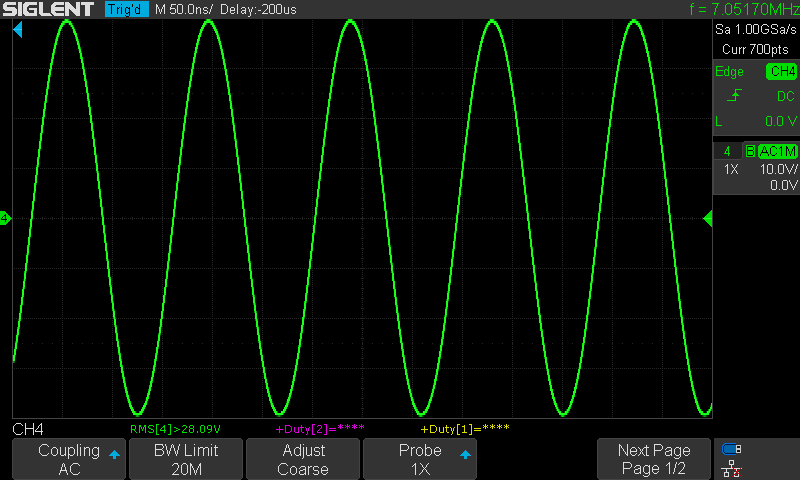
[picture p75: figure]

Just over 15 watts, and it was instant. No thermal variation – change over 30 seconds keyed up was less than 0.2 Vrms. I was so surprised initially, that I at first thought I’d left the dummy load disconnected. Nope, it was connected, and the measurement was real!

### Conclusions

I will pay much more attention to voltage ratings on capacitors. And I need to buy a stock of new ones that are more suitable for RF projects.

And my amplifier works a whole lot better than I thought it did. I just couldn’t see it because of the inadequate low pass filter.

This design is simple, hits a much higher power level than I ever really planned for in my future digital transceiver design. There are still a couple things worth playing with on this design, but it should work well for a full-suite transceiver.

Finally, the satisfaction of hunting down, learning some things, and solving an interesting problem is great. I’m especially thankful for some of the online community resources available to me. I don’t really have anyone local I can ask these kinds of questions, and the willingness of others who know so much more than me to answer my silly questions is wonderful.

Next time might be receiver stuff!

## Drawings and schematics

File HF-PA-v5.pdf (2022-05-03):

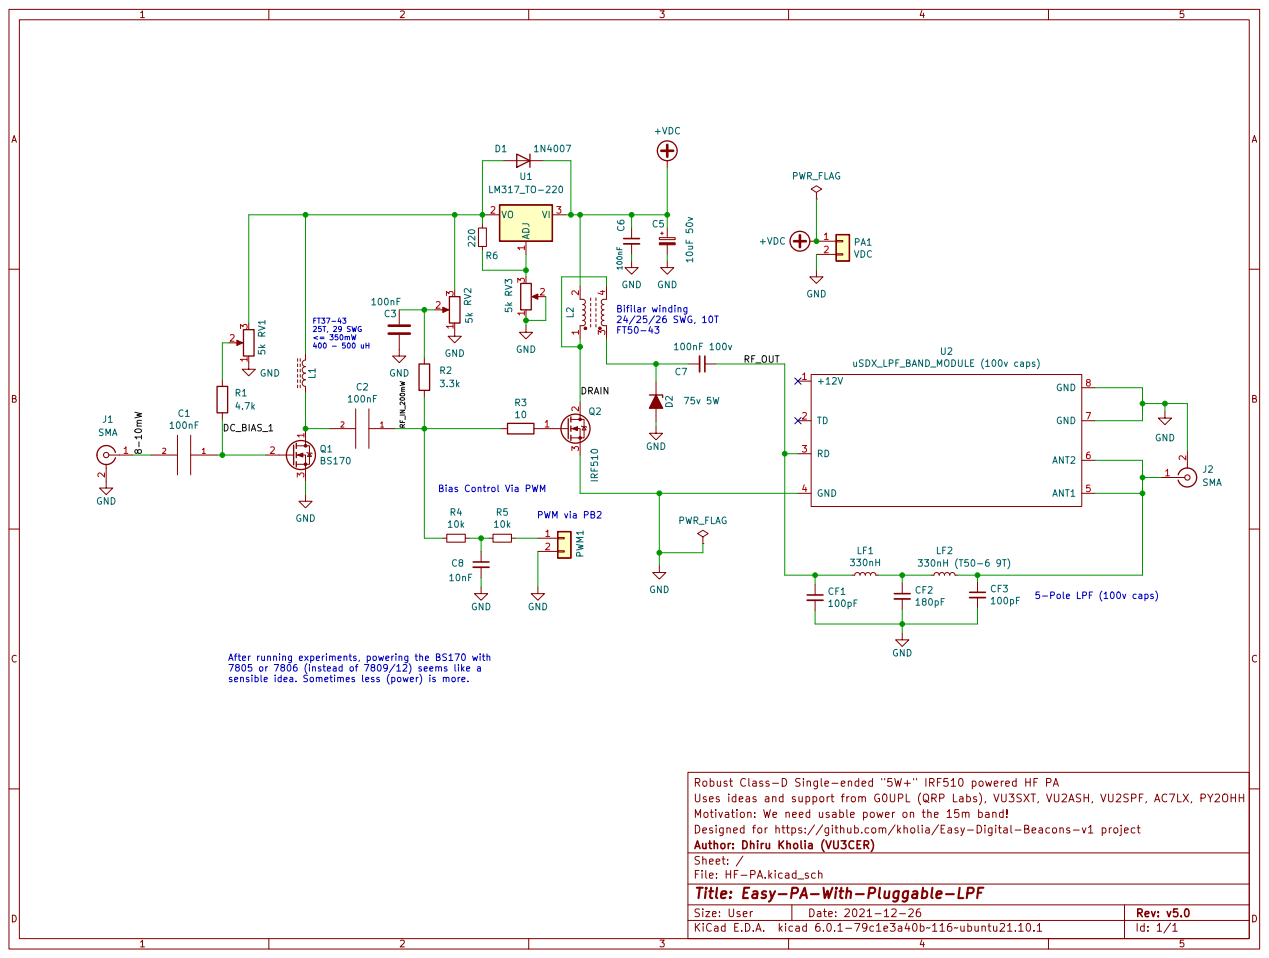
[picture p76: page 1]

FT50-43 After running experiments, powering the BS170 with

7805 or 7806 (instead of 7809/12) seems like a

Uses ideas and support from G0UPL (QRP Labs), VU3SXT, VU2ASH, VU2SPF, AC7LX, PY2OHH
Motivation: We need usable power on the 15m band!
Designed for https://github.com/kholia/Easy-Digital-Beacons-v1 project
File: HF-PA.kicad_sch Sheet: / Author: Dhiru Kholia (VU3CER)

Id: 1/1 Title: Easy-PA-With-Pluggable-LPF

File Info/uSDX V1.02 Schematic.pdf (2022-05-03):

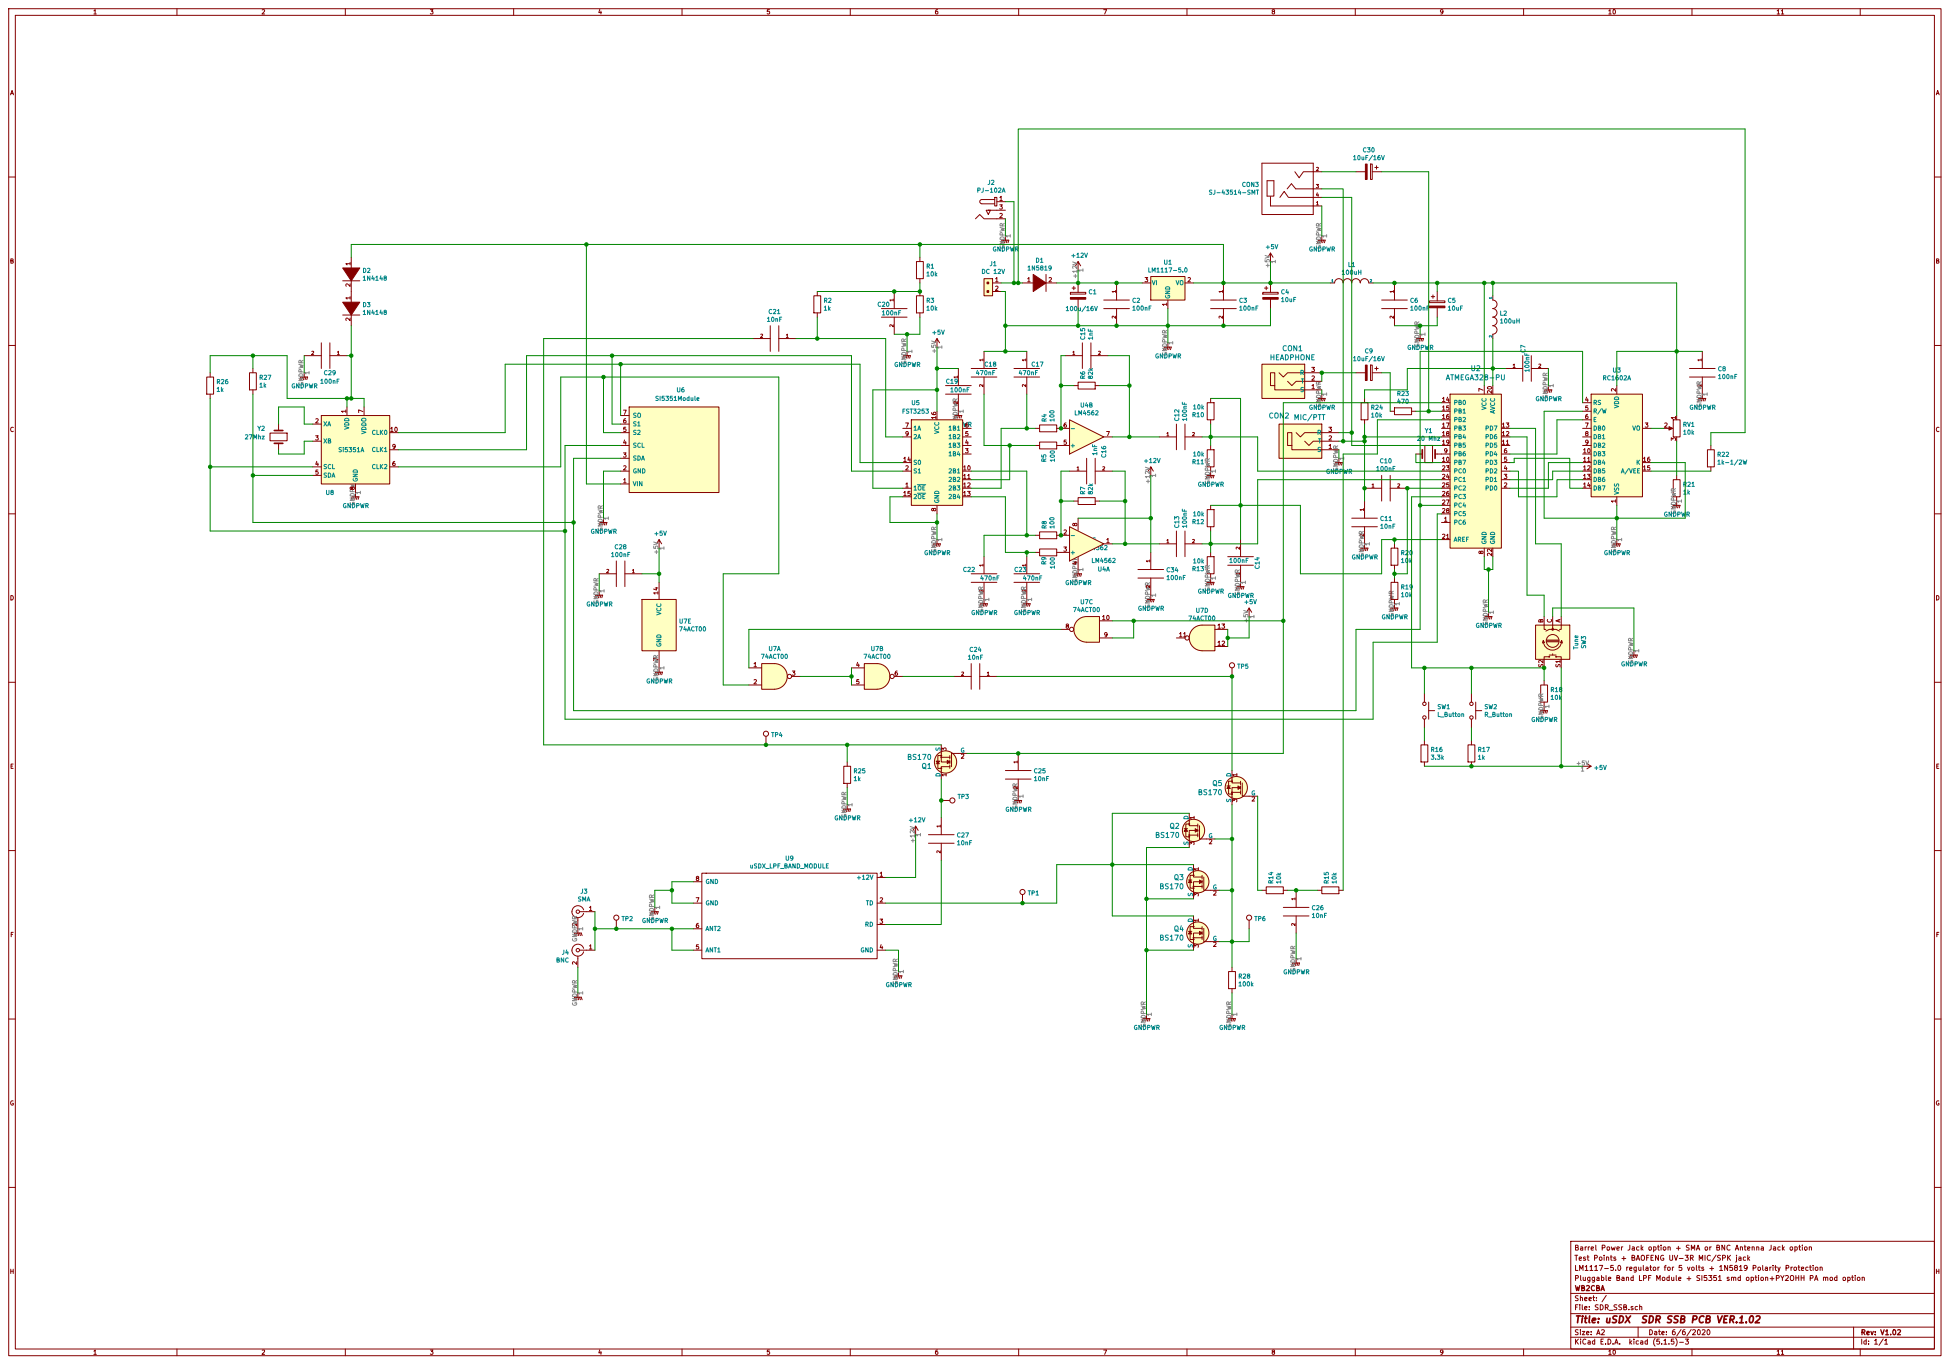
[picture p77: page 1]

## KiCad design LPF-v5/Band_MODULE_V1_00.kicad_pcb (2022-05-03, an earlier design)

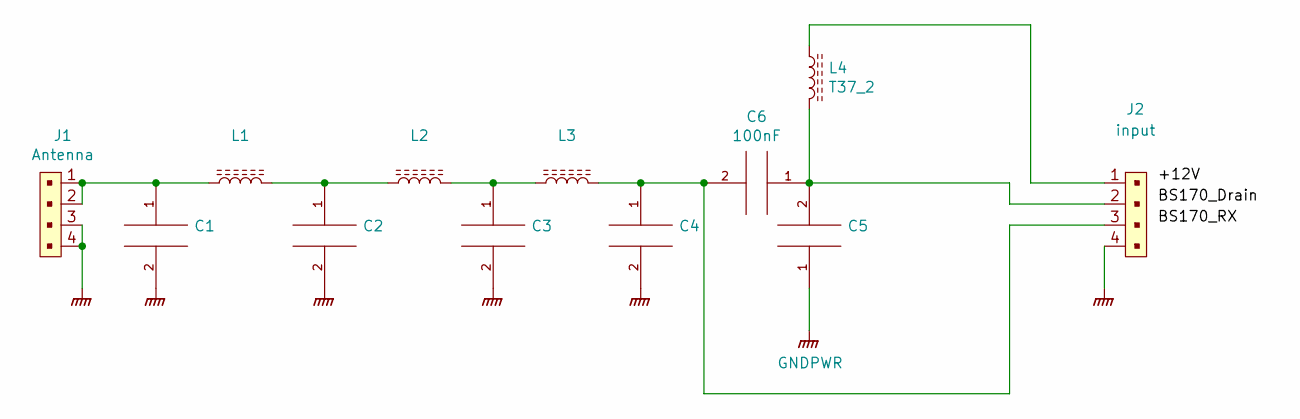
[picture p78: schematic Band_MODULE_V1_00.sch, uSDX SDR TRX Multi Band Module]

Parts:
C1, C2, C3, C4, C5: C_Disc_D5.0mm_W2.5mm_P2.50mm
C6: 100nF; C_Disc_D5.0mm_W2.5mm_P2.50mm
J1: Antenna; PinHeader_1x4_P2.54mm_Drill1.02mm; MPN 0022232041; Digi-Key_PN WM4202-ND
J2: input; PinHeader_1x4_P2.54mm_Drill1.02mm; MPN 0022232041; Digi-Key_PN WM4202-ND
L1, L2, L3: L_Toroid_Vertical_L10.0mm_W5.0mm_P5.08mm
L4: T37_2; L_Toroid_Vertical_L10.0mm_W5.0mm_P5.08mm

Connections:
GNDPWR: C1.2, C2.2, C3.2, C4.2, C5.1, J1.3, J1.4, J2.4
unnamed: C1.1, J1.1, J1.2, L1.1
unnamed: C2.1, L1.2, L2.1
unnamed: C3.1, L2.2, L3.1
unnamed: C4.1, C6.2, J2.3, L3.2
unnamed: C5.2, C6.1, J2.2, L4.2
unnamed: J2.1, L4.1

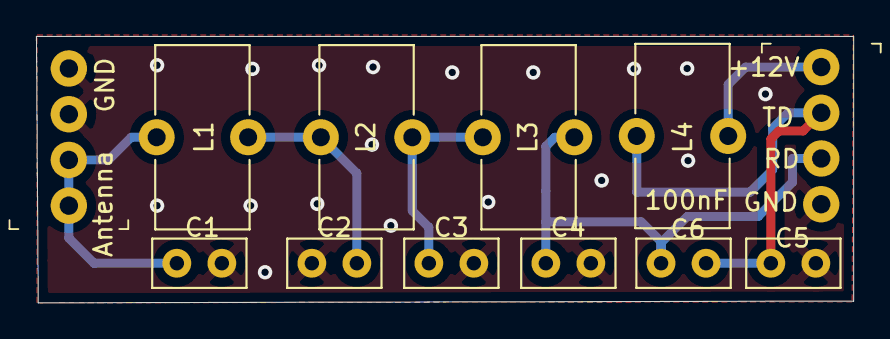
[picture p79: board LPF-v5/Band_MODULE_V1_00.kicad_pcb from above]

Board: 2 copper layers, 45.4 x 14.8 mm, 12 parts (0 on the bottom side), 7 nets.

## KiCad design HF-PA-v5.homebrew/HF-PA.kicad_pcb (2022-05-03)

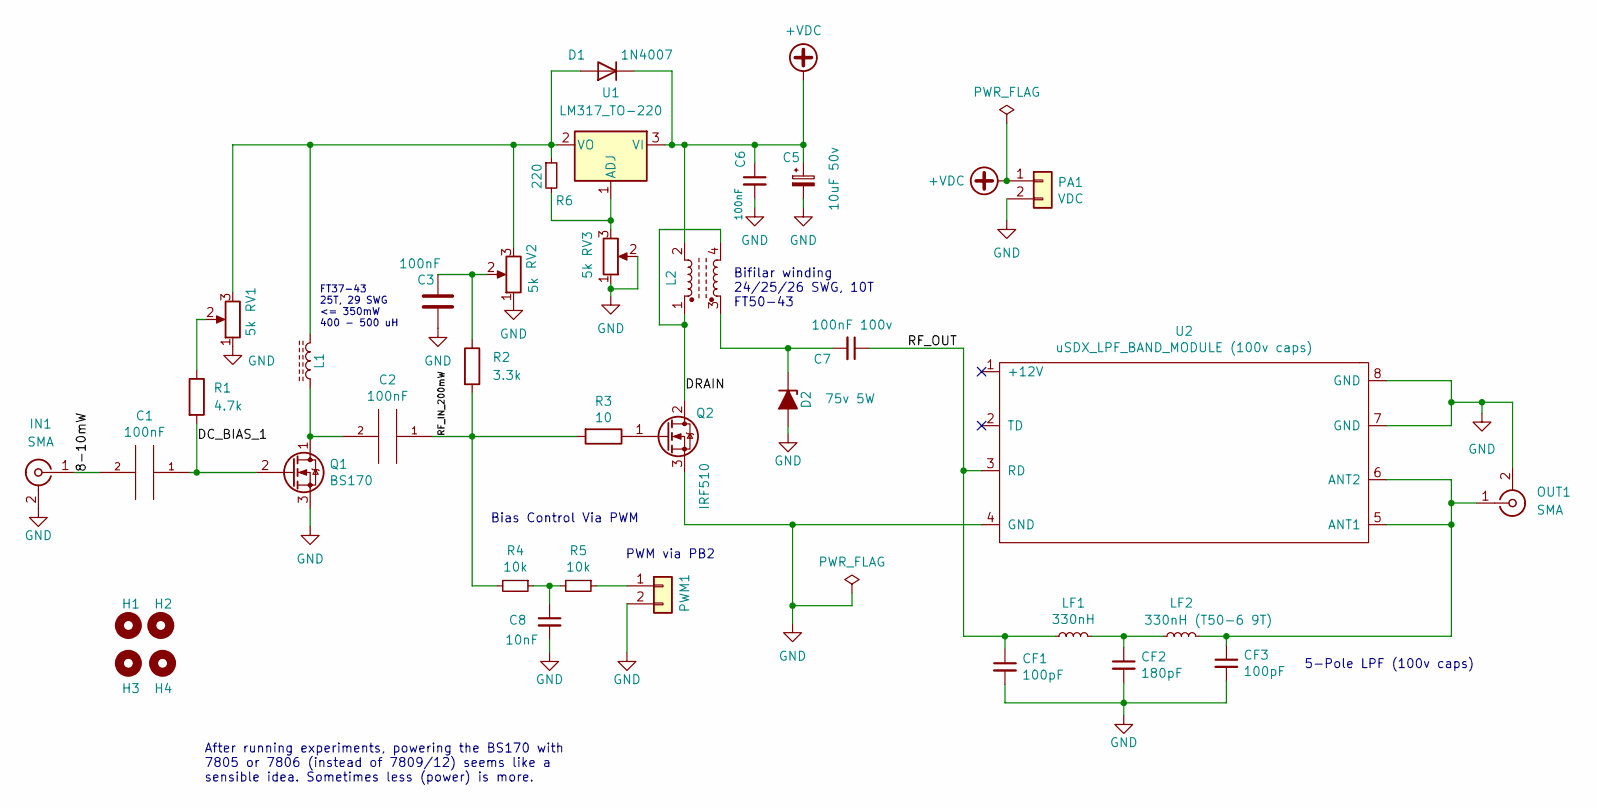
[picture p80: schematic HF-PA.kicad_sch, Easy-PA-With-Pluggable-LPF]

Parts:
C1, C2, C3, C6: 100nF; C_Disc_D4.3mm_W1.9mm_P5.00mm
C5: 10uF 50v; CP_Radial_D5.0mm_P2.50mm
C7: 100nF 100v; C_Disc_D4.3mm_W1.9mm_P5.00mm
C8: 10nF; C_Disc_D4.3mm_W1.9mm_P5.00mm
CF1, CF3: 100pF; C_Disc_D4.3mm_W1.9mm_P5.00mm
CF2: 180pF; C_Disc_D4.3mm_W1.9mm_P5.00mm
D1: 1N4007; D_DO-41_SOD81_P2.54mm_Vertical_KathodeUp
D2: 75v 5W; D_DO-201_P5.08mm_Vertical_AnodeUp
H1, H2, H3, H4: MountingHole; MountingHole_2.2mm_M2
IN1: SMA; SMA_Amphenol_901-144_Vertical
L1: L_Ferrite; L_Toroid_Vertical_L10.0mm_W5.0mm_P5.08mm
L2: L_Ferrite_Coupled; FT50-43 Transformer
LF1: 330nH; FT50-43 INDUCTOR
LF2: 330nH (T50-6 9T); FT50-43 INDUCTOR
OUT1: SMA; SMA_Amphenol_901-144_Vertical
PA1: VDC; PinHeader_1x02_P2.54mm_Vertical
PWM1: Conn_01x02; PinHeader_1x02_P2.54mm_Vertical
Q1: BS170; PinSocket_1x03_P2.54mm_Vertical
Q2: IRF510; TO-220-3_Vertical
R1: 4.7k; R_Axial_DIN0207_L6.3mm_D2.5mm_P2.54mm_Vertical
R2: 3.3k; R_Axial_DIN0207_L6.3mm_D2.5mm_P2.54mm_Vertical
R3: 10; R_Axial_DIN0204_L3.6mm_D1.6mm_P5.08mm_Horizontal
R4, R5: 10k; R_Axial_DIN0207_L6.3mm_D2.5mm_P2.54mm_Vertical
R6: 220; R_Axial_DIN0207_L6.3mm_D2.5mm_P2.54mm_Vertical
RV1, RV2, RV3: 5k; Potentiometer_Runtron_RM-065_Vertical
U1: LM317_TO-220; TO-220-3_Vertical
U2: uSDX_LPF_BAND_MODULE (100v caps); uSDX_LPF_Band_Module

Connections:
+VDC: C5.1, C6.1, D1.1 (K), L2.2, PA1.1, U1.3 (VI)
/8-10mW: C1.2, IN1.1 (In)
/DC_BIAS_1: C1.1, Q1.2 (G), R1.2
/DRAIN: L2.1, L2.4, Q2.2 (D)
/RF_IN_200mW: C2.1, R2.2, R3.2, R4.2
/RF_OUT: C7.1, CF1.1, LF1.1, U2.3 (RD)
GND: C3.2, C5.2, C6.2, C8.2, CF1.2, CF2.2, CF3.2, D2.2 (A), IN1.2 (Ext), OUT1.2 (Ext), PA1.2, PWM1.2, Q1.3 (S), Q2.3 (S), RV1.1, RV2.1, RV3.1, RV3.2, U2.4 (GND), U2.7 (GND), U2.8 (GND)
unnamed: C2.2, L1.1, Q1.1 (D)
unnamed: C3.1, R2.1, RV2.2
unnamed: C7.2, D2.1 (K), L2.3
unnamed: C8.1, R4.1, R5.2
unnamed: CF2.1, LF1.2, LF2.1
unnamed: CF3.1, LF2.2, OUT1.1 (In), U2.5 (ANT1), U2.6 (ANT2)
unnamed: D1.2 (A), L1.2, R6.1, RV1.3, RV2.3, U1.2 (VO)
unnamed: PWM1.1, R5.1
unnamed: Q2.1 (G), R3.1
unnamed: R1.1, RV1.2
unnamed: R6.2, RV3.3, U1.1 (ADJ)

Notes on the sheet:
After running experiments, powering the BS170 with 7805 or 7806 (instead of 7809/12) seems like a sensible idea. Sometimes less (power) is more.
Bifilar winding 24/25/26 SWG, 10T FT50-43
FT37-43 25T, 29 SWG <= 350mW 400 - 500 uH
5-Pole LPF (100v caps)
Bias Control Via PWM
PWM via PB2

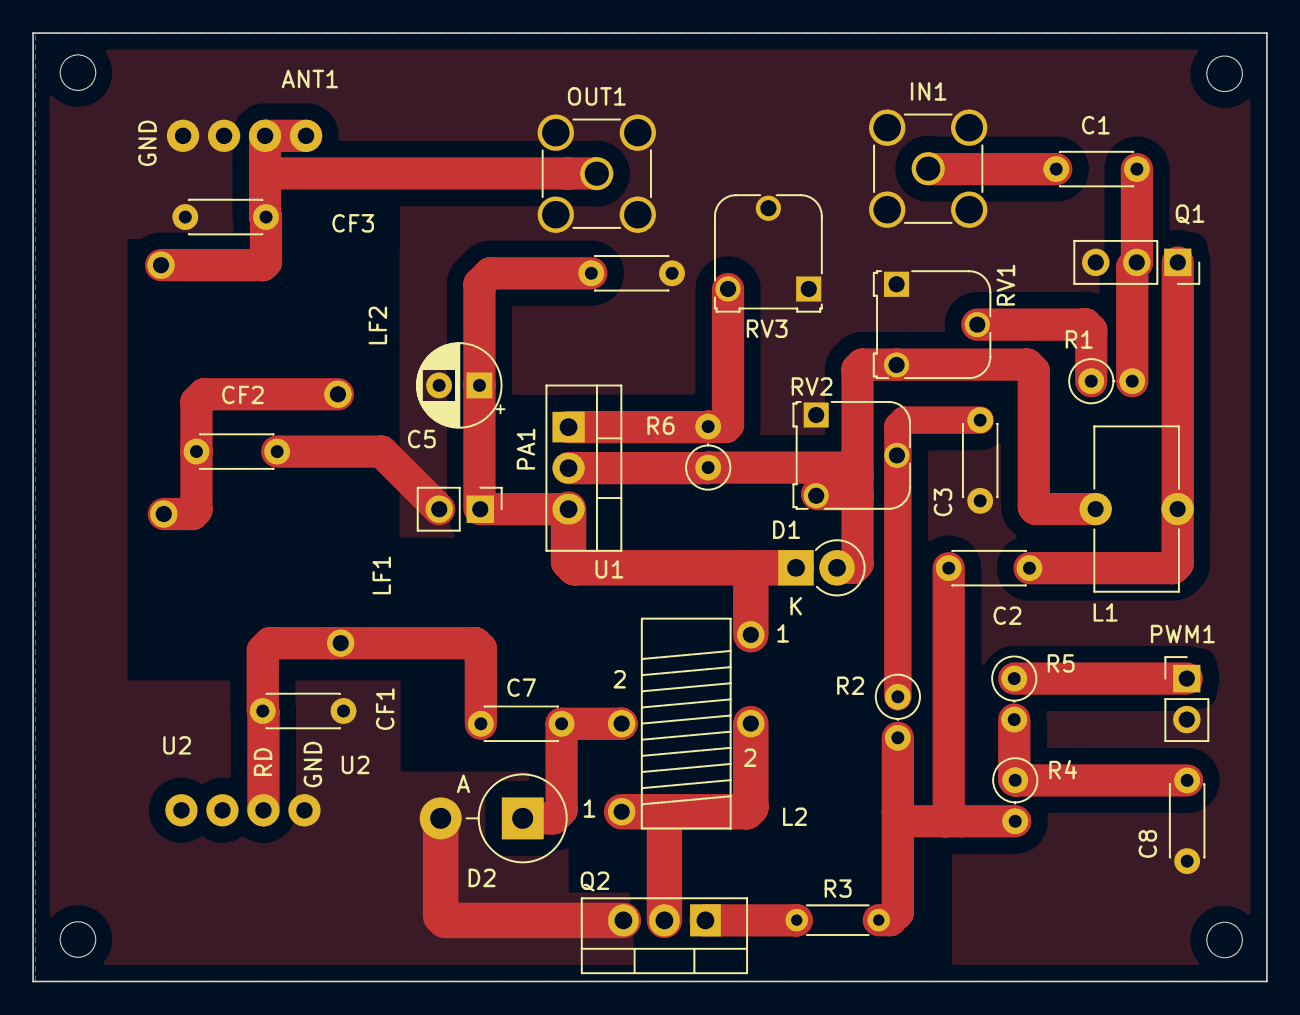
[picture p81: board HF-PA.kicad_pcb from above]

Board: 2 copper layers, 76.4 x 58.8 mm, 37 parts (0 on the bottom side), 18 nets.

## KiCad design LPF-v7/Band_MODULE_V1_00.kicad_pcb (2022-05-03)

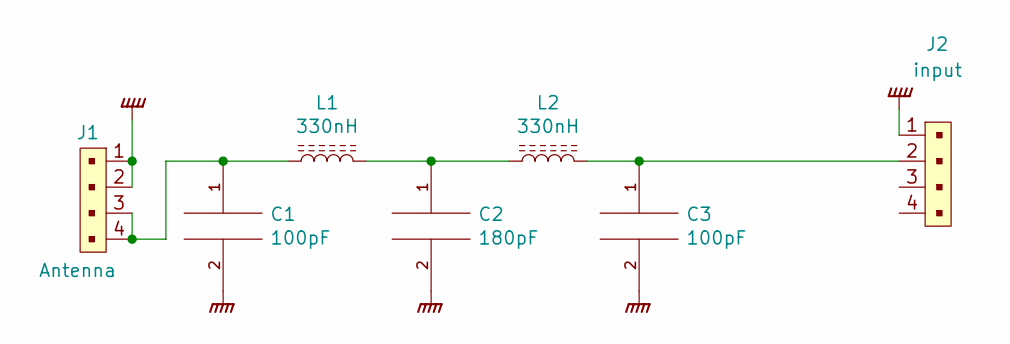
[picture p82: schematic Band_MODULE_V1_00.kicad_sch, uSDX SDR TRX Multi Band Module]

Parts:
C1, C3: 100pF; C_Disc_D5.0mm_W2.5mm_P2.50mm
C2: 180pF; C_Disc_D5.0mm_W2.5mm_P2.50mm
J1: Antenna; PinHeader_1x4_P2.54mm_Drill1.02mm; MPN 0022232041; Digi-Key_PN WM4202-ND
J2: input; PinHeader_1x4_P2.54mm_Drill1.02mm; MPN 0022232041; Digi-Key_PN WM4202-ND
L1, L2: 330nH; L_Toroid_Vertical_L10.0mm_W5.0mm_P5.08mm

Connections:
GNDPWR: C1.2, C2.2, C3.2, J1.1, J1.2, J2.1
unnamed: C1.1, J1.3, J1.4, L1.1
unnamed: C2.1, L1.2, L2.1
unnamed: C3.1, J2.2, L2.2

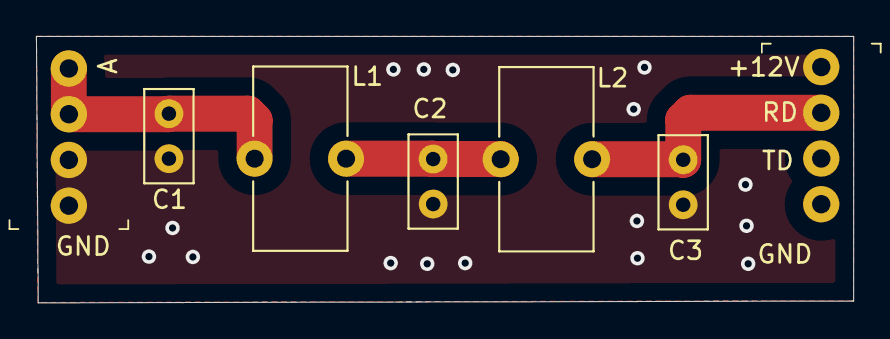
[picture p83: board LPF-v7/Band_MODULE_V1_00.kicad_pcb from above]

Board: 2 copper layers, 45.4 x 14.8 mm, 7 parts (0 on the bottom side), 4 nets.
